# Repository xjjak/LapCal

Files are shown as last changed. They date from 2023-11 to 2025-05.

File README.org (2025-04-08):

[[http://creativecommons.org/licenses/by-nc-sa/4.0/][https://img.shields.io/badge/License-CC%20BY--NC--SA%204.0-lightgrey.svg]]
* LapCal
/by Emil² - Ξ/

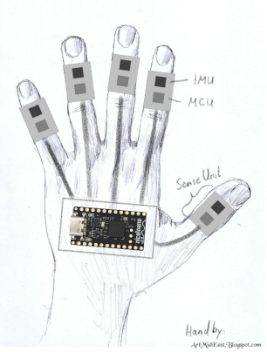
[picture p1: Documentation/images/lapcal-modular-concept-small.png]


We are trying to build data gloves, that enable typing on a 34-key keyboard, without an actual keyboard, based on 6-axis IMU sensors, using machine learning.

** Structure

#+begin_example
LapCal/
├─ Software/
│  ├─ data-collection.org
│  ├─ *machine-learning.org*
├─ Documentation/
├─ Utilities/
│  ├─ keyboard-visualization/
├─ Hardware/
│  ├─ Firmware/
│  ├─ Electronics/
#+end_example

Because we are both Emacs users, we pivoted to writing our READMEs in org-mode, as well as using org-babel for literate programming, to replace jupyter notebooks. More specific documentation can be found in [[/Software/README.org][this README]].

** Approaches
*** Unified Processing
First, we tried to connect all 6 IMUs to the same main-processor, an ESP32. This delivered a mediocre read-out frequency of about 10Hz at best. Collecting data was never done properly using this approach due to trying to use timestamps to sync the sensor and some sort of keyboard state data.

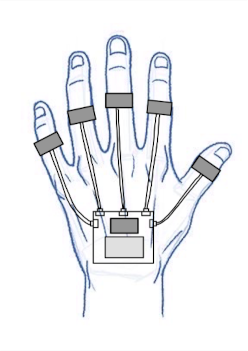
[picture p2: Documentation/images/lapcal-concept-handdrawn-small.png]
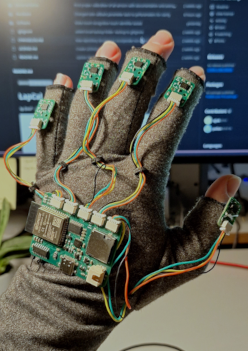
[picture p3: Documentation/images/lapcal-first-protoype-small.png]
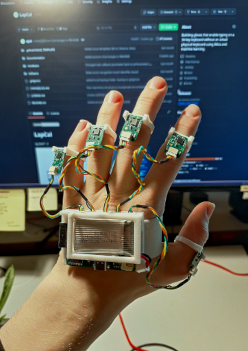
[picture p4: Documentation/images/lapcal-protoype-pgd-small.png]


*** /Now/: Modular
To simplify the problem, and offload computation at the same time, we are now using the constraints of the 34-keyboard, almost forcing each finger to a specific set of keys, and are trying to develop a model that only takes the data of a single finger and maps it to its respective keys. This would then also enable the use of an upgraded version of the SenseUnit (small PCBs with the IMUs on them that are attached to the fingers) with a dedicated processor on them, like an RP2040, perhaps. The mainboard could then be built around a standard keyboard MCU, that is usually used in mechanical keyboards.

** Licensing:

This work is licensed under a
[[http://creativecommons.org/licenses/by-nc-sa/4.0/][Creative Commons Attribution-NonCommercial-ShareAlike 4.0 International License]].

[[http://creativecommons.org/licenses/by-nc-sa/4.0/][https://licensebuttons.net/l/by-nc-sa/4.0/88x31.png]]

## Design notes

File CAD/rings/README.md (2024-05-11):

# Rings for the Partial Glove Design Version

This folder contains the OpenSCAD files for the parametric rings with which the SenseUnits are
attached to the finger.

This implementation utilizes the library [Round-Anything by Irev-Dev](https://github.com/Irev-Dev/Round-Anything).

## Parameters
Available in the code itself or the customizer in OpenSCAD are the following parameters:
- `thumb_dia`: The diameter of the Thumb finger ring
- `index_dia`: The diameter of the Index finger ring
- `middle_dia`: The diameter of the Middle finger ring
- `ring_dia`: The diameter of the Ring finger ring
- `pinky_dia`: The diameter of the Pinky ring
- `thumb hole width`: The angle of the thumb hole
- `thumb hole angle`: The angle which the thumb hole is set off by

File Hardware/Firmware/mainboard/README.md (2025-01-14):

# Mainboard firmware

## Build flags
- `RIGHT_HAND`: Set to `1` to reverse sensor order for right hand, `0` for the left hand. Throws error if not specified
- `MULT_CORE`: Set to `0` to disable parallel buffer resets, `1` to enable. Defaults to `1`.
- `BLE`: Set to `0` to output sensor data to Serial Monitor, `1` enables ble server and data transmission (Requires MULT_CORE=0)

## Setting build flags
### PlatformIO environments
The easiest method (and safest) is using the available pio environments:
- `left` / `right` : Data is printed to serial monitor (MULT_CORE=0)
- `left-ble` / `right-ble` : (BLE=1 MULT_CORE=0)
by using `pio run -e [left/right/left-ble/right-ble]`.
Defaults to `left` when `-e` is omitted.

*(left/right refers to the targeted hand)*

###  Environment variable override
To customize build flags when needed, prepend something like:
`PLATFORMIO_BUILD_FLAGS="-DMULT_CORE=[0/1] -DBLE=[0/1] -DRIGHT_HAND=[0/1]`
to a pio run command.
Any Flag that can stay the same as in the environment can be omitted.
This should override potentially differing flags set in the environment.

## BLE Server 
When BLE is enabled the ESP32 acts as an BLE Server providing
- Service with uuid: `f5aea478-9ec3-4bcf-af20-7f75e7c68c9d`
- Characteristic with uuid: `68bf07fb-d00b-4c80-a796-f8be82b5dea`

The name the device will show up under depends on the hand:
- left: `lapcal left`
- right: `lapcal right`

The data is in a binary format:
- timestamp: `uint64_t`
- Values: `int16_t` for each value of each sensor (36) 
  *caution: signed integer*
  
Use with the ble-receiver script found in the `Software/tools` folder.

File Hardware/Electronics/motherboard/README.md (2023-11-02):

### Libraries 
 - https://www.snapeda.com/parts/TCA9548APWR/Texas%20Instruments/view-part/?welcome=home
 - https://github.com/espressif/arduino-esp32/tree/master/libraries/SD

### Knowledge
 - https://hackaday.com/2017/05/18/kicad-best-practises-library-management/
 - https://esp32.com/viewtopic.php?t=356
 - https://www.esp32.com/viewtopic.php?t=1948
 - https://randomnerdtutorials.com/esp32-pinout-reference-gpios/
 - https://www.reddit.com/r/KiCad/comments/bnsbrr/flat_solder_pad_footprint_not_drilled/ -> These types of pads are called "Test Points"
 - Differential pairs: - https://resources.altium.com/p/what-are-differential-pairs-and-differential-signals
                       - Tips and "examples": https://electronics.stackexchange.com/questions/540263/routing-usb-3-x-type-c-signals
 - How to handle thermal pad on esp32: https://esp32.com/viewtopic.php?t=1864
 - 

### Models
- https://grabcad.com/library/hro-usb-type-c-31-m-14-1

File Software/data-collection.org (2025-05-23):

#+title: Data Collection and Preprocessing

#+property: header-args:jupyter-python :session *jupyter* :eval no-export
#+OPTIONS: ^:nil h:6

This document describes all software related to data collection, when possible in a literate programming style.

Except for the [[*A Brief Description of Our Data][first chapter]] -- a broad descrpition of how our data will look for all datasets -- and the [[*The Data Collection Process][second chapter]] -- a description of the general collection process --, the chapters are organized by dataset type. Each dataset type chapter includes all relevant
- descriptions and design choices,
- software to collect the relevant data, and
- processing capabilities to convert raw data into refined datasets.

Notably, the dataset types mostly vary by how we collect the [[*Labels][labels]].

* Contents                                                         :noexport:
:PROPERTIES:
:TOC:      :include all :ignore (this)
:END:

# TOC automattically generated by [[https://github.com/alphapapa/org-make-toc]]
# NOTE: These links will *only* work on github.
:CONTENTS:
- [[#a-brief-description-of-our-data][A Brief Description of Our Data]]
  - [[#features][Features]]
  - [[#labels][Labels]]
- [[#the-data-collection-process][The Data Collection Process]]
- [[#collecting-data][Collecting Data]]
  - [[#capturing-keypresses-directly-from-the-keyboard][Capturing Keypresses Directly from the Keyboard]]
    - [[#description][Description]]
      - [[#raw-data][Raw Data]]
      - [[#dataset][Dataset]]
    - [[#keypresses-directly-from-the-keyboard][Keypresses Directly from the Keyboard]]
    - [[#rectify-errors][Rectify Errors]]
      - [[#find-errors][Find Errors]]
      - [[#fix-errors][Fix Errors]]
    - [[#a-look-at-the-data][A Look at the Data]]
    - [[#center-the-data][Center the Data]]
      - [[#a-visual-comparison-to-the-uncentered-data][A Visual Comparison to the Uncentered Data]]
      - [[#save-data][Save Data]]
    - [[#aggregate-features-and-labels][Aggregate Features and Labels]]
      - [[#features][Features]]
        - [[#change-based-features][Change-based Features]]
        - [[#history-based-features][History-based Features]]
      - [[#labels][Labels]]
    - [[#write-dataset][Write Dataset]]
:END:

* A Brief Description of Our Data
Before we start describing the software that is used in the data collection process, we first want to give a quick overview of what our data actually consist of and where it comes from.

The data we collect can broadly be divided into two categories, since we use supervised learning:
1. The [[*Features][features]] our model takes as input. These are necessary during training and deployment of the model.
2. The [[*Labels][labels]] our model produces as output. These are only necessary during training. During deployment the model itself will produce predictions for them.

** Features
The features are generated using the hardware developed in [[file:../Hardware][other parts of the project]] in a more or less straightforward. While the specifics might change, in general the data will always come from [[https://en.wikipedia.org/wiki/Inertial_measurement_unit][inertial measurement units]] on the fingers and the back of the hand. The IMUs we currently use (MPU6050) give us information about their current acceleration in all three spatial dimensions as well as their rotation, that is, yaw, pitch, and roll.

In some cases the data will be explicitly limited to a subset of all the available sensors, most prominently to just one sensor.

Further, we need to convert our sequential data into features that encapsulate temporal changes. For example, one option would be to concatenate a set number of successive data points into one feature, like a [[https://www.geeksforgeeks.org/window-sliding-technique/][sliding window]].

# TODO: why here and not in machine-learning.org?
#   avoid high volatility of datasets in machine-learning.org since
#   models can be sensitive to changes in dataset architecture.

** Labels
The labels we assign to our collected features, represent some kind of typing state. A typing state considers every physical key on a [[https://github.com/davidphilipbarr/Sweep][keyboard]] separately. But what a typing state associates to a key can differ depending on the use case:
- in some cases, we just collect whether keys were changed from an unpressed to a pressed state, (states: =UNCHANGED=, =PRESS=, =RElEASE=)
- in other cases, we collect the state of the keys themselves, that is, whether they are pressed or not. (states: =UNPRESSED=, =PRESSED=)

It is important to note that feature labels are /not necessarily unique/ and labelling should be done with caution to avoid issues arising from feature representation like the following: When using a sliding window and not careful when labelling, a single key press can cause a model recognizing press and release events fire twice. An example for a sliding window with size 5 might look like the following for two consecutive model inputs:
  #+begin_example
  [ 5  4  3  2  1 ] => Prediction: PRESS event
       ^            <- key press event
       
  [ 6  5  4  3  2 ] => Prediction: PRESS event
          ^         <- key press event
  #+end_example

Often, we only consider a subset of all possible key on our [[https://github.com/davidphilipbarr/Sweep][keyboard]], like for example only keys reachable by a certain finger or only one half of the keyboard. The reason for doing so is usually the assumption that the labels can be partitioned in such a way that different models can separately predict events independently from one another. Analogously, for some datasets we leave some features out since we assume that they don't affect the subset of labels we look at.

For some experiments, it could also be interesting to further simplify certain models, e.g. no differentiation between different keys pressed by a key, but these are *not accounted* for in this document since they are usually quick modifications that mostly serve experimental purposes.

* TODO The Data Collection Process
/This section is currently empty. In the future some general approaches to data collection might be listed here./

# TODO: python version + package management

* Collecting Data
This is the main part of this document. In this chapter, the [[*The Data Collection Process][general process]] for collecting data is adapted to our specific needs resulting in the actual datasets.

** TODO Capturing Keypresses Directly from the Keyboard
:PROPERTIES:
:header-args:jupyter-python: :async yes :session *jupyter-keyboard-direct*
:END:
*WARNING*: For the moment, this chapter /only describes data pertaining quick taps/, explicitly /excluding the handling of hold events/ and as such press and release events.

#+begin_src jupyter-python :results silent
  import pandas as pd
  import numpy as np
  from pathlib import Path
  data_path = Path("_datasets/2025-01-15_controlled-taps")
  
  import matplotlib.pyplot as plt
  %matplotlib inline
#+end_src

# TODO: raw data or dataset files?
Dataset files:

*** Description
***** Raw Data
  File: [[file:_datasets/2025-01-15_controlled-taps.csv][2025-01-15_controlled-taps.csv]] (4.6Mb, 151471 lines, semicolon separated)
  
  Data was recorded by [[https://github.com/xjjak/][@xjjak]] on <2025-01-15 Wed> over a time of around 10 minutes using sensor #I [fn::#I refers to the physical label of the used sensor.] with the following calibration offsets ={-6018, 1394, 1385, 66, -86, 35}=. The recorded typing motions only contain *short taps* from the middle finger. During the recording, taps were performed in varying frequencies from different starting positions [fn::The position in which the finger rested before performing the tapping motion.] and the order in which the reachable keys were pressed also varies. To ensure consistency, the controller was reset with a brief waiting period beforehand.

  As a result of the recording methodology, there should only be three + one possible key states:
  - lower row, home row, upper row, as well as
  - no key pressed
  The data represents these in a binary format, i.e., the possible states are 0, 1, 2, and 4. Though, other values are technically possible, these are errors and should if possible (it often is) be fixed before proceeding.

  Similarly, only the data collected from one sensor was included. This especially means that there is no data from the sensor on the back of the hand.

  # TODO: format?
  
***** TODO Dataset
      
*** TODO Keypresses Directly from the Keyboard
# TODO: links to relevant code
# TODO: check for correctness (@xjjak)
To collect keypress data directly from the keyboard, we inject some firmware code into the keyboards firmware, that sends key events to an external controller (the project hardware?) via unused pins on the keyboards microcontroller.

*** Rectify Errors
Before we can recitify errors, we first need to be aware of what errors are. In this case, there are two kind of errors to consider -- we will only handle the latter:
1. *Sensor failure*: Sometimes the firmware fails to read data from the sensor or the data it reads doesn't really make any sense. But these kinds of errors are hard to sensibly rectify. Instead, it is often more reasonable to omit data around the errors or to let the machine learning algorithm handle the errors. For now, we will not handle them.
   # TODO: do we check for them? (ig prob should via histogram)
2. *Key event error*: This error is not a technical error per se but a result of typing inprecision. Sometimes multiple pressed keys are recognised, when only one was actually supposed to be pressed. This is the kind of error we can mostly fix because such a multikey press implies that the intended key is one of the recognised presses and the actual press is at the border of both of them.

The next step would be to find those errors in the raw data and handle them -- if appropriate.

**** Find Errors
First, we need to load the data. We do this using [[https://pandas.pydata.org/][pandas]].

#+begin_src jupyter-python :noweb no-export
  # Load the dataset using pandas
  df = pd.read_csv(data_path/'raw.csv', sep=';', dtype=np.float64)
  df.dtypes
#+end_src

#+RESULTS:
: kb_state    float64
: ax          float64
: ay          float64
: az          float64
: gx          float64
: gy          float64
: gz          float64
: dtype: object

Since =kb_state= -- unlike the other columns -- is not a float but an integer value, we reflect this in our data frame.

#+begin_src jupyter-python :noweb no-export
  df = df.astype({'kb_state': np.int64})
  df.dtypes
#+end_src

#+RESULTS:
: kb_state      int64
: ax          float64
: ay          float64
: az          float64
: gx          float64
: gy          float64
: gz          float64
: dtype: object

To avoid some common binary writing/reading problems at the start of the file, we discard the first data row. This is also the first intermediary result we save since that makes it easy to load and work with it using pandas.

#+begin_src jupyter-python :results silent
  df.drop(index=df.index[0], inplace=True)
  df.reset_index(drop=True, inplace=True)
  df.to_csv(data_path/'formatted.csv', index=False)
#+end_src

The raw data consists of a list of readings. These however do not include enough context, to detect all erroneous readings and fix the errors. Instead of the readings themselves, we consider /taps/. As a tap, we understand a maximally long sequence of consecutive readings with nonzero keyboard states.

#+begin_src jupyter-python :results silent
  # Get starting (inclusive) and ending (exclusive) index of reading
  # around given reading.
  def get_tap_around(reading_idx, df):
      # check if inside tap
      assert df.kb_state[reading_idx] != 0
      
      i = reading_idx
      while i > 0 and df.kb_state[i-1] != 0:
          i -= 1
      a = i
      while i < len(df) and df.kb_state[i] != 0:
          i += 1
      b = i
      
      return a, b
#+end_src

To check the taps for errors, we first need to extract all taps from the given data.

#+begin_src jupyter-python :results silent
  idx = 0
  taps = list()
  while idx < len(df):
      if df.kb_state[idx] != 0:
          tap = get_tap_around(idx, df)
          taps.append(tap)
          idx = tap[1]
      else:
          idx += 1
#+end_src

Next, we identify the erroneous ones. As outlined in the [[*A Brief Description of Our Data][data description]], the only valid /keyboard states/ (first column in the raw data file) are 0, 1, 2, and 4 -- i.e., 000, 001, 010, and 100 in binary. Invalid keyboard states would consequently be 3 (011), 5 (101), 6 (110), and 7 (111). Thus, all taps that contain any invalid keyboard states are erroneous. A tap is also faulty when it contains multiple valid keyboard states, since one tap should also only hit one key. We write the following function to validate taps.

#+begin_src jupyter-python :results silent
  valid_keyboard_states = [0, 1, 2, 4]
  def is_tap_valid(tap, df):
      return len(set(map(lambda i: df.kb_state[i], range(*tap)))) == 1 \
          and df.kb_state[tap[0]] in valid_keyboard_states
#+end_src

Using the function we can filter for invalid taps.

#+begin_src jupyter-python :exports both
  taps_err = list(filter(lambda tap: not is_tap_valid(tap, df), taps))
  
  # Print overview of all erroneous taps
  print("Erroneous taps:")
  for tap in sorted(taps_err):
      start, end = tap
      states = set()
      for j in range(start, end):
          states.add(df.kb_state[j])
      print(f"  from {tap[0]:6d} to {tap[1]:6d} with states: {', '.join(map(str, states))}")

#+end_src

#+RESULTS:
: Erroneous taps:
:   from  23626 to  23639 with states: 2, 4, 6
:   from  50181 to  50205 with states: 2, 6
:   from  53461 to  53482 with states: 2, 6
:   from  62912 to  62925 with states: 2, 3
:   from 106847 to 106860 with states: 2, 6
:   from 126433 to 126451 with states: 2, 6
:   from 134939 to 134955 with states: 2, 6

**** Fix Errors
To fix these issues, we have to come up with a strategy for reassigning these multiple, possibly invalid states into one state per tap. The strategy we employ works the following way:
- When there is *at least one valid state*, we assign the first valid state to the tap.
- When there is *only one invalid state*, we assign the state to the tap that corresponds to the non-homerow key that is part of the invalid state.
- /Other situations are not covered for now, since we do not encounter them./

#+begin_src jupyter-python :results silent
  reassignments = dict()

  for tap in taps_err:
      start, end = tap
      contains_valid = False
      for i in range(start, end):
          if df.kb_state[i] in valid_keyboard_states:
              assignment = df.kb_state[i]
              contains_valid = True
              break
      if not contains_valid:
          if df.kb_state[start] & 1:
              assignment = 1
          elif df.kb_state[start] & 4:
              assignment = 4
          else:
              assignment = 2

      reassignments[tap] = assignment
#+end_src

Now we need to apply these reassignments. When a tap is assigned to a certain keyboard state, applying that assignment just means to set the keyboard state of every reading in the tap to the assigned state.

#+begin_src jupyter-python :results silent
  for tap, assignment in reassignments.items():
      start, end = tap
      for i in range(start, end):
          df.loc[0,"kb_state"] = assignment
#+end_src

Lastly, we write the data to an intermediary file.

#+begin_src jupyter-python :results silent
  df.to_csv(data_path/'fixed.csv', index=False)
#+end_src

*** A Look at the Data
# TODO: Sections from here on onwards should not depend on the previous section having run.
This section works with the data generated by the [[*Rectify Errors][previous section]].
#+begin_src jupyter-python
  df = pd.read_csv(data_path/'fixed.csv')
  df.dtypes
#+end_src

#+RESULTS:
: kb_state      int64
: ax          float64
: ay          float64
: az          float64
: gx          float64
: gy          float64
: gz          float64
: dtype: object

Before we continue to aggregate the data into feature vectors, we want to take a quick look at the data using [[https://matplotlib.org/stable/api/_as_gen/matplotlib.pyplot.hist.html][histograms with matplotlib]].

First, we look at the the distribution of keyboard states.

#+header: :file diagrams/2025-01-15_controlled-taps_histogram-keyboard-states.png
#+begin_src jupyter-python :results output :exports both
  unique, counts = np.unique(df.kb_state, return_counts=True)
  plt.bar(unique, counts, label="kb_state")
  plt.legend(prop={'size': 10})
  plt.title('histogram of keyboard states')
#+end_src

#+RESULTS:
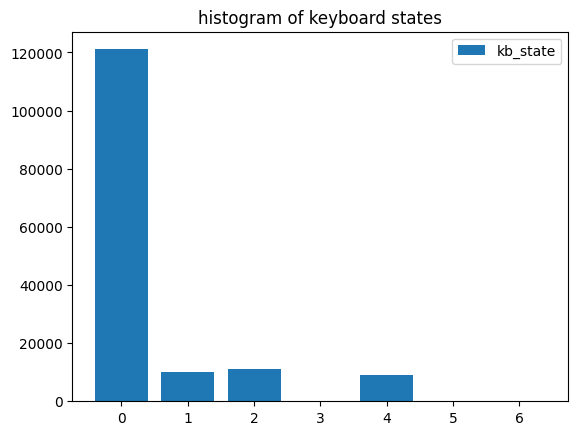
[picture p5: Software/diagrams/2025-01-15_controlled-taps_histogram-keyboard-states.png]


As expected, the majority of states are resting states and fortunately the other states seem equally frequent.

Next, we look at the acceleration data.

#+header: :file diagrams/2025-01-15_controlled-taps_histogram-acceleration.png
#+begin_src jupyter-python :results output :exports both
  labels = ['ax','ay','az']
  plt.hist(df[labels], bins=100, density=True, label=['ax','ay','az'], histtype='stepfilled')
  plt.legend(prop={'size': 10})
  plt.title('histogram of acceleration data')
#+end_src

#+RESULTS:
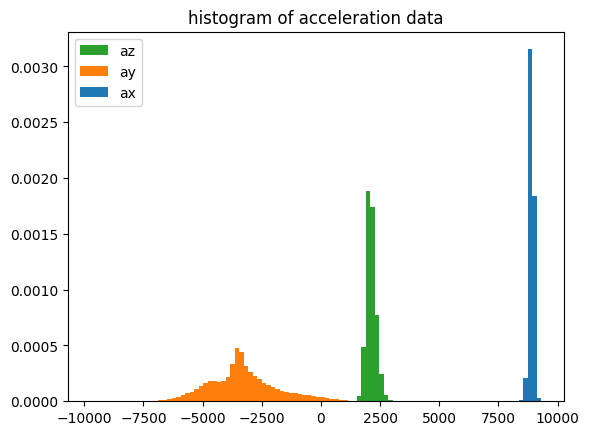
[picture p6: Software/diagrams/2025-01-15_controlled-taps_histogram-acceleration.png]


The first thing we notice is that the calibration does not seem to work that well but this is something we have come to expect since the absolute values seem to drift unpredictably over time. Apart from that, we also notice that =ax= and =az= seem to be distributed normally with little variation, unlike =ay= which is distributed much more broadly and seemingly also not in a normal distribution. This could indicate, that =ay= could play an important role detecting taps. We also, notably, don't see any significant amount noise which is good.

Lastly, we look at the rotation data.

#+header: :file diagrams/2025-01-15_controlled-taps_histogram-rotation.png
#+begin_src jupyter-python :results output :exports both
  labels = ['gx','gy','gz']
  plt.hist(df[labels], bins=100, density=True, label=labels, histtype='stepfilled')
  plt.legend(prop={'size': 10})
  plt.title('histogram of rotation data')
#+end_src

#+RESULTS:
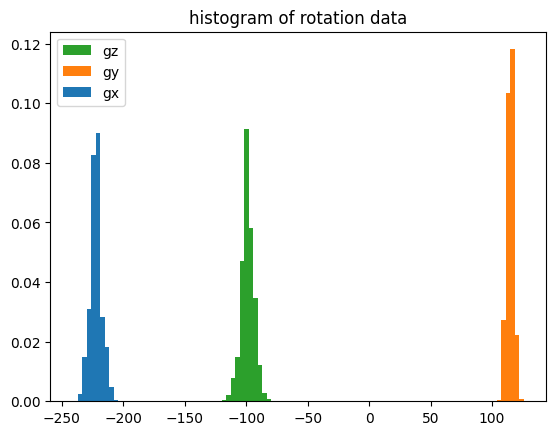
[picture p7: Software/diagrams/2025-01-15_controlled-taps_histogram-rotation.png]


For the rotation data we also fortunately do not observe any significant amount of noise. All rotation axes seem to be normally distributed which we expect since any variation from typing on different keys should be observed equally frequent on both ends. Also, =gx= and =gz= are distributed slightly more broadly than =gy= which might indicate that these are the axes that the finger rotates around while typing.

*** Center the Data
This section also works with the data from the [[*Rectify Errors][first section]].
#+begin_src jupyter-python
  df = pd.read_csv(data_path/'fixed.csv')
  df.dtypes
#+end_src

#+RESULTS:
: kb_state      int64
: ax          float64
: ay          float64
: az          float64
: gx          float64
: gy          float64
: gz          float64
: dtype: object

As we saw in [[*A Look at the Data][A Look at the Data]], the sensor calibration is not reasonable reliable over the long term, drifts accumulate over time and calibrating the sensors every time you want to use the device is infeasible. Instead, we want to try dynamic calibration: The first approach that comes to mind is to keep some sort of average that favors more recent data, like a [[https://en.wikipedia.org/wiki/Moving_average][moving average]]. We want to try to use the [[https://en.wikipedia.org/wiki/Exponential_smoothing][exponantial moving average]].

# TODO: check correctness
#+begin_src jupyter-python :async yes :results silent
  %%time
  def center_moving_average(df, alpha=0.995):
      df = df.copy()
      df.iloc[:,1:] = df.iloc[:,1:] - df.iloc[:,1:].ewm(alpha=1-alpha).mean()
      return df

  df_center = center_moving_average(df, alpha=0.995)
#+end_src

**** A Visual Comparison to the Uncentered Data
We want the exponential moving average to approximate the real average of the data. The closer we get to that, the more similar the distribution should look to the uncentered distribution. Essentially, the moving average should only act as a global shift as much as possible.

#+name: compare_ema
#+begin_src jupyter-python :results output :exports code :var alpha=0.95 column="ay"
  df_tmp = center_moving_average(df, alpha=alpha)
  plt.hist(
      [df_tmp.loc[:,column], (df - df.mean()).loc[:,column]],
      bins=50,
      label=[column + " (EMA)", column + " (centered)"],
      histtype='step',
      linewidth=2
  )
  plt.legend(prop={'size': 10})
  plt.title(f'histogram of acceleration data (alpha={alpha})')
#+end_src

#+RESULTS: compare_ema


# TODO: does not render in github.

Quick comparison of different averaging weights with =column=2=:
- =alpha=0.5=
  #+call: compare_ema[:file diagrams/ema_centering/compare_0-5.png :exports results](alpha=0.5)

  #+RESULTS:
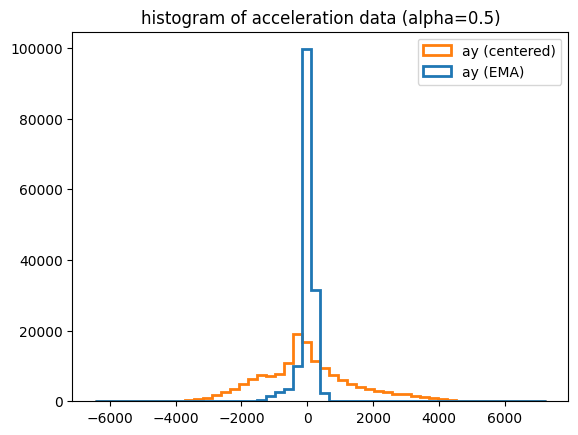
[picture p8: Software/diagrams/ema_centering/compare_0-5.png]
  
  
- =alpha=0.8=
  #+call: compare_ema[:file diagrams/ema_centering/compare_0-8.png :exports results](alpha=0.8)

  #+RESULTS:
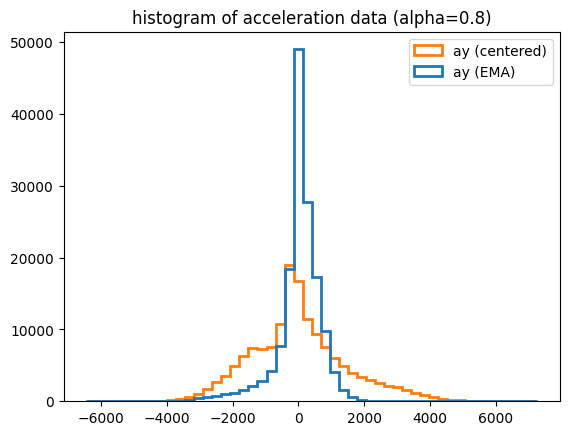
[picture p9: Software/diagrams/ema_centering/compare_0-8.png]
  
  
- =alpha=0.9=
  #+call: compare_ema[:file diagrams/ema_centering/compare_0-9.png :exports results](alpha=0.9)

  #+RESULTS:
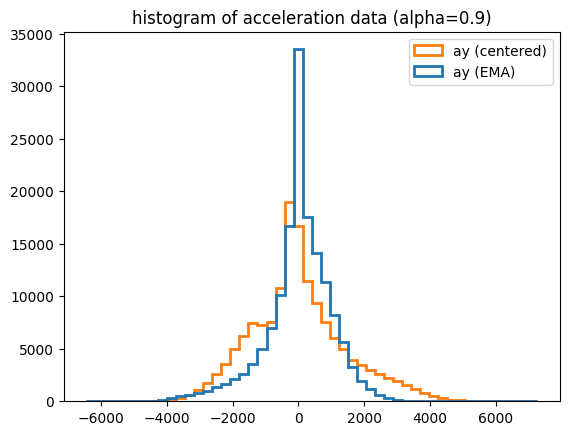
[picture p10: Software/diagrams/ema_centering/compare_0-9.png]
  
  
- =alpha=0.95=
  #+call: compare_ema[:file diagrams/ema_centering/compare_0-95.png :exports results](alpha=0.95)

  #+RESULTS:
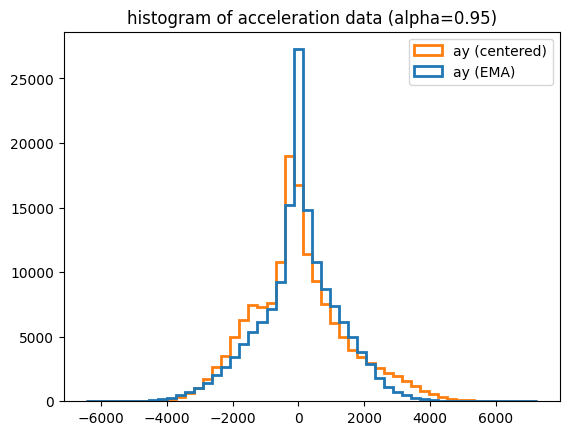
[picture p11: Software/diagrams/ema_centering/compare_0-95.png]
  
  
- =alpha=0.99=
  #+call: compare_ema[:file diagrams/ema_centering/compare_0-99.png :exports results](alpha=0.99)

  #+RESULTS:
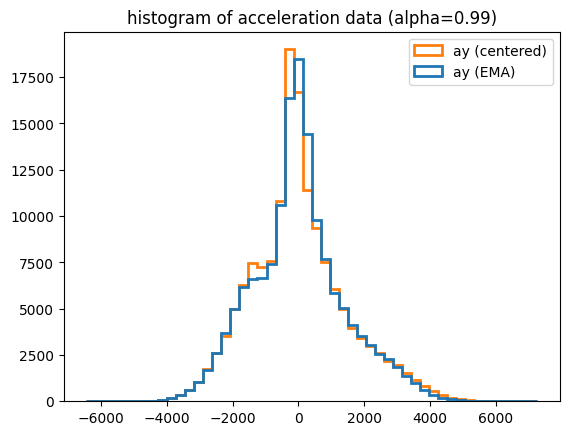
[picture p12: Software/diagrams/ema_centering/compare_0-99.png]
  
  
- =alpha=0.995=
  #+call: compare_ema[:file diagrams/ema_centering/compare_0-995.png :exports results](alpha=0.995)

  #+RESULTS:
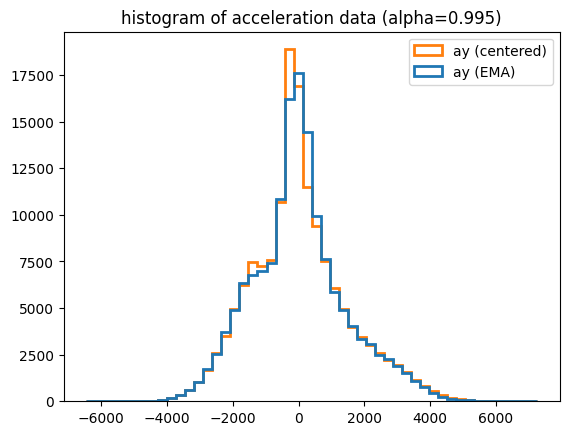
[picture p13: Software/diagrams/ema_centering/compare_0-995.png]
  

Since choosing =alpha=1= would just shift the all the data by the first value -- which is not reliable as a measure to center the data -- =alpha=0.995= gets us most similar fit. This also means that every new reading gets about as much weight as it would if we were to center a second worth of readings, since we read about src_jupyter-python{len(df)//(10*60)} {{{results(=252=)}}} readings per second (assuming a recording time of 10 min).

Taking a closer look at all the sensor readings, we get the following comparison.

#+name: compare-center
#+header: :var alpha=0.995 start=15000 end=17000 column="ay"
#+begin_src jupyter-python :results output :exports code
  df_tmp = center_moving_average(df, alpha=alpha)
  fig, axs = plt.subplots(3, 1, sharex=True, height_ratios=(10,10,3))
  axs[0].plot(np.arange(start, end), df.loc[start:end-1,column], label=column)
  axs[0].plot(np.arange(start, end), (df - df_tmp).loc[start:end-1,column], label=column + " (EMA)")
  axs[0].plot([start, end], [df.mean()[column], df.mean()[column]], label=column+" (mean)")
  axs[1].plot(np.arange(start, end), df_tmp.loc[start:end-1,column], label=column+" (centered)")
  axs[2].step(
      np.arange(start, end),
      np.minimum(df.kb_state[start:end], 3),
      label="taps",
  )
  axs[2].set_ylim([0, 3.5])
  axs[2].set_yticks([0, 1, 2, 3])
  axs[0].legend(prop={'size': 7}, bbox_to_anchor=(1.0, 1.0))
  axs[1].legend(prop={'size': 7}, bbox_to_anchor=(1.0, 1.0))
  axs[2].legend(prop={'size': 7}, bbox_to_anchor=(1.0, 1.0))
#+end_src

#+RESULTS: compare-center


For the following comparison we set =alpha=0.995=, =start=15000=, and =end=17000=
- ~column="ax"~:
  #+call: compare-center[:file diagrams/ema_centering/compare-center_1.png :exports results](column="ax")

  #+RESULTS:
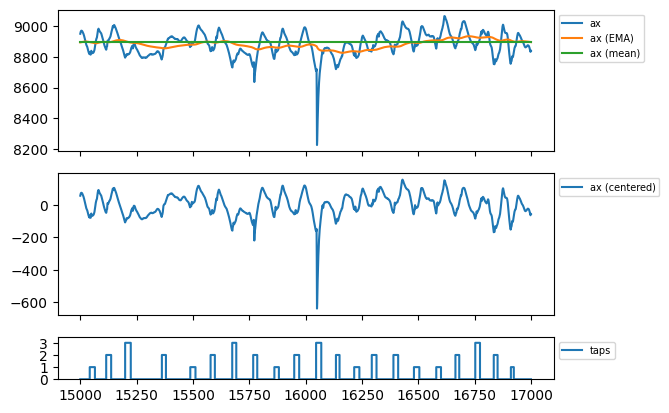
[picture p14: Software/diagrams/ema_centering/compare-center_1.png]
  
  
- ~column="ay"~:
  #+call: compare-center[:file diagrams/ema_centering/compare-center_2.png :exports results](column="ay")

  #+RESULTS:
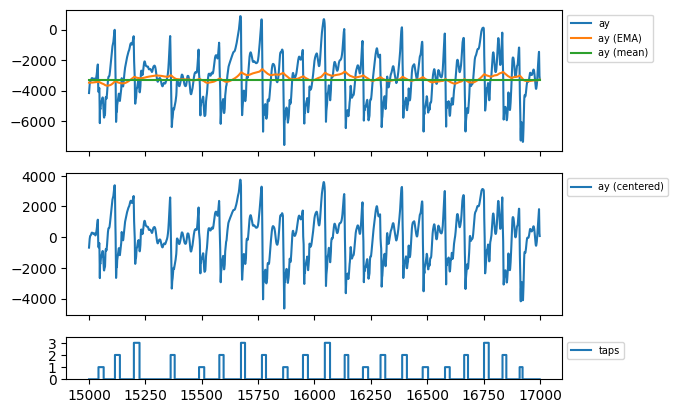
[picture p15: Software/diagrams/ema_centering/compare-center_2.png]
  
   
- ~column="az"~:
  #+call: compare-center[:file diagrams/ema_centering/compare-center_3.png :exports results](column="az")

  #+RESULTS:
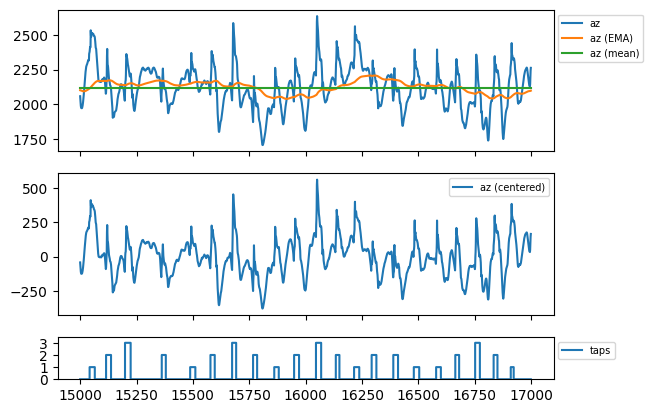
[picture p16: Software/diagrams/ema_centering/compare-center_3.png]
  
   
- ~column="gx"~:
   #+call: compare-center[:file diagrams/ema_centering/compare-center_4.png :exports results](column="gx")

  #+RESULTS:
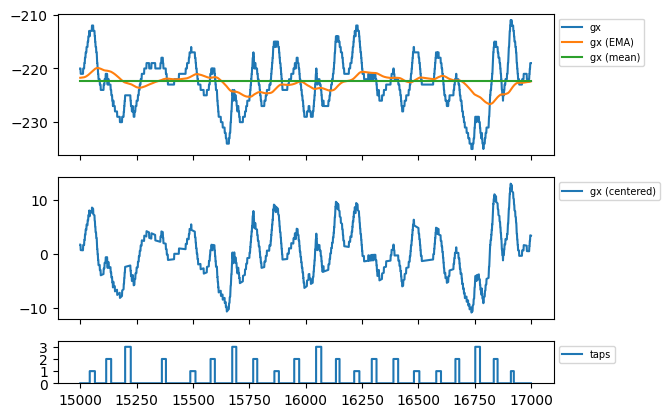
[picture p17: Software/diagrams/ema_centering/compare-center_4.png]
  
   
- ~column="gy"~:
  #+call: compare-center[:file diagrams/ema_centering/compare-center_5.png :exports results](column="gy")

  #+RESULTS:
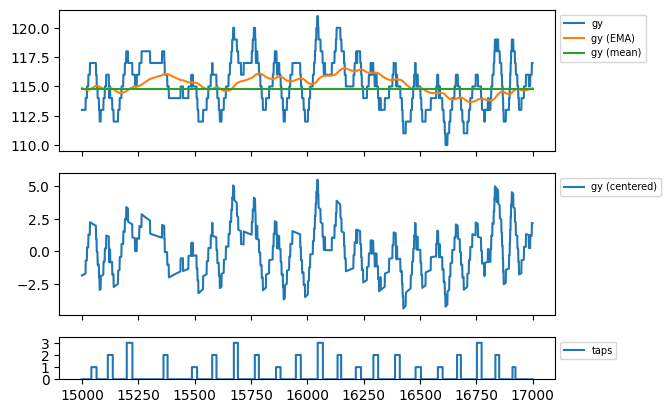
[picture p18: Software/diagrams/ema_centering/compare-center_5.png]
  
   
- ~column="gz"~:
  #+call: compare-center[:file diagrams/ema_centering/compare-center_6.png :exports results](column="gz")

  #+RESULTS:
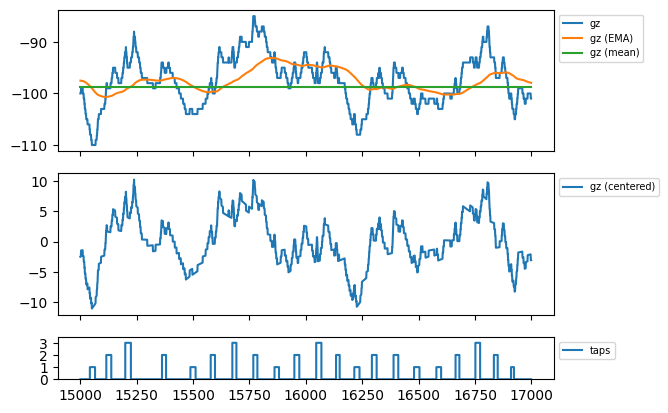
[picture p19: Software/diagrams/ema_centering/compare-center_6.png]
  

We notice that the average is pretty reliable for the acceleration data, but for the rotation data we see more fluctuations in the average and it is not clear how that might affect learning.

# TODO: should we center rotations?

**** Save Data
The centered data is another intermediary step we want to save.

#+begin_src jupyter-python :results silent
  df_center.to_csv(data_path/'centered.csv', index=False)
#+end_src

*** TODO Aggregate Features and Labels
# TODO(!): update to use pandas
**** TODO Features
Every feature needs to encompass information about the state of the sensor as well as its immediate history. This is necessary to enable the model to detect changes in the sensor readings since two resting positions cannot be reliably differentiated even if one is in the air and the other on the table.

To add history information to our features, we consider two kinds of additional features:
- the *change* of every sensor value compared to its predecessor; if more history is necessary one could also add the *change of the change* and so on. (a form of discrete numerical differentiation)
- the *history* itself, i.e., we just add the previous sensor reading to our feature vector. For more history we can just add more readings.
  
Both approaches have their own set of benefits and drawbacks. We list some here:
- Simpler models might work better on change than on history values.
- Normalization techniques might affect the information in change values since they are dependent on other values in the feature vector. This might not necessarily a problem though, since it might be enough to just compare them in relation to other change values.
  
The conclusion here seems to be, that change values are more suitable for simpler models, especially if they work well without normalization, and that history values are the better choice for more complex models, like neural networks, and strongly benefit from normalization and through their complexity can consider change values implicitly on their own. Thus, we will prepare both datasets for further experimentation.

***** Change-based Features
# TODO: degree as org variable?

Before we can create change-based features, we first need to decide the /degree/, i.e., how many levels of change we include.

#+begin_src jupyter-python :results silent
  N_DEGREE = 5
  N_SENSOR_DIMS = 6
#+end_src

Then, we can create our feature vectors. We assume that higher levels of change can be initialized with zeros for the first few features vectors which corresponds to the absence of sensor movement which should be compatible with the data collection methodology.
# Should the first N_DEGREE be included? Assuming no change seems somewhat reasonable

#+begin_src jupyter-python :results silent
  features_ct_change = np.zeros((len(data_ct), N_DEGREE * N_SENSOR_DIMS))
  for d in range(N_DEGREE):
      features_ct_change[d, 0:N_SENSOR_DIMS] = data_ct[d,1:]

  for i in range(len(data_ct)):
      for d in range(min(N_DEGREE, i+1)):
          if d == 0:
              features_ct_change[i, 0:N_SENSOR_DIMS] = data_ct[i,1:]
          else:
              previous = features_ct_change[i-1, (d-1)*N_SENSOR_DIMS:d*N_SENSOR_DIMS]
              current  = features_ct_change[i, (d-1)*N_SENSOR_DIMS:d*N_SENSOR_DIMS]
              features_ct_change[i, d*N_SENSOR_DIMS:(d+1)*N_SENSOR_DIMS] = current - previous
#+end_src

***** History-based Features
# TODO: degree as org variable?

Similarly to the change-based features, the history-based features also need a degree -- in this case the number of previous readings to include.

#+begin_src jupyter-python :results silent
  N_DEGREE = 5
  N_SENSOR_DIMS = 6
#+end_src

With that, we can create the feature vectors. This time we discard the first =N_DEGREE= of potential feature vectors. Alternatively, we could also duplicate the first reading =N_DEGREE= times to achieve a similar effect to what we did for [[*Change-based Features][change-based feature vectors]].

#+begin_src jupyter-python :results silent
  features_ct_history = np.zeros((len(data_ct)-N_DEGREE, N_DEGREE * N_SENSOR_DIMS))
  for d in range(N_DEGREE):
      features_ct_history[0, d*N_SENSOR_DIMS:(d+1)*N_SENSOR_DIMS] = data_ct[N_DEGREE-d-1,1:]

  for i in range(1, len(data_ct)-N_DEGREE):
      for d in range(N_DEGREE):
          if d == 0:
              features_ct_history[i, 0:N_SENSOR_DIMS] = data_ct[N_DEGREE+i,1:]
          else:
              previous = features_ct_history[i-1, (d-1)*N_SENSOR_DIMS:d*N_SENSOR_DIMS]
              features_ct_history[i, d*N_SENSOR_DIMS:(d+1)*N_SENSOR_DIMS] = previous
#+end_src

**** TODO Labels
*** TODO Write Dataset

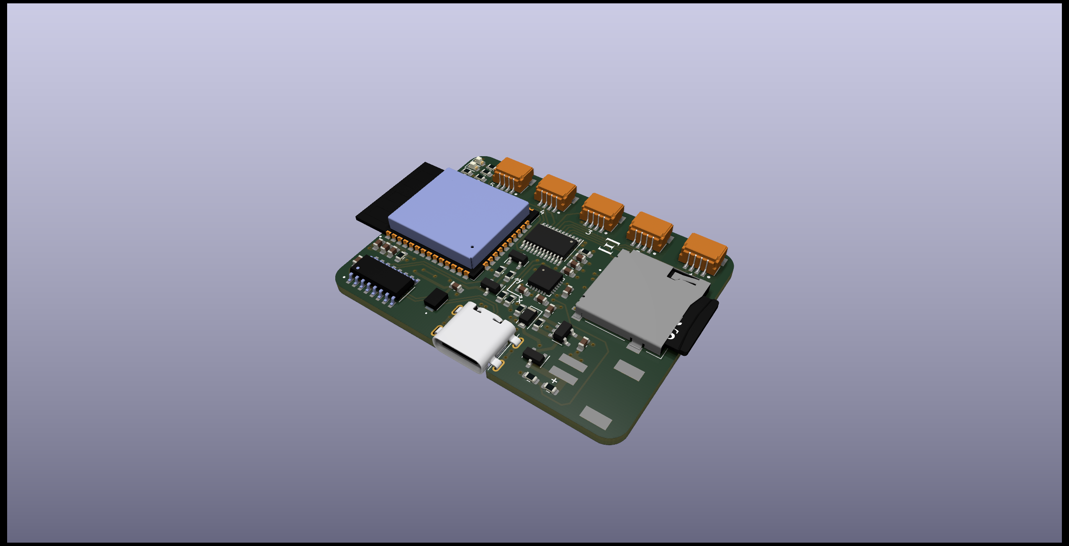
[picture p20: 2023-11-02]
Documentation/images/motherboard_3dangle.png

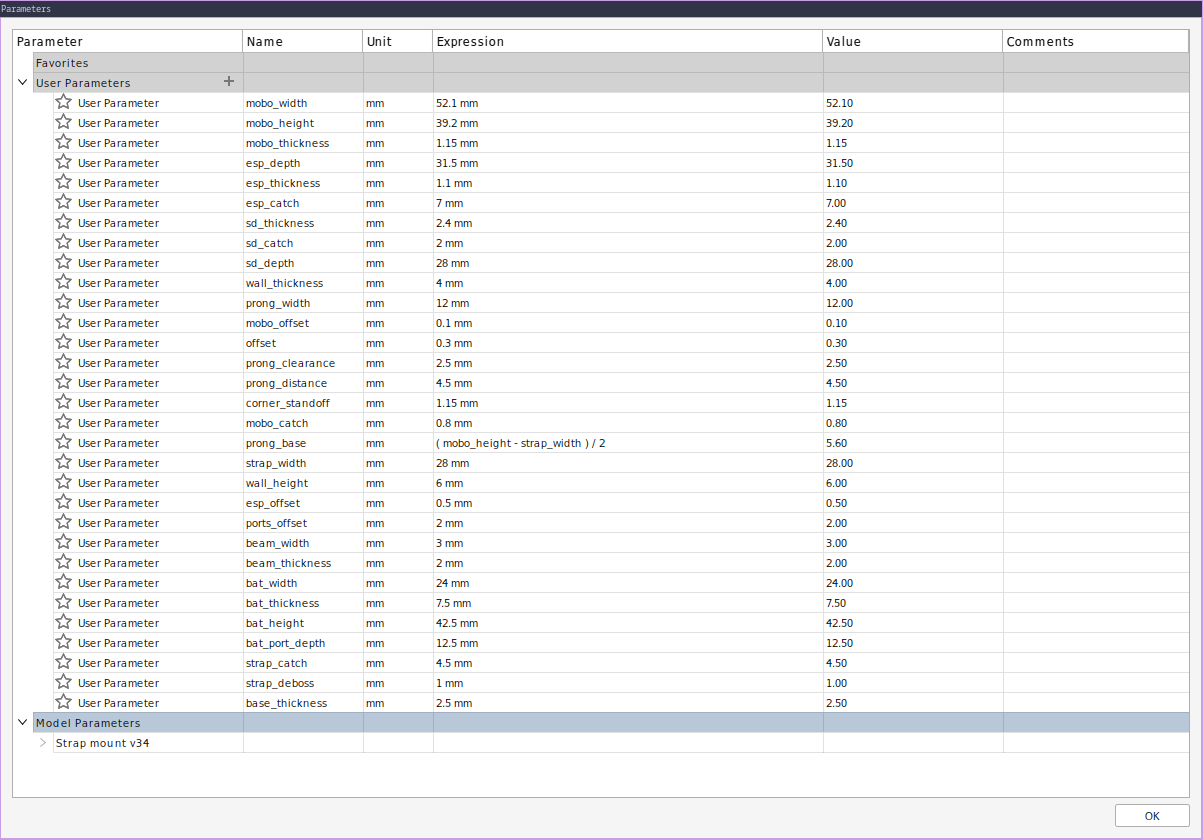
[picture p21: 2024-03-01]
Documentation/images/2023-12-17_mobo-strap-mount-parameters.png

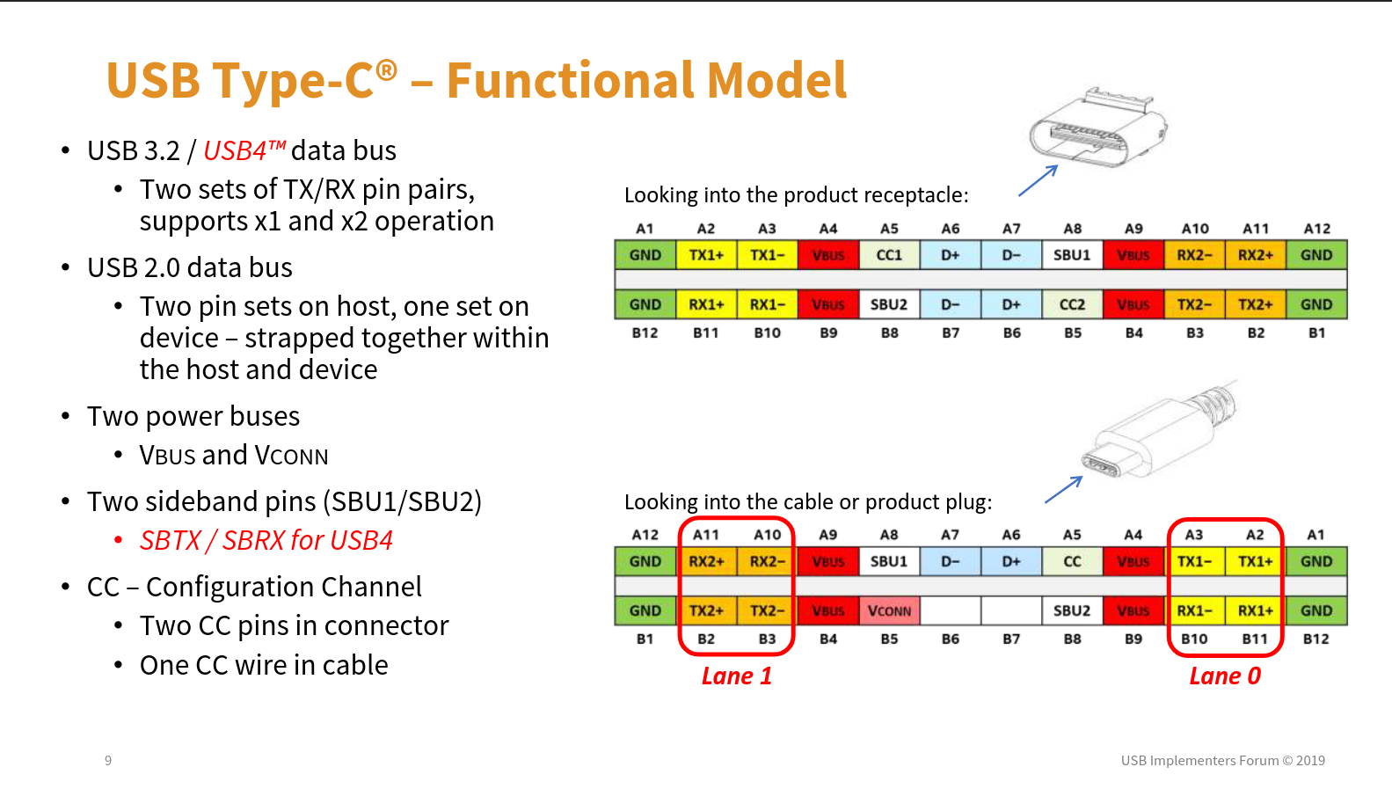
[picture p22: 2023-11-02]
Documentation/images/usbc-plug-receptacle-pins.png

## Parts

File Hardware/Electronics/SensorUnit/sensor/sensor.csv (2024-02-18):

Item | Qty | Reference(s) | Value | LibPart | Footprint | Datasheet | DNP | MANUFACTURER | STANDARD
1 | 2 | C1, C2 | 0.1uF | Device:C_Small | Capacitor_SMD:C_0603_1608Metric | ~
2 | 1 | C3 | 2.2nF | Device:C_Small | Capacitor_SMD:C_0603_1608Metric | ~
3 | 1 | C4 | 10nF | Device:C_Small | Capacitor_SMD:C_0603_1608Metric | ~
4 | 1 | D1 | Blue | Device:LED_Small | LED_SMD:LED_0603_1608Metric | ~
6 | 1 | J1 | SM04B-SRSS-TB(LF)(SN) | SM04B-SRSS-TB_LF__SN_:SM04B-SRSS-TB(LF)(SN) | Connector_JST:JST_SH_SM04B-SRSS-TB_1x04-1MP_P1.00mm_Horizontal |  |  | JST | Manufacturer recommendations
7 | 1 | R1 | 2k | Device:R_Small | Resistor_SMD:R_0603_1608Metric | ~
8 | 2 | R2, R3 | 4k7 | Device:R_Small | Resistor_SMD:R_0603_1608Metric_Pad0.98x0.95mm_HandSolder | ~
9 | 1 | U1 | MPU-6050 | sensor-rescue:MPU-6050-Sensor_Motion | Sensor_Motion:InvenSense_QFN-24_4x4mm_P0.5mm | https://store.invensense.com/datasheets/invensense/MPU-6050_DataSheet_V3%204.pdf

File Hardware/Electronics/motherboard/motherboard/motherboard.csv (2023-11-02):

Source: | /home/e/Documents/Projects/DataGlove/Electronics/motherboard/motherboard/motherboard.kicad_sch
Date: | Wed 26 Apr 2023 11:55:46 AM CEST
Tool: | Eeschema 6.0.10-2.fc37
Generator: | /usr/share/kicad/plugins/bom_csv_grouped_by_value.py
Component Count: | 57
Individual Components:
Item | Qty | Reference(s) | Value | LibPart | Footprint | Datasheet | Datasheet_1 | Description | Footprint_1 | Height | MANUFACTURER | MAXIMUM_PACKAGE_HEIGHT | Manufacturer_Name | Manufacturer_Part_Number | PARTREV | Reference_1 | STANDARD | Value_1
 |  | 111 | TF-01A | TF-01A:TF-01A | lib_fp:TF01A |  | https://datasheet.lcsc.com/szlcsc/1903221101_Korean-Hroparts-Elec-TF-01A_C91145.pdf |  | TF01A | 1.85 |  |  | Korean Hroparts Elec | TF-01A |  | J |  | TF-01A
 |  | C1 | 0.1uF | Device:C_Small | Capacitor_SMD:C_0603_1608Metric | ~
 |  | C2 | 0.1uF | Device:C_Small | Capacitor_SMD:C_0603_1608Metric | ~
 |  | C3 | 1uF | Device:C_Small | Capacitor_SMD:C_0603_1608Metric | ~
 |  | C4 | 1uF | Device:C_Small | Capacitor_SMD:C_0603_1608Metric | ~
 |  | C5 | 0.1uF | Device:C_Small | Capacitor_SMD:C_0603_1608Metric | ~
 |  | C7 | 22uF | Device:C_Small | Capacitor_SMD:C_0603_1608Metric | ~
 |  | C8 | 0.1uF | Device:C_Small | Capacitor_SMD:C_0603_1608Metric | ~
 |  | C9 | 10uF | Device:C_Small | Capacitor_SMD:C_0603_1608Metric | ~
 |  | C10 | 0.1uF | Device:C_Small | Capacitor_SMD:C_0603_1608Metric | ~
 |  | C11 | 0.1uF | Device:C_Small | Capacitor_SMD:C_0603_1608Metric | ~
 |  | C12 | 10nF | Device:C_Small | Capacitor_SMD:C_0603_1608Metric | ~
 |  | C13 | 0.1uF | Device:C_Small | Capacitor_SMD:C_0603_1608Metric | ~
 |  | C14 | 2.2nF | Device:C_Small | Capacitor_SMD:C_0603_1608Metric | ~
 |  | D1 | mbr120 | Device:D_Schottky | Diode_SMD:D_SOD-123F | ~
 |  | D2 | blue | Device:LED_Small | LED_SMD:LED_0603_1608Metric | ~
 |  | D3 | green | Device:LED_Small | LED_SMD:LED_0603_1608Metric | ~
 |  | J1 | USB_C_Receptacle | Connector:USB_C_Receptacle | lib_fp:TYPE-C-31-M-14 | https://www.usb.org/sites/default/files/documents/usb_type-c.zip
 |  | J3 | 1 | SM04B-SRSS-TB_LF__SN_:SM04B-SRSS-TB(LF)(SN) | lib_fp:JST_SM04B-SRSS-TB(LF)(SN) |  |  |  |  |  | JST |  |  |  |  |  | Manufacturer recommendations
 |  | J4 | 2 | SM04B-SRSS-TB_LF__SN_:SM04B-SRSS-TB(LF)(SN) | lib_fp:JST_SM04B-SRSS-TB(LF)(SN) |  |  |  |  |  | JST |  |  |  |  |  | Manufacturer recommendations
 |  | J5 | 3 | SM04B-SRSS-TB_LF__SN_:SM04B-SRSS-TB(LF)(SN) | lib_fp:JST_SM04B-SRSS-TB(LF)(SN) |  |  |  |  |  | JST |  |  |  |  |  | Manufacturer recommendations
 |  | J6 | 4 | SM04B-SRSS-TB_LF__SN_:SM04B-SRSS-TB(LF)(SN) | lib_fp:JST_SM04B-SRSS-TB(LF)(SN) |  |  |  |  |  | JST |  |  |  |  |  | Manufacturer recommendations
 |  | J7 | 5 | SM04B-SRSS-TB_LF__SN_:SM04B-SRSS-TB(LF)(SN) | lib_fp:JST_SM04B-SRSS-TB(LF)(SN) |  |  |  |  |  | JST |  |  |  |  |  | Manufacturer recommendations
 |  | J8 | Conn_01x02_Female | Connector:Conn_01x02_Female | lib_fp:HX25003-2AWB | ~
 |  | Q1 | HXY3401AI | Transistor_FET:AO3401A | Package_TO_SOT_SMD:SOT-23 | http://www.aosmd.com/pdfs/datasheet/AO3401A.pdf
 |  | Q2 | MMBT3904 | Transistor_BJT:MMBT3904 | Package_TO_SOT_SMD:SOT-23 | https://www.onsemi.com/pub/Collateral/2N3903-D.PDF
 |  | Q3 | MMBT3904 | Transistor_BJT:MMBT3904 | Package_TO_SOT_SMD:SOT-23 | https://www.onsemi.com/pub/Collateral/2N3903-D.PDF
 |  | R1 | 10k | Device:R_Small | Resistor_SMD:R_0603_1608Metric | ~
 |  | R2 | 100k | Device:R_Small | Resistor_SMD:R_0603_1608Metric | ~
 |  | R3 | 10k | Device:R_Small | Resistor_SMD:R_0603_1608Metric | ~
 |  | R4 | 10k | Device:R_Small | Resistor_SMD:R_0603_1608Metric | ~
 |  | R5 | 10k | Device:R_Small | Resistor_SMD:R_0603_1608Metric | ~
 |  | R6 | 5k | Device:R_Small | Resistor_SMD:R_0603_1608Metric | ~
 |  | R7 | 7k | Device:R_Small | Resistor_SMD:R_0603_1608Metric | ~
 |  | R8 | 100k | Device:R_Small | Resistor_SMD:R_0603_1608Metric | ~
 |  | R9 | 100k | Device:R_Small | Resistor_SMD:R_0603_1608Metric | ~
 |  | R10 | 5k | Device:R_Small | Resistor_SMD:R_0603_1608Metric | ~
 |  | R11 | 3.7k | Device:R_Small | Resistor_SMD:R_0603_1608Metric | ~
 |  | R12 | 3.7k | Device:R_Small | Resistor_SMD:R_0603_1608Metric | ~
 |  | R13 | 4k7 | Device:R_Small | Resistor_SMD:R_0603_1608Metric | ~
 |  | R14 | 4k7 | Device:R_Small | Resistor_SMD:R_0603_1608Metric | ~
 |  | S1 | TS2306A-240GF-MSM-9_C388290 | TS2306A-240GF-MSM-9_C388290:TS2306A-240GF-MSM-9_C388290 | lib_fp:TS2306A240GFMSM9_C388290 | https://datasheet.lcsc.com/szlcsc/1904241742_SHOU-HAN-TS2306A-240gf-MSM-9_C388290.pdf |  | Tactile Switches SPST 3.00mm x 2.00mm 0.60mm 10mA @ 5VDC SMD RoHS |  | 1 |  |  | Shou Han | TS2306A-240GF-MSM-9_C388290
 |  | TP1 | 3V3 | Connector:TestPoint | TestPoint:TestPoint_Pad_D2.0mm | ~
 |  | TP2 | IO25 | Connector:TestPoint | TestPoint:TestPoint_Pad_D2.0mm | ~
 |  | TP3 | IO26 | Connector:TestPoint | TestPoint:TestPoint_Pad_D2.0mm | ~
 |  | TP4 | IO27 | Connector:TestPoint | TestPoint:TestPoint_Pad_D2.0mm | ~
 |  | TP5 | IO32 | Connector:TestPoint | TestPoint:TestPoint_Pad_D2.0mm | ~
 |  | TP6 | GND | Connector:TestPoint | TestPoint:TestPoint_Pad_D2.0mm | ~
 |  | TP7 | TX | Connector:TestPoint | TestPoint:TestPoint_Pad_D2.0mm | ~
 |  | TP8 | RX | Connector:TestPoint | TestPoint:TestPoint_Pad_D2.0mm | ~
 |  | TP9 | DTR | Connector:TestPoint | TestPoint:TestPoint_Pad_D2.0mm | ~
 |  | TP10 | RTS | Connector:TestPoint | TestPoint:TestPoint_Pad_D2.0mm | ~
 |  | U1 | ESP32-WROOM-32E_(16MB) | ESP32-WROOM-32E__16MB_:ESP32-WROOM-32E_(16MB) | lib_fp:XCVR_ESP32-WROOM-32E_(16MB) |  |  |  |  |  | Espressif Systems | 3.25mm |  |  | 1.4 |  | Manufacturer Recommendations
 |  | U2 | AP2112K-3.3 | Regulator_Linear:AP2112K-3.3 | Package_TO_SOT_SMD:SOT-23-5 | https://www.diodes.com/assets/Datasheets/AP2112.pdf
 |  | U3 | CH340C | CH340C:CH340C | lib_fp:SOIC127P600X180-16N |  |  |  |  |  | WCH | 1.8 mm |  |  | 2G |  | IPC 7351B
 |  | U4 | TCA9548APWR | Interface_Expansion:TCA9548APWR | Package_SO:TSSOP-24_4.4x7.8mm_P0.65mm | http://www.ti.com/lit/ds/symlink/tca9548a.pdf
 |  | U5 | MPU-6050 | sensor-rescue:MPU-6050-Sensor_Motion | Sensor_Motion:InvenSense_QFN-24_4x4mm_P0.5mm | https://store.invensense.com/datasheets/invensense/MPU-6050_DataSheet_V3%204.pdf
Collated Components:
Item | Qty | Reference(s) | Value | LibPart | Footprint | Datasheet | Datasheet_1 | Description | Footprint_1 | Height | MANUFACTURER | MAXIMUM_PACKAGE_HEIGHT | Manufacturer_Name | Manufacturer_Part_Number | PARTREV | Reference_1 | STANDARD | Value_1
1 | 1 | 111 | TF-01A | TF-01A:TF-01A | lib_fp:TF01A |  | https://datasheet.lcsc.com/szlcsc/1903221101_Korean-Hroparts-Elec-TF-01A_C91145.pdf |  | TF01A | 1.85 |  |  | Korean Hroparts Elec | TF-01A |  | J |  | TF-01A
2 | 7 | C1, C2, C5, C8, C10, C11, C13 | 0.1uF | Device:C_Small | Capacitor_SMD:C_0603_1608Metric | ~
3 | 2 | C3, C4 | 1uF | Device:C_Small | Capacitor_SMD:C_0603_1608Metric | ~
4 | 1 | C7 | 22uF | Device:C_Small | Capacitor_SMD:C_0603_1608Metric | ~
5 | 1 | C9 | 10uF | Device:C_Small | Capacitor_SMD:C_0603_1608Metric | ~
6 | 1 | C12 | 10nF | Device:C_Small | Capacitor_SMD:C_0603_1608Metric | ~
7 | 1 | C14 | 2.2nF | Device:C_Small | Capacitor_SMD:C_0603_1608Metric | ~
8 | 1 | D1 | mbr120 | Device:D_Schottky | Diode_SMD:D_SOD-123F | ~
9 | 1 | D2 | blue | Device:LED_Small | LED_SMD:LED_0603_1608Metric | ~
10 | 1 | D3 | green | Device:LED_Small | LED_SMD:LED_0603_1608Metric | ~
11 | 1 | J1 | USB_C_Receptacle | Connector:USB_C_Receptacle | lib_fp:TYPE-C-31-M-14 | https://www.usb.org/sites/default/files/documents/usb_type-c.zip
12 | 1 | J3 | 1 | SM04B-SRSS-TB_LF__SN_:SM04B-SRSS-TB(LF)(SN) | lib_fp:JST_SM04B-SRSS-TB(LF)(SN) |  |  |  |  |  | JST |  |  |  |  |  | Manufacturer recommendations
13 | 1 | J4 | 2 | SM04B-SRSS-TB_LF__SN_:SM04B-SRSS-TB(LF)(SN) | lib_fp:JST_SM04B-SRSS-TB(LF)(SN) |  |  |  |  |  | JST |  |  |  |  |  | Manufacturer recommendations
14 | 1 | J5 | 3 | SM04B-SRSS-TB_LF__SN_:SM04B-SRSS-TB(LF)(SN) | lib_fp:JST_SM04B-SRSS-TB(LF)(SN) |  |  |  |  |  | JST |  |  |  |  |  | Manufacturer recommendations
15 | 1 | J6 | 4 | SM04B-SRSS-TB_LF__SN_:SM04B-SRSS-TB(LF)(SN) | lib_fp:JST_SM04B-SRSS-TB(LF)(SN) |  |  |  |  |  | JST |  |  |  |  |  | Manufacturer recommendations
16 | 1 | J7 | 5 | SM04B-SRSS-TB_LF__SN_:SM04B-SRSS-TB(LF)(SN) | lib_fp:JST_SM04B-SRSS-TB(LF)(SN) |  |  |  |  |  | JST |  |  |  |  |  | Manufacturer recommendations
17 | 1 | J8 | Conn_01x02_Female | Connector:Conn_01x02_Female | lib_fp:HX25003-2AWB | ~
18 | 1 | Q1 | HXY3401AI | Transistor_FET:AO3401A | Package_TO_SOT_SMD:SOT-23 | http://www.aosmd.com/pdfs/datasheet/AO3401A.pdf
19 | 2 | Q2, Q3 | MMBT3904 | Transistor_BJT:MMBT3904 | Package_TO_SOT_SMD:SOT-23 | https://www.onsemi.com/pub/Collateral/2N3903-D.PDF
20 | 4 | R1, R3, R4, R5 | 10k | Device:R_Small | Resistor_SMD:R_0603_1608Metric | ~
21 | 3 | R2, R8, R9 | 100k | Device:R_Small | Resistor_SMD:R_0603_1608Metric | ~
22 | 2 | R6, R10 | 5k | Device:R_Small | Resistor_SMD:R_0603_1608Metric | ~
23 | 1 | R7 | 7k | Device:R_Small | Resistor_SMD:R_0603_1608Metric | ~
24 | 2 | R11, R12 | 3.7k | Device:R_Small | Resistor_SMD:R_0603_1608Metric | ~
25 | 2 | R13, R14 | 4k7 | Device:R_Small | Resistor_SMD:R_0603_1608Metric | ~
26 | 1 | S1 | TS2306A-240GF-MSM-9_C388290 | TS2306A-240GF-MSM-9_C388290:TS2306A-240GF-MSM-9_C388290 | lib_fp:TS2306A240GFMSM9_C388290 | https://datasheet.lcsc.com/szlcsc/1904241742_SHOU-HAN-TS2306A-240gf-MSM-9_C388290.pdf |  | Tactile Switches SPST 3.00mm x 2.00mm 0.60mm 10mA @ 5VDC SMD RoHS |  | 1 |  |  | Shou Han | TS2306A-240GF-MSM-9_C388290
27 | 1 | TP1 | 3V3 | Connector:TestPoint | TestPoint:TestPoint_Pad_D2.0mm | ~
28 | 1 | TP2 | IO25 | Connector:TestPoint | TestPoint:TestPoint_Pad_D2.0mm | ~
29 | 1 | TP3 | IO26 | Connector:TestPoint | TestPoint:TestPoint_Pad_D2.0mm | ~
30 | 1 | TP4 | IO27 | Connector:TestPoint | TestPoint:TestPoint_Pad_D2.0mm | ~
31 | 1 | TP5 | IO32 | Connector:TestPoint | TestPoint:TestPoint_Pad_D2.0mm | ~
32 | 1 | TP6 | GND | Connector:TestPoint | TestPoint:TestPoint_Pad_D2.0mm | ~
33 | 1 | TP7 | TX | Connector:TestPoint | TestPoint:TestPoint_Pad_D2.0mm | ~
34 | 1 | TP8 | RX | Connector:TestPoint | TestPoint:TestPoint_Pad_D2.0mm | ~
35 | 1 | TP9 | DTR | Connector:TestPoint | TestPoint:TestPoint_Pad_D2.0mm | ~
36 | 1 | TP10 | RTS | Connector:TestPoint | TestPoint:TestPoint_Pad_D2.0mm | ~
37 | 1 | U1 | ESP32-WROOM-32E_(16MB) | ESP32-WROOM-32E__16MB_:ESP32-WROOM-32E_(16MB) | lib_fp:XCVR_ESP32-WROOM-32E_(16MB) |  |  |  |  |  | Espressif Systems | 3.25mm |  |  | 1.4 |  | Manufacturer Recommendations
38 | 1 | U2 | AP2112K-3.3 | Regulator_Linear:AP2112K-3.3 | Package_TO_SOT_SMD:SOT-23-5 | https://www.diodes.com/assets/Datasheets/AP2112.pdf
39 | 1 | U3 | CH340C | CH340C:CH340C | lib_fp:SOIC127P600X180-16N |  |  |  |  |  | WCH | 1.8 mm |  |  | 2G |  | IPC 7351B
40 | 1 | U4 | TCA9548APWR | Interface_Expansion:TCA9548APWR | Package_SO:TSSOP-24_4.4x7.8mm_P0.65mm | http://www.ti.com/lit/ds/symlink/tca9548a.pdf
41 | 1 | U5 | MPU-6050 | sensor-rescue:MPU-6050-Sensor_Motion | Sensor_Motion:InvenSense_QFN-24_4x4mm_P0.5mm | https://store.invensense.com/datasheets/invensense/MPU-6050_DataSheet_V3%204.pdf

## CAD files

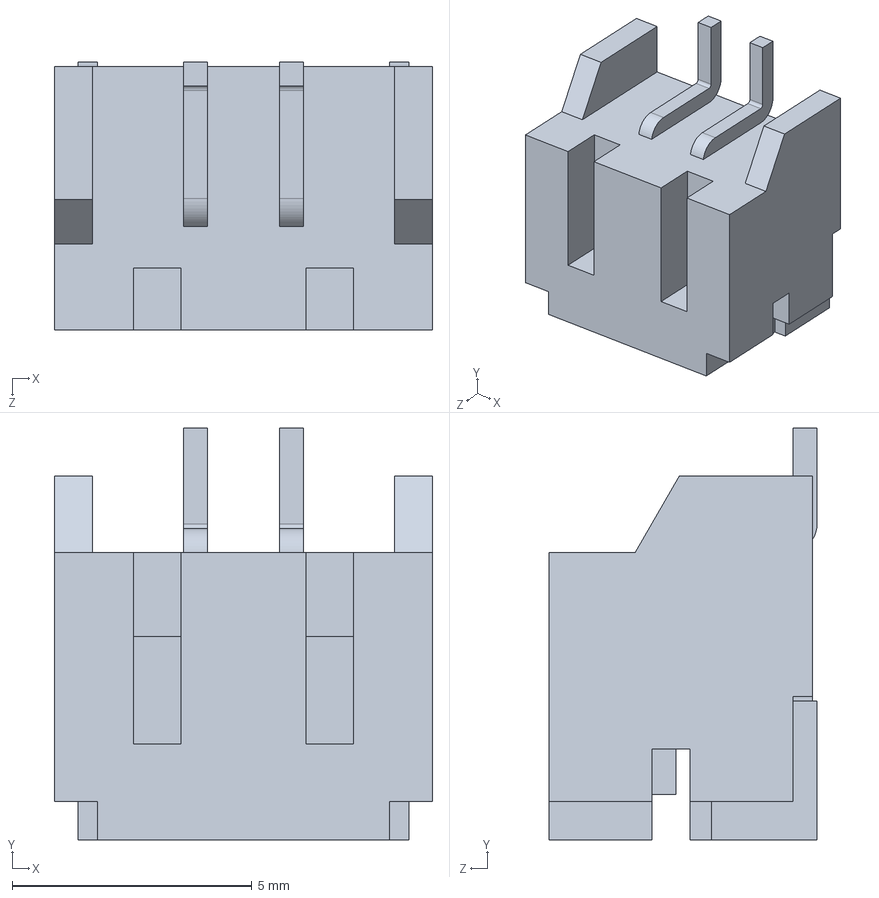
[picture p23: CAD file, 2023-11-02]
Hardware/Electronics/motherboard/motherboard/3d_models/S2B-PH-SM4-TB_LF__SN_.stp
7.90 x 8.60 x 5.60 mm

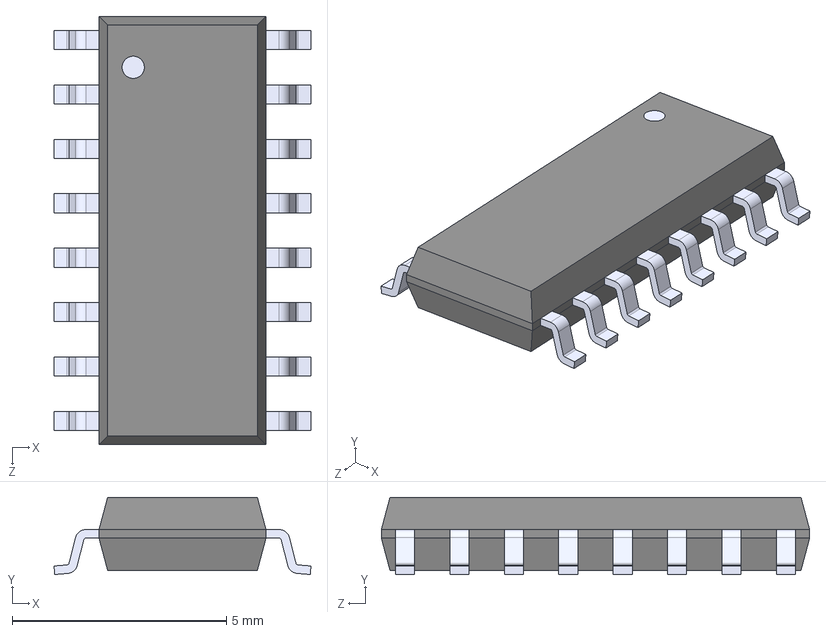
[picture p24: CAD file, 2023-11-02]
Hardware/Electronics/motherboard/motherboard/parts/CH340C/CH340C.step
6.00 x 1.80 x 10.0 mm

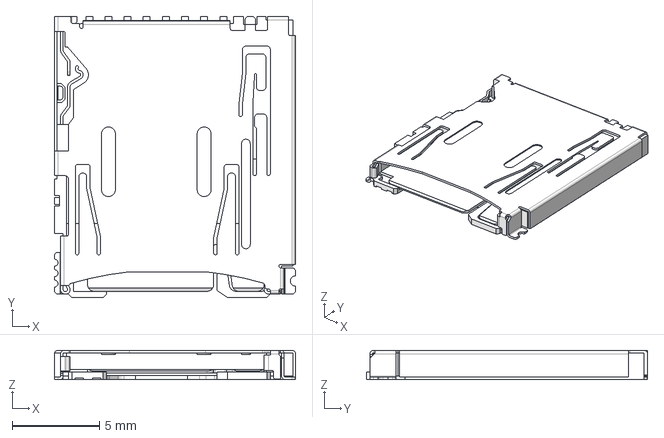
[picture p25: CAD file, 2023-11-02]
Hardware/Electronics/motherboard/motherboard/parts/DM3AT-SF-PEJM5/DM3AT-SF-PEJM5.step
13.8 x 16.2 x 1.68 mm

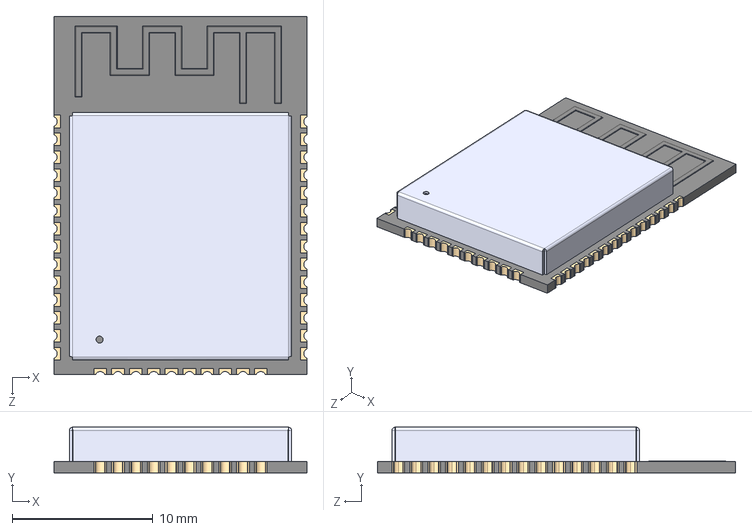
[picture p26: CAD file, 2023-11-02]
Hardware/Electronics/motherboard/motherboard/parts/ESP32-WROOM-32E__16MB/ESP32-WROOM-32E__16MB_.step
18.0 x 3.25 x 25.5 mm

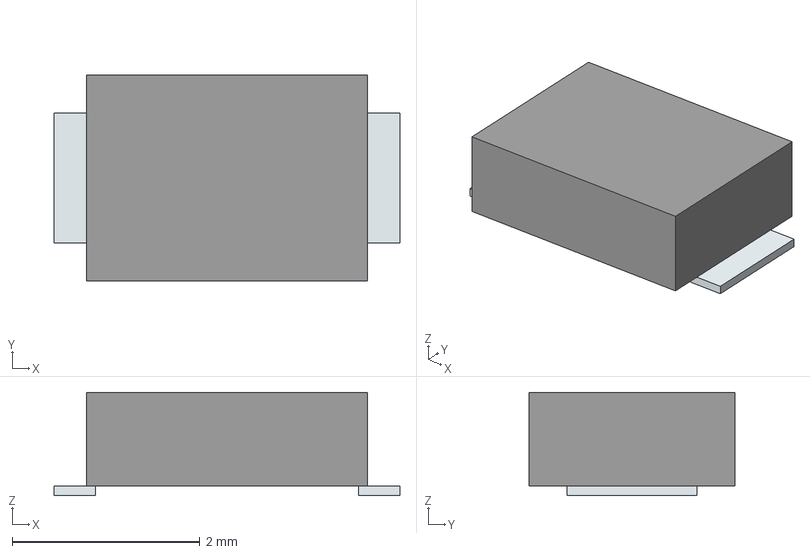
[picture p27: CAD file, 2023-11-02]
Hardware/Electronics/motherboard/motherboard/parts/LIB_TS2306A-240GF-MSM-9_C388290/TS2306A-240GF-MSM-9_C388290/3D/TS2306A-240GF-MSM-9_C388290.stp
3.69 x 2.20 x 1.10 mm
Pins

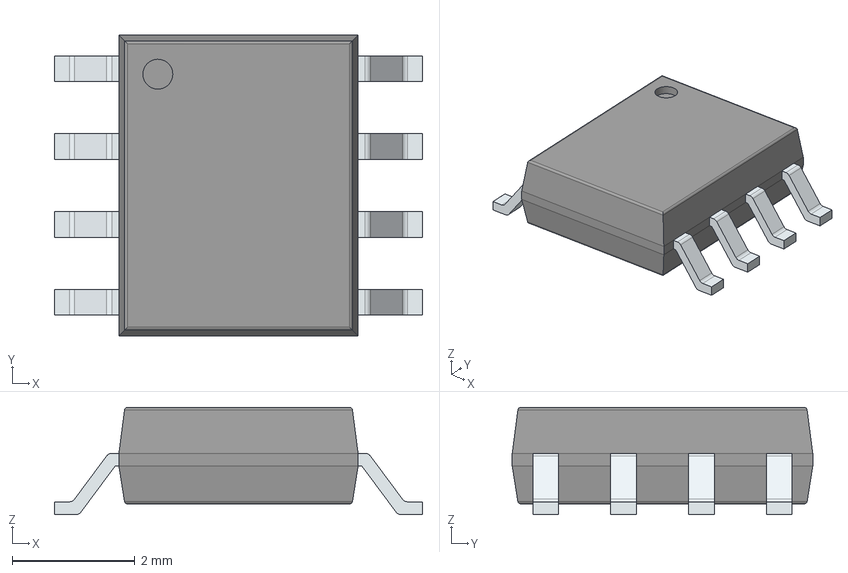
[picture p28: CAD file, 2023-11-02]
Hardware/Electronics/motherboard/motherboard/parts/MAX1627ESA+T/MAX1627ESA+T.stp
6.00 x 4.90 x 1.75 mm
PinsArrayLR

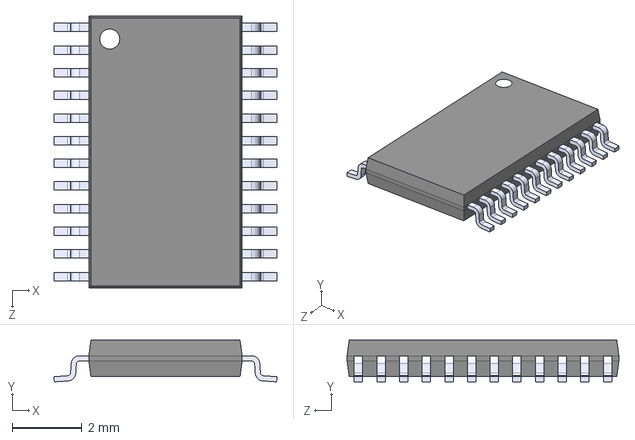
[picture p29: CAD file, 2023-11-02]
Hardware/Electronics/motherboard/motherboard/parts/TCA9548APWR/TCA9548APWR.step
6.40 x 1.20 x 7.80 mm

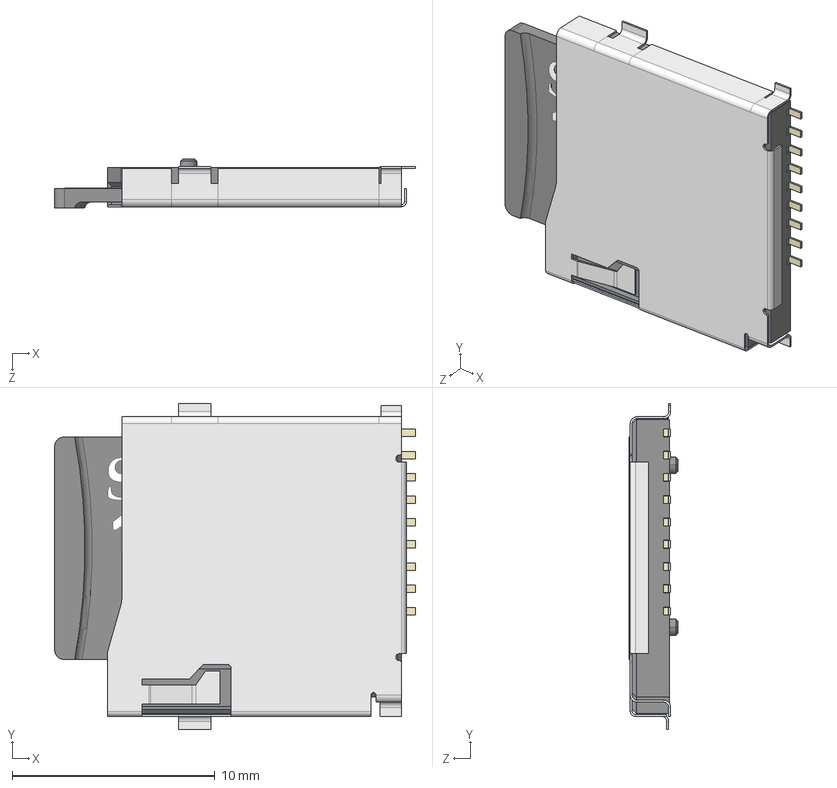
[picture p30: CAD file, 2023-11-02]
Hardware/Electronics/motherboard/motherboard/parts/TF-01A/TF-01A/3D/TF-01A.stp
17.8 x 16.1 x 2.40 mm

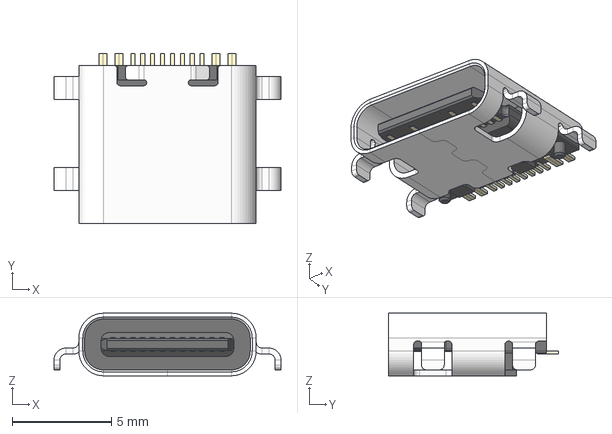
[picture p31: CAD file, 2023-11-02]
Hardware/Electronics/motherboard/motherboard/parts/TYPE-C-31-M-14_C223907/hro-usb-type-c-31-m-14-1/HRO TYPE-C-31-M-14.step
11.5 x 8.56 x 3.16 mm
Shroud
Plastic Body & Connector

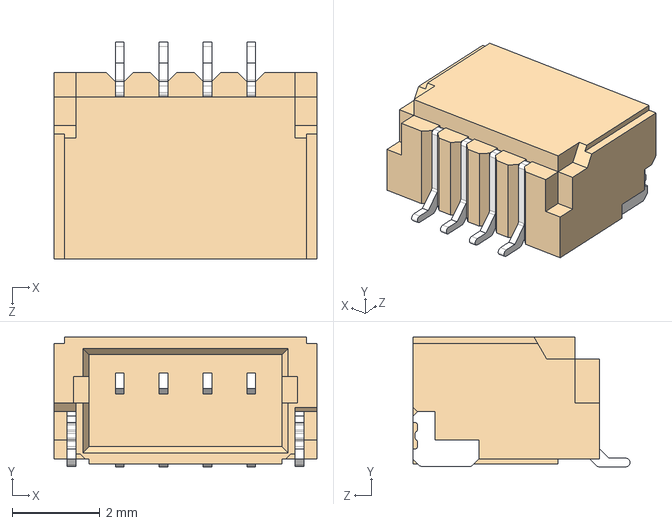
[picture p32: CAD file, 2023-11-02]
Hardware/Electronics/motherboard/motherboard/3d_models/SM04B-SRSS-TB_LF__SN_.stp
6.00 x 2.96 x 4.95 mm

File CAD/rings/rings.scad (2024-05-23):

use <Round-Anything/polyround.scad>


overlap = 0.001;
thumb_dia = 16.0;
index_dia = 14.5;
middle_dia = 15.5;
ring_dia = 14.0;
pinky_dia = 12.0;
thumb_hole_width = 75;
thumb_hole_angle = -30;


$fa = 1;
$fs = 0.4;

module ring(inner_diameter, tolerance=1.5, hole_width_angle=75, hole_angle=0){
    tol = tolerance;
    strength = 1.5;
    inner_diameter = inner_diameter + tolerance;
    outer_diameter = inner_diameter + strength*2;
    thickness = 2;
    pcb_width = 13;
    pcb_height = 1;
    catch_wall = 1.5;
    catch_width = pcb_width + 2*catch_wall;
    catch_overhang = 0.5;
    prong_height = 2;
    catch_height = pcb_height + prong_height + 0.01;
    corner_rad = 0.5;
    
    difference(){

    union(){
    cylinder(h = thickness, r=outer_diameter/2, center=true); // Outer ring

    // difference(){
        translate([0, outer_diameter/2, -thickness/2])linear_extrude(thickness){
        polygon(polyRound([
            [-catch_width/2, 0, 0],// bottom`left`
            [-outer_diameter/2, -outer_diameter/2, 0],
            [outer_diameter/2, -outer_diameter/2, 0],
            [catch_width/2, 0 , 0],// bottom right
            [catch_width/2, catch_height, corner_rad],
            [catch_width/2-catch_wall-catch_overhang, catch_height, corner_rad],
            [catch_width/2-catch_wall-catch_overhang, catch_height-prong_height, 0.5],
            [catch_width/2-catch_wall, catch_height-prong_height, 0],
            [catch_width/2-catch_wall, catch_height-prong_height-pcb_height, 0],
            [-catch_width/2+catch_wall, catch_height-prong_height-pcb_height, 0],
            [-catch_width/2+catch_wall, catch_height-prong_height, 0],
            [-catch_width/2+catch_wall+catch_overhang, catch_height-prong_height, 0.5],
            [-catch_width/2+catch_wall+catch_overhang, catch_height, corner_rad],
            [-catch_width/2, catch_height, corner_rad]
            ], 30));
        }
    }
    
    
    cylinder(h=thickness, r=inner_diameter/2, center=true); // Ring hole
    
    // hole maker

    #rotate([0,0,hole_angle])translate([0,0,-thickness/2])linear_extrude(height=thickness){
        r = outer_diameter/2;
        hole_x = tan(hole_width_angle/2)*r;
        hole_y = r;
        
        
            
        fillet_rad = strength/2;
        rf = r-fillet_rad;
        fillet_x = rf*sin(hole_width_angle/2);
        fillet_y = -rf*cos(hole_width_angle/2);
        difference(){
        polygon([[0,0],[-hole_x, -hole_y], [hole_x, -hole_y]]);
        translate([fillet_x, fillet_y, 0])circle(fillet_rad);
        translate([-fillet_x, fillet_y, 0])circle(fillet_rad);
        }
    }

    }
}

// Thumb
ring(thumb_dia, hole_width_angle=thumb_hole_width, hole_angle=thumb_hole_angle);

// Index
translate([-index_dia*1.5,0,0])
ring(index_dia);

// Middle
translate([middle_dia*1.5,0,0])
ring(middle_dia);

// Ring
translate([-middle_dia,middle_dia*1.5,0])
ring(ring_dia);

// Pinky
translate([middle_dia,middle_dia*1.5,0])
ring(pinky_dia);

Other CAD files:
Hardware/Electronics/motherboard/motherboard/parts/LIB_S2B-PH-SM4-TB_LF__SN_/S2B-PH-SM4-TB_LF__SN_/Allegro/s2bphsm4tblfsn.psm
Hardware/Electronics/motherboard/motherboard/parts/LIB_S2B-PH-SM4-TB_LF__SN_/S2B-PH-SM4-TB_LF__SN_/DEHDL/s2b_ph_sm4_tb_lf__sn_/chips/chips.prt
Hardware/Electronics/motherboard/motherboard/parts/LIB_TS2306A-240GF-MSM-9_C388290/TS2306A-240GF-MSM-9_C388290/Allegro/ts2306a240gfmsm9_c388290.psm
Hardware/Electronics/motherboard/motherboard/parts/LIB_TS2306A-240GF-MSM-9_C388290/TS2306A-240GF-MSM-9_C388290/DEHDL/ts2306a_240gf_msm_9_c388290/chips/chips.prt
Hardware/Electronics/motherboard/motherboard/parts/TF-01A/TF-01A/Allegro/tf01a.psm
Hardware/Electronics/motherboard/motherboard/parts/TF-01A/TF-01A/DEHDL/tf_01a/chips/chips.prt
Hardware/Electronics/motherboard/motherboard/parts/TYPE-C-31-M-14_C223907/hro-usb-type-c-31-m-14-1/HRO TYPE-C-31-M-14.f3d

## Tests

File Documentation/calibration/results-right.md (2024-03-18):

# Calibration values

## Pinky

### Average

```
[-367.8, -18006.0, 7812.3, 131.8, -140.8, -140.2]
{-368, -18006, 7812, 132, -141, -140}
```

**1. Run**
```
....................    XAccel                  YAccel                              ZAccel             XGyro                    YGyro                   ZGyro
 [-95,-94] --> [-14,3]  [-4913,-4911] --> [-14,3]  [2133,2135] --> [16376,16385]    [30,31] --> [0,5]  [-40,-39] --> [0,4]      [-38,-37] --> [0,4]
.................... [-95,-94] --> [-14,3]      [-4913,-4912] --> [-14,6]   [2133,2134] --> [16376,16393]       [30,31] --> [0,5]       [-40,-39] --> [-1,4][-38,-37] --> [0,4]
.................... [-95,-94] --> [-14,3]      [-4913,-4912] --> [-12,6]   [2133,2134] --> [16378,16393]       [30,31] --> [0,5]       [-40,-39] --> [-1,4][-38,-37] --> [0,4]
```

```
[-95,-94] --> [-14,3]  [-4913,-4911] --> [-14,3]  [2133,2135] --> [16376,16385]    [30,31] --> [0,5]  [-40,-39] --> [0,4]      [-38,-37] --> [0,4]
[-95,-94] --> [-14,3]      [-4913,-4912] --> [-14,6]   [2133,2134] --> [16376,16393]       [30,31] --> [0,5]       [-40,-39] --> [-1,4][-38,-37] --> [0,4]
[-95,-94] --> [-14,3]      [-4913,-4912] --> [-12,6]   [2133,2134] --> [16378,16393]       [30,31] --> [0,5]       [-40,-39] --> [-1,4][-38,-37] --> [0,4]
```

**2. run**
```
....................    XAccel                  YAccel                              ZAccel             XGyro                    YGyro                   ZGyro
 [-103,-102] --> [0,17] [-4911,-4908] --> [-3,28]  [2129,2130] --> [16373,16390]    [38,39] --> [0,3]  [-39,-38] --> [-2,1]     [-39,-38] --> [-2,1]
.................... [-103,-102] --> [-2,17]    [-4911,-4909] --> [-3,10]   [2129,2130] --> [16374,16390]       [38,39] --> [0,3]       [-39,-38] --> [-2,1][-39,-38] --> [-1,1]
.................... [-103,-102] --> [-4,17]    [-4911,-4910] --> [-3,10]   [2129,2130] --> [16375,16390]       [38,39] --> [0,3]       [-39,-38] --> [-3,1][-39,-38] --> [-2,1]
.................... [-103,-102] --> [-5,17]    [-4911,-4910] --> [-8,10]   [2129,2130] --> [16374,16390]       [38,39] --> [0,3]       [-39,-38] --> [-2,1][-39,-38] --> [-2,1]
```

```
[-103,-102] --> [0,17] [-4911,-4908] --> [-3,28]  [2129,2130] --> [16373,16390]    [38,39] --> [0,3]  [-39,-38] --> [-2,1]     [-39,-38] --> [-2,1]
[-103,-102] --> [-2,17]    [-4911,-4909] --> [-3,10]   [2129,2130] --> [16374,16390]       [38,39] --> [0,3]       [-39,-38] --> [-2,1][-39,-38] --> [-1,1]
[-103,-102] --> [-4,17]    [-4911,-4910] --> [-3,10]   [2129,2130] --> [16375,16390]       [38,39] --> [0,3]       [-39,-38] --> [-3,1][-39,-38] --> [-2,1]
[-103,-102] --> [-5,17]    [-4911,-4910] --> [-8,10]   [2129,2130] --> [16374,16390]       [38,39] --> [0,3]       [-39,-38] --> [-2,1][-39,-38] --> [-2,1]
```

**3. run**
```
[-103,-102] --> [-9,10]        [-4911,-4908] --> [-6,31]   [2129,2130] --> [16382,16394]   [37,38] --> [-3,1]  [-38,-37] --> [-1,2]    [-39,-38] --> [-1,1]
[-103,-102] --> [-11,10]   [-4911,-4909] --> [-6,17]   [2129,2130] --> [16379,16394]       [37,38] --> [-2,1]      [-38,-37] --> [-1,2][-39,-38] --> [-2,1]
[-103,-102] --> [-8,10]    [-4911,-4910] --> [-6,12]   [2129,2130] --> [16378,16394]       [37,38] --> [-2,1]      [-38,-37] --> [-1,2][-39,-38] --> [-1,1]
[-103,-102] --> [-10,10]   [-4911,-4910] --> [-2,12]   [2129,2130] --> [16380,16394]       [37,38] --> [-3,1]      [-38,-37] --> [-2,2][-39,-38] --> [-2,1]
```

## Ring

### Average
```
[-15597.5, -3881.7, 5878.3, -54.7, -292.3, 297.3]
{-15598, -3882, 5878, -55, -292, 297}
```

**1. Run**
```
[-4679,-4677] --> [-1,21]      [-1165,-1164] --> [-4,7]    [1763,1764] --> [16371,16396]   [-19,-18] --> [-2,3]        [-90,-89] --> [-3,2]    [88,89] --> [-2,1]
[-4679,-4678] --> [-1,16]  [-1165,-1164] --> [-9,7]    [1763,1764] --> [16378,16396]       [-19,-18] --> [-9,3]    [-90,-89] --> [-4,2][88,89] --> [-2,1]
[-4679,-4678] --> [-3,16]  [-1165,-1164] --> [-8,7]    [1763,1764] --> [16381,16396]       [-19,-18] --> [-10,3]   [-90,-89] --> [-4,2][88,89] --> [-3,1]
```

**2. Run**
```
[-4679,-4677] --> [0,17]       [-1165,-1164] --> [0,14]        [1763,1764] --> [16374,16396]   [-16,-15] --> [-2,3]      [-88,-87] --> [-1,3]    [89,90] --> [-1,3]
[-4679,-4678] --> [0,16]   [-1165,-1164] --> [0,14]        [1763,1764] --> [16375,16396]     [-16,-15] --> [-2,3]    [-88,-87] --> [-1,3]    [89,90] --> [-1,3]
[-4679,-4678] --> [-1,16]  [-1165,-1164] --> [-1,14]       [1763,1764] --> [16376,16396]     [-16,-15] --> [-2,3]    [-88,-87] --> [-2,3]    [89,90] --> [-1,3]
```

**3. Run**
```
[-4682,-4679] --> [-4,11]      [-1165,-1164] --> [-6,17]       [1763,1764] --> [16378,16396]   [-16,-15] --> [-2,1]      [-87,-86] --> [0,3]     [89,90] --> [-3,1]
[-4682,-4680] --> [-4,16]  [-1165,-1164] --> [-1,17]       [1763,1764] --> [16379,16396]     [-16,-15] --> [-3,1]    [-87,-86] --> [-1,3]    [89,90] --> [-3,1]
[-4681,-4680] --> [-3,16]  [-1165,-1164] --> [0,17]        [1763,1764] --> [16377,16396]     [-16,-15] --> [-3,1]    [-87,-86] --> [-1,3]    [89,90] --> [-3,1]
[-4681,-4680] --> [-4,16]  [-1165,-1164] --> [-1,17]       [1763,1764] --> [16379,16396]     [-16,-15] --> [-3,1]    [-87,-86] --> [-1,3]    [89,90] --> [-3,1]
```

## Middle

### Average
```
[-1959.7, -510.5, 2775.3, 53.5, -183.2, 14.8]
{-1960, -510, 2775, 54, -183, 15}
```

**1. Run**
```
[-839,-839] --> [0,1]  [-219,-218] --> [-8,9]  [1189,1190] --> [16375,16390]   [21,22] --> [-1,1]      [-79,-78] --> [-2,1]      [7,8] --> [-2,2]
[-839,-839] --> [0,1]      [-219,-218] --> [-10,9] [1189,1190] --> [16376,16390]   [21,22] --> [0,1] [-79,-78] --> [-2,1]    [7,8] --> [-2,2]
```

**2. Run**
```
[-834,-833] --> [0,2]  [-223,-222] --> [-14,1] [1189,1190] --> [16374,16389]   [20,21] --> [-7,2]      [-79,-78] --> [-2,1]      [6,7] --> [0,1]
[-834,-834] --> [0,1]      [-223,-222] --> [-12,1] [1189,1190] --> [16375,16389]   [20,21] --> [-10,2]       [-79,-78] --> [-1,1]    [6,7] --> [0,1]
```

**3. Run**
```
[-845,-844] --> [-12,4]    [-217,-216] --> [-16,1] [1188,1190] --> [16373,16393]   [25,26] --> [-1,2]        [-79,-78] --> [0,3]     [5,6] --> [0,3]
[-845,-844] --> [-12,4]        [-217,-216] --> [-13,1] [1189,1190] --> [16371,16393]   [25,26] --> [-2,2][-79,-78] --> [0,3]     [5,6] --> [0,3]
[-845,-844] --> [-12,4]    [-217,-216] --> [-17,1] [1189,1190] --> [16372,16393]   [25,26] --> [-2,2]        [-79,-78] --> [0,3]     [5,6] --> [0,3]
```

## Index

### Average
```
[-1260.2, 3655.7, 6252.5, -3359.5, -492.7, 30.7]
{-1260, 3656, 6252, -3360, -493, 31}
```

**1. Run**
```
[-467,-466] --> [0,17] [1346,1347] --> [-1,1]  [2360,2361] --> [16366,16390]   [-1267,-1266] --> [-1,3] [-180,-179] --> [-2,4]   [11,12] --> [-1,2]
[-467,-467] --> [0,2]      [1346,1347] --> [-3,1]  [2360,2360] --> [16366,16410]   [-1267,-1267] --> [-1,1]  [-180,-179] --> [-5,4]  [11,12] --> [-1,2]
```

**2. Run**
```
[-473,-472] --> [-14,2]        [1351,1352] --> [0,14]  [2346,2348] --> [16380,16396]   [-1270,-1269] --> [-4,1]  [-177,-176] --> [-3,1]  [11,12] --> [0,4]
[-473,-472] --> [-12,2]    [1351,1352] --> [-4,14] [2346,2347] --> [16380,16393]   [-1270,-1269] --> [-2,1]  [-177,-176] --> [-3,1]  [11,12] --> [0,4]
[-473,-472] --> [-11,2]    [1351,1352] --> [-13,14]        [2346,2346] --> [16380,16406]     [-1270,-1269] --> [-2,1]        [-177,-176] --> [-4,1]  [11,12] --> [0,4]
```

**3. Run**
```
[-477,-476] --> [0,15] [1406,1407] --> [-3,1]  [2332,2334] --> [16376,16387]   [-1246,-1245] --> [0,2] [-197,-196] --> [0,3]     [11,12] --> [-3,1]
[-477,-476] --> [0,15]     [1406,1407] --> [-7,1]  [2332,2333] --> [16376,16388]   [-1246,-1245] --> [0,2]   [-197,-196] --> [0,3]   [11,12] --> [-3,1]
[-477,-476] --> [0,15]     [1406,1407] --> [-10,1] [2332,2332] --> [16376,16397]   [-1246,-1245] --> [0,2]   [-197,-196] --> [-1,3]  [11,12] --> [-3,1]
```

## Thumb

## Average
```
[-3570.8, -2402.8, 3423.2, 208.5, -89.8, -214.2]
{-3571, -2403, 3423, 208, -90, -214}
```

**1. Run**
```
[-1190,-1188] --> [-6,17]  [-803,-802] --> [-1,16] [1138,1140] --> [16351,16399]   [67,68] --> [-3,2]        [-30,-29] --> [0,3]     [-70,-69] --> [0,1]
[-1190,-1189] --> [-6,5]       [-803,-802] --> [0,16]  [1139,1140] --> [16316,16399]   [67,68] --> [-1,2][-30,-29] --> [0,3]     [-70,-70] --> [0,1]
[-1190,-1190] --> [-6,9]   [-803,-802] --> [-1,16] [1139,1140] --> [16288,16399]   [67,68] --> [-1,2]        [-30,-29] --> [0,3]     [-70,-70] --> [0,3]
```

**2. Run**
```
[-1190,-1188] --> [-6,7]   [-800,-799] --> [-1,1]  [1140,1142] --> [16341,16386]   [70,71] --> [0,5] [-30,-29] --> [0,3]     [-74,-73] --> [0,5]
[-1189,-1188] --> [-17,7]      [-800,-800] --> [-1,5]  [1140,1141] --> [16341,16403]   [70,71] --> [0,5][-30,-30] --> [0,1]      [-74,-73] --> [-1,5]
[-1189,-1188] --> [-24,7]  [-800,-800] --> [-1,14] [1140,1140] --> [16341,16434]   [70,71] --> [0,5] [-30,-30] --> [0,2]     [-74,-73] --> [-2,5]
```

**3. Run**
```
[-1194,-1192] --> [-18,5]  [-801,-800] --> [0,19]  [1142,1144] --> [16363,16397]   [70,71] --> [0,4] [-31,-30] --> [-1,1]    [-71,-70] --> [0,5]
[-1193,-1192] --> [-8,5]       [-801,-800] --> [-1,19] [1143,1144] --> [16337,16397]   [70,71] --> [0,4][-31,-30] --> [-3,1]     [-71,-71] --> [0,3]
[-1193,-1192] --> [-5,5]   [-801,-800] --> [-3,19] [1143,1144] --> [16316,16397]   [70,71] --> [0,4] [-31,-30] --> [-3,1]    [-71,-71] --> [0,4]
```

## Onboard

### Average
```
[-1074.5, 2309.3, 1021.5, 115.5, -25.5, 26.3]
{-1074, 2309, 1022, 116, -26, 26}
```

**Single run**
```
[-1075,-1074] --> [-6,11]      [2308,2310] --> [-12,3] [1021,1022] --> [16373,16393]   [115,116] --> [0,4]       [-26,-25] --> [-2,1]    [26,27] --> [0,5]
[-1075,-1074] --> [-6,11]  [2309,2310] --> [-12,3] [1021,1022] --> [16376,16393]   [115,116] --> [0,4]       [-26,-25] --> [-2,1]    [26,27] --> [0,5]
[-1075,-1074] --> [-7,11]  [2309,2310] --> [-13,3] [1021,1022] --> [16376,16393]   [115,116] --> [0,4]       [-26,-25] --> [-2,1]    [26,26] --> [0,1]
```

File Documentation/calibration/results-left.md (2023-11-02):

# Calibration values

## Thumb

### Average
```
[-265,-264] --> [-7,13]    [-2993,-2992] --> [-9,8]        [1709,1710] --> [16368,16390]   [-174,-173] --> [-1,2]  [214,215] --> [0,1]     [45,46] --> [0,3]
[-259,-258] --> [-1,18]    [-2995,-2994] --> [-3,13]       [1711,1712] --> [16379,16395]   [-174,-173] --> [-1,2]  [214,214] --> [0,1]     [45,46] --> [-1,2]
[-262,-262] --> [0,1]      [-2994,-2994] --> [0,2] [1711,1712] --> [16382,16403]   [-174,-173] --> [-2,1]  [212,213] --> [0,3]     [45,46] --> [-3,1]
---
[-261.7, -2993.7, 1710.8, -173.5, 213.7, 45.5]
{-262, -2994, 1711, -174, 214, 46}
```

**1. Run**
```
at 600 Readings
-266.00000,     -2993.00000,    1710.00000,     -173.00000,     214.00000,      45.00000

>.>.700 Total Readings
-266.00000,     -2993.00000,    1710.00000,     -174.00000,     215.00000,      45.00000

>.>.800 Total Readings
-266.00000,     -2993.00000,    1710.00000,     -174.00000,     214.00000,      44.00000

>.>.900 Total Readings
-266.00000,     -2993.00000,    1710.00000,     -173.00000,     214.00000,      45.00000

>.>.1000 Total Readings
-266.00000,     -2993.00000,    1708.00000,     -173.00000,     214.00000,      45.00000

 Any of the above offsets will work nice

 Lets proof the PID tuning using another method:
averaging 1000 readings each time
expanding:
....    XAccel                  YAccel                          ZAccel                  XGyro                   YGyro                   ZGyro
 [0,0] --> [2421,2426]  [0,0] --> [28803,28803] [0,0] --> [1853,1855]   [0,0] --> [692,692]     [0,0] --> [-854,-855]   [0,0] --> [-179,-179]
.... [-1000,0] --> [-6702,2419] [-1000,0] --> [19177,28810]     [0,1000] --> [1853,10355]       [-1000,0] --> [-3305,691]       [0,1000] --> [-854,3141]        [0,1000] --> [-179,3815]
.... [-1000,0] --> [-6702,2422] [-2000,0] --> [9552,28805]      [0,2000] --> [1857,18855]       [-1000,0] --> [-3305,690]       [0,1000] --> [-853,3140]        [0,1000] --> [-175,3816]
.... [-1000,0] --> [-6704,2422] [-3000,0] --> [-69,28809]       [0,2000] --> [1858,18855]       [-1000,0] --> [-3305,691]       [0,1000] --> [-853,3140]        [0,1000] --> [-176,3815]

closing in:
..      XAccel                  YAccel                          ZAccel                  XGyro                   YGyro                   ZGyro
 [-500,0] --> [-2139,2422]      [-3000,-1500] --> [-69,14371]   [1000,2000] --> [10358,18855]   [-500,0] --> [-1305,691]        [0,500] --> [-853,1145] [0,500] --> [-176,1821]
.. [-500,-250] --> [-2139,139]  [-3000,-2250] --> [-69,7148]    [1500,2000] --> [14602,18855]   [-250,0] --> [-305,691] [0,250] --> [-853,143]  [0,250] --> [-176,820]
.. [-375,-250] --> [-1008,139]  [-3000,-2625] --> [-69,3533]    [1500,1750] --> [14602,16729]   [-250,-125] --> [-305,193]      [125,250] --> [-358,143]        [0,125] --> [-176,319]
.. [-312,-250] --> [-425,139]   [-3000,-2812] --> [-69,1741]    [1625,1750] --> [15654,16729]   [-187,-125] --> [-53,193]       [187,250] --> [-110,143]        [0,62] --> [-176,68]
.. [-281,-250] --> [-151,139]   [-3000,-2906] --> [-69,836]     [1687,1750] --> [16183,16729]   [-187,-156] --> [-53,70]        [187,218] --> [-110,13] [31,62] --> [-56,68]
..      XAccel                  YAccel                          ZAccel                  XGyro                   YGyro                   ZGyro
 [-265,-250] --> [-5,139]       [-3000,-2953] --> [-69,375]     [1687,1718] --> [16183,16455]   [-187,-171] --> [-53,10]        [202,218] --> [-50,13]  [31,46] --> [-56,3]
.. [-265,-257] --> [-5,67]      [-3000,-2976] --> [-69,164]     [1702,1718] --> [16317,16455]   [-179,-171] --> [-20,10]        [210,218] --> [-18,13]  [38,46] --> [-27,3]
.. [-265,-261] --> [-5,33]      [-3000,-2988] --> [-69,44]      [1702,1710] --> [16317,16390]   [-175,-171] --> [-5,10] [214,218] --> [-1,13]   [42,46] --> [-12,3]
.. [-265,-263] --> [-5,11]      [-2994,-2988] --> [-7,44]       [1706,1710] --> [16353,16390]   [-175,-173] --> [-5,2]  [214,216] --> [-1,5]    [44,46] --> [-4,3]
.. [-265,-264] --> [-5,13]      [-2994,-2991] --> [-7,12]       [1708,1710] --> [16368,16390]   [-174,-173] --> [-2,2]  [214,215] --> [-1,1]    [45,46] --> [0,3]
averaging 10000 readings each time
....................    XAccel                  YAccel                          ZAccel                  XGyro                   YGyro                   ZGyro
 [-265,-264] --> [-5,13]        [-2994,-2992] --> [-7,8]        [1709,1710] --> [16369,16390]   [-174,-173] --> [-2,2]  [214,215] --> [-2,1]    [45,46] --> [0,3]
.................... [-265,-264] --> [-5,13]    [-2993,-2992] --> [-9,8]        [1709,1710] --> [16368,16390]   [-174,-173] --> [-1,2]  [214,215] --> [-1,1]    [45,46] --> [0,3]
.................... [-265,-264] --> [-7,13]    [-2993,-2992] --> [-9,8]        [1709,1710] --> [16368,16390]   [-174,-173] --> [-1,2]  [214,215] --> [0,1]     [45,46] --> [0,3]
-------------- done --------------
```

**2. Run**
```
at 600 Readings
-260.00000,     -2997.00000,    1712.00000,     -174.00000,     214.00000,      46.00000

>.>.700 Total Readings
-260.00000,     -2995.00000,    1710.00000,     -174.00000,     213.00000,      46.00000

>.>.800 Total Readings
-260.00000,     -2995.00000,    1710.00000,     -174.00000,     213.00000,      46.00000

>.>.900 Total Readings
-260.00000,     -2993.00000,    1710.00000,     -175.00000,     214.00000,      46.00000

>.>.1000 Total Readings
-260.00000,     -2993.00000,    1710.00000,     -174.00000,     214.00000,      45.00000

 Any of the above offsets will work nice

 Lets proof the PID tuning using another method:
averaging 1000 readings each time
expanding:
....    XAccel                  YAccel                          ZAccel                  XGyro                   YGyro                   ZGyro
 [0,0] --> [2373,2375]  [0,0] --> [28829,28829] [0,0] --> [1836,1843]   [0,0] --> [695,693]     [0,0] --> [-853,-852]   [0,0] --> [-183,-183]
.... [-1000,0] --> [-6747,2377] [-1000,0] --> [19209,28830]     [0,1000] --> [1839,10340]       [-1000,0] --> [-3304,692]       [0,1000] --> [-852,3143]        [0,1000] --> [-182,3813]
.... [-1000,0] --> [-6746,2375] [-2000,0] --> [9584,28834]      [0,2000] --> [1849,18841]       [-1000,0] --> [-3304,692]       [0,1000] --> [-850,3142]        [0,1000] --> [-178,3813]
.... [-1000,0] --> [-6751,2370] [-3000,0] --> [-41,28831]       [0,2000] --> [1839,18842]       [-1000,0] --> [-3302,693]       [0,1000] --> [-851,3142]        [0,1000] --> [-177,3814]

closing in:
..      XAccel                  YAccel                          ZAccel                  XGyro                   YGyro                   ZGyro
 [-500,0] --> [-2187,2370]      [-3000,-1500] --> [-41,14392]   [1000,2000] --> [10342,18842]   [-500,0] --> [-1304,693]        [0,500] --> [-851,1146] [0,500] --> [-177,1820]
.. [-500,-250] --> [-2187,88]   [-3000,-2250] --> [-41,7178]    [1500,2000] --> [14591,18842]   [-250,0] --> [-306,693] [0,250] --> [-851,144]  [0,250] --> [-177,819]
.. [-375,-250] --> [-1060,88]   [-3000,-2625] --> [-41,3554]    [1500,1750] --> [14591,16718]   [-250,-125] --> [-306,194]      [125,250] --> [-355,144]        [0,125] --> [-177,319]
.. [-312,-250] --> [-473,88]    [-3000,-2812] --> [-41,1766]    [1625,1750] --> [15647,16718]   [-187,-125] --> [-53,194]       [187,250] --> [-107,144]        [0,62] --> [-177,66]
.. [-281,-250] --> [-197,88]    [-3000,-2906] --> [-41,861]     [1687,1750] --> [16174,16718]   [-187,-156] --> [-53,70]        [187,218] --> [-107,16] [31,62] --> [-57,66]
..      XAccel                  YAccel                          ZAccel                  XGyro                   YGyro                   ZGyro
 [-265,-250] --> [-55,88]       [-3000,-2953] --> [-41,400]     [1687,1718] --> [16174,16449]   [-187,-171] --> [-53,10]        [202,218] --> [-47,16]  [31,46] --> [-57,2]
.. [-265,-257] --> [-55,15]     [-3000,-2976] --> [-41,185]     [1702,1718] --> [16303,16449]   [-179,-171] --> [-21,10]        [210,218] --> [-15,16]  [38,46] --> [-29,2]
.. [-261,-257] --> [-18,15]     [-3000,-2988] --> [-41,76]      [1710,1718] --> [16377,16449]   [-175,-171] --> [-6,10] [214,218] --> [0,16]    [42,46] --> [-13,2]
.. [-259,-257] --> [0,15]       [-3000,-2994] --> [-41,13]      [1710,1714] --> [16377,16411]   [-175,-173] --> [-6,2]  [214,216] --> [0,8]     [44,46] --> [-5,2]
.. [-259,-258] --> [0,18]       [-2997,-2994] --> [-23,13]      [1710,1712] --> [16377,16395]   [-174,-173] --> [-1,2]  [214,215] --> [0,4]     [45,46] --> [-1,2]
averaging 10000 readings each time
....................    XAccel                  YAccel                          ZAccel                  XGyro                   YGyro                   ZGyro
 [-259,-258] --> [0,18] [-2995,-2994] --> [-3,13]       [1711,1712] --> [16379,16395]   [-174,-173] --> [-1,2]  [214,215] --> [0,4]     [45,46] --> [-1,2]
.................... [-259,-258] --> [-1,18]    [-2995,-2994] --> [-3,13]       [1711,1712] --> [16379,16395]   [-174,-173] --> [-1,2]  [214,214] --> [0,1]     [45,46] --> [-1,2]
-------------- done --------------
```

**3. Run**
```
at 600 Readings
-262.00000,     -2995.00000,    1712.00000,     -173.00000,     213.00000,      46.00000

>.>.700 Total Readings
-262.00000,     -2993.00000,    1710.00000,     -173.00000,     212.00000,      45.00000

>.>.800 Total Readings
-262.00000,     -2993.00000,    1710.00000,     -174.00000,     212.00000,      47.00000

>.>.900 Total Readings
-262.00000,     -2993.00000,    1710.00000,     -173.00000,     212.00000,      46.00000

>.>.1000 Total Readings
-262.00000,     -2993.00000,    1710.00000,     -173.00000,     213.00000,      46.00000

 Any of the above offsets will work nice

 Lets proof the PID tuning using another method:
averaging 1000 readings each time
expanding:
....    XAccel                  YAccel                          ZAccel                  XGyro                   YGyro                   ZGyro
 [0,0] --> [2395,2392]  [0,0] --> [28818,28820] [0,0] --> [1849,1845]   [0,0] --> [691,692]     [0,0] --> [-849,-849]   [0,0] --> [-181,-182]
.... [-1000,0] --> [-6734,2389] [-1000,0] --> [19194,28820]     [0,1000] --> [1850,10353]       [-1000,0] --> [-3305,690]       [0,1000] --> [-850,3146]        [0,1000] --> [-182,3813]
.... [-1000,0] --> [-6731,2393] [-2000,0] --> [9568,28816]      [0,2000] --> [1846,18853]       [-1000,0] --> [-3305,690]       [0,1000] --> [-846,3147]        [0,1000] --> [-178,3813]
.... [-1000,0] --> [-6733,2392] [-3000,0] --> [-56,28818]       [0,2000] --> [1850,18850]       [-1000,0] --> [-3304,690]       [0,1000] --> [-846,3146]        [0,1000] --> [-178,3813]

closing in:
..      XAccel                  YAccel                          ZAccel                  XGyro                   YGyro                   ZGyro
 [-500,0] --> [-2169,2392]      [-3000,-1500] --> [-56,14382]   [1000,2000] --> [10346,18850]   [-500,0] --> [-1306,690]        [0,500] --> [-846,1152] [0,500] --> [-178,1818]
.. [-500,-250] --> [-2169,112]  [-3000,-2250] --> [-56,7164]    [1500,2000] --> [14601,18850]   [-250,0] --> [-307,690] [0,250] --> [-846,151]  [0,250] --> [-178,818]
.. [-375,-250] --> [-1037,112]  [-3000,-2625] --> [-56,3541]    [1500,1750] --> [14601,16722]   [-250,-125] --> [-307,192]      [125,250] --> [-348,151]        [0,125] --> [-178,318]
.. [-312,-250] --> [-456,112]   [-3000,-2812] --> [-56,1755]    [1625,1750] --> [15650,16722]   [-187,-125] --> [-54,192]       [187,250] --> [-101,151]        [0,62] --> [-178,65]
.. [-281,-250] --> [-182,112]   [-3000,-2906] --> [-56,850]     [1687,1750] --> [16180,16722]   [-187,-156] --> [-54,69]        [187,218] --> [-101,23] [31,62] --> [-58,65]
..      XAccel                  YAccel                          ZAccel                  XGyro                   YGyro                   ZGyro
 [-265,-250] --> [-34,112]      [-3000,-2953] --> [-56,384]     [1687,1718] --> [16180,16455]   [-187,-171] --> [-54,9] [202,218] --> [-41,23]  [31,46] --> [-58,1]
.. [-265,-257] --> [-34,37]     [-3000,-2976] --> [-56,173]     [1702,1718] --> [16320,16455]   [-179,-171] --> [-22,9] [210,218] --> [-9,23]   [38,46] --> [-30,1]
.. [-265,-261] --> [-34,2]      [-3000,-2988] --> [-56,58]      [1710,1718] --> [16382,16455]   [-175,-171] --> [-5,9]  [210,214] --> [-9,5]    [42,46] --> [-14,1]
.. [-263,-261] --> [-15,2]      [-2994,-2988] --> [0,58]        [1710,1714] --> [16382,16421]   [-175,-173] --> [-5,1]  [212,214] --> [-1,5]    [44,46] --> [-6,1]
.. [-262,-261] --> [0,2]        [-2994,-2991] --> [0,19]        [1710,1712] --> [16382,16403]   [-174,-173] --> [-2,1]  [212,213] --> [-1,3]    [45,46] --> [-2,1]
averaging 10000 readings each time
....................    XAccel                  YAccel                          ZAccel                  XGyro                   YGyro                   ZGyro
 [-262,-262] --> [0,1]  [-2994,-2992] --> [0,20]        [1711,1712] --> [16384,16403]   [-174,-173] --> [-2,1]  [212,213] --> [-1,3]    [45,46] --> [-2,1]
.................... [-262,-262] --> [0,1]      [-2994,-2993] --> [0,1] [1711,1712] --> [16381,16403]   [-174,-173] --> [-2,1]  [212,213] --> [-1,3]    [45,46] --> [-2,1]
.................... [-262,-262] --> [0,1]      [-2994,-2994] --> [0,2] [1711,1712] --> [16382,16403]   [-174,-173] --> [-2,1]  [212,213] --> [0,3]     [45,46] --> [-3,1]
-------------- done --------------
```

## Pointing finger

### Average
```
[-6017,-6016] --> [-14,4]  [1391,1392] --> [-9,9]  [1383,1384] --> [16374,16389]   [66,67] --> [0,3]       [-86,-85] --> [-1,3]    [35,36] --> [-1,2]
[-6019,-6018] --> [-1,16]  [1391,1392] --> [-12,4] [1385,1386] --> [16379,16397]   [66,67] --> [-2,1]      [-86,-85] --> [0,4]     [35,35] --> [0,1]
[-6019,-6019] --> [0,1]    [1397,1398] --> [-7,10] [1385,1386] --> [16376,16390]   [66,67] --> [-2,1]      [-86,-85] --> [-2,1]    [35,36] --> [0,3]
---
[-6018.0, 1393.5, 1384.8, 66.5, -85.5, 35.3]
{-6018, 1394, 1385, 66, -86, 35}
```

**1. Run**
```
>**......>......
at 600 Readings
-6016.00000,    1392.00000,     1382.00000,     67.00000,       -86.00000,      35.00000

>.>.700 Total Readings
-6016.00000,    1392.00000,     1382.00000,     66.00000,       -86.00000,      36.00000

>.>.800 Total Readings
-6016.00000,    1392.00000,     1382.00000,     66.00000,       -86.00000,      35.00000

>.>.900 Total Readings
-6016.00000,    1390.00000,     1382.00000,     68.00000,       -86.00000,      35.00000

>.>.1000 Total Readings
-6014.00000,    1390.00000,     1382.00000,     66.00000,       -86.00000,      36.00000

 Any of the above offsets will work nice

 Lets proof the PID tuning using another method:
averaging 1000 readings each time
expanding:
....    XAccel                  YAccel                          ZAccel                  XGyro                   YGyro                   ZGyro
 [0,0] --> [32767,32767]        [0,0] --> [-11996,-11993]       [0,0] --> [4985,4982]   [0,0] --> [-265,-266]   [0,0] --> [343,344]     [0,0] --> [-141,-141]
.... [-1000,0] --> [32767,32767]        [0,1000] --> [-11998,-3375]     [0,1000] --> [4982,13232]       [0,1000] --> [-265,3732]        [-1000,0] --> [-3652,342]       [0,1000] --> [-141,3855]
.... [-2000,0] --> [32767,32767]        [0,2000] --> [-11998,5253]      [0,2000] --> [4982,21482]       [0,1000] --> [-263,3733]        [-1000,0] --> [-3654,340]       [0,1000] --> [-137,3855]
.... [-3000,0] --> [29406,32767]        [0,2000] --> [-11999,5255]      [0,2000] --> [4980,21473]       [0,1000] --> [-262,3732]        [-1000,0] --> [-3652,340]       [0,1000] --> [-137,3854]
.... [-4000,0] --> [19655,32767]        [0,2000] --> [-11996,5252]      [0,2000] --> [4979,21478]       [0,1000] --> [-263,3732]        [-1000,0] --> [-3653,340]       [0,1000] --> [-137,3854]
....    XAccel                  YAccel                          ZAccel                  XGyro                   YGyro                   ZGyro
 [-5000,0] --> [9907,32767]     [0,2000] --> [-11998,5253]      [0,2000] --> [4977,21477]       [0,1000] --> [-262,3732]        [-1000,0] --> [-3652,340]       [0,1000] --> [-137,3855]
.... [-6000,0] --> [160,32767]  [0,2000] --> [-11994,5254]      [0,2000] --> [4975,21476]       [0,1000] --> [-263,3733]        [-1000,0] --> [-3652,340]       [0,1000] --> [-137,3855]
.... [-7000,0] --> [-9591,32767]        [0,2000] --> [-11999,5249]      [0,2000] --> [4980,21478]       [0,1000] --> [-263,3733]        [-1000,0] --> [-3653,341]       [0,1000] --> [-137,3854]

closing in:
..      XAccel                  YAccel                          ZAccel                  XGyro                   YGyro                   ZGyro
 [-7000,-3500] --> [-9591,24533]        [1000,2000] --> [-3373,5249]    [1000,2000] --> [13226,21478]   [0,500] --> [-263,1735] [-500,0] --> [-1655,341]        [0,500] --> [-137,1860]
.. [-7000,-5250] --> [-9591,7471]       [1000,1500] --> [-3373,936]     [1000,1500] --> [13226,17348]   [0,250] --> [-263,735]  [-250,0] --> [-657,341] [0,250] --> [-137,859]
.. [-6125,-5250] --> [-1069,7471]       [1250,1500] --> [-1218,936]     [1250,1500] --> [15282,17348]   [0,125] --> [-263,235]  [-125,0] --> [-157,341] [0,125] --> [-137,359]
.. [-6125,-5687] --> [-1069,3203]       [1375,1500] --> [-146,936]      [1375,1500] --> [16308,17348]   [62,125] --> [-16,235]  [-125,-62] --> [-157,94]        [0,62] --> [-137,107]
.. [-6125,-5906] --> [-1069,1077]       [1375,1437] --> [-146,385]      [1375,1437] --> [16308,16821]   [62,93] --> [-16,107]   [-93,-62] --> [-27,94]  [31,62] --> [-17,107]
..      XAccel                  YAccel                          ZAccel                  XGyro                   YGyro                   ZGyro
 [-6125,-6015] --> [-1069,4]    [1375,1406] --> [-146,127]      [1375,1406] --> [16308,16576]   [62,77] --> [-16,42]    [-93,-77] --> [-27,34]  [31,46] --> [-17,42]
.. [-6070,-6015] --> [-519,4]   [1390,1406] --> [-8,127]        [1375,1390] --> [16308,16439]   [62,69] --> [-16,11]    [-93,-85] --> [-27,3]   [31,38] --> [-17,9]
.. [-6042,-6015] --> [-249,4]   [1390,1398] --> [-8,59] [1382,1390] --> [16375,16439]   [65,69] --> [-4,11]     [-89,-85] --> [-13,3]   [34,38] --> [-5,9]
.. [-6028,-6015] --> [-115,4]   [1390,1394] --> [-8,25] [1382,1386] --> [16375,16410]   [65,67] --> [-4,3]      [-87,-85] --> [-4,3]    [34,36] --> [-5,2]
.. [-6021,-6015] --> [-55,4]    [1390,1392] --> [-8,9]  [1382,1384] --> [16375,16389]   [66,67] --> [0,3]       [-86,-85] --> [-1,3]    [35,36] --> [-1,2]
..      XAccel                  YAccel                          ZAccel                  XGyro                   YGyro                   ZGyro
 [-6018,-6015] --> [-14,4]      [1391,1392] --> [-8,9]  [1383,1384] --> [16381,16389]   [66,67] --> [0,3]       [-86,-85] --> [-1,3]    [35,36] --> [-1,2]
averaging 10000 readings each time
.................... [-6018,-6016] --> [-14,4]  [1391,1392] --> [-7,9]  [1383,1384] --> [16374,16389]   [66,67] --> [0,3]       [-86,-85] --> [-1,3]    [35,36] --> [-1,2]
.................... [-6017,-6016] --> [-13,4]  [1391,1392] --> [-9,9]  [1383,1384] --> [16371,16389]   [66,67] --> [0,3]       [-86,-85] --> [-1,3]    [35,36] --> [-1,2]
.................... [-6017,-6016] --> [-14,4]  [1391,1392] --> [-9,9]  [1383,1384] --> [16374,16389]   [66,67] --> [0,3]       [-86,-85] --> [-1,3]    [35,36] --> [-1,2]
-------------- done --------------
```

**2. Run**
```
at 600 Readings
-6020.00000,    1393.00000,     1382.00000,     67.00000,       -86.00000,      36.00000

>.>.700 Total Readings
-6018.00000,    1393.00000,     1384.00000,     66.00000,       -86.00000,      37.00000

>.>.800 Total Readings
-6020.00000,    1393.00000,     1384.00000,     67.00000,       -85.00000,      36.00000

>.>.900 Total Readings
-6020.00000,    1393.00000,     1382.00000,     67.00000,       -85.00000,      36.00000

>.>.1000 Total Readings
-6020.00000,    1393.00000,     1382.00000,     66.00000,       -84.00000,      35.00000

 Any of the above offsets will work nice

 Lets proof the PID tuning using another method:
averaging 1000 readings each time
expanding:
....    XAccel                  YAccel                          ZAccel                  XGyro                   YGyro                   ZGyro
 [0,0] --> [32767,32767]        [0,0] --> [-12000,-11998]       [0,0] --> [4968,4964]   [0,0] --> [-265,-266]   [0,0] --> [342,343]     [0,0] --> [-140,-140]
.... [-1000,0] --> [32767,32767]        [0,1000] --> [-11999,-3375]     [0,1000] --> [4972,13219]       [0,1000] --> [-265,3732]        [-1000,0] --> [-3654,339]       [0,1000] --> [-140,3855]
.... [-2000,0] --> [32767,32767]        [0,2000] --> [-12002,5250]      [0,2000] --> [4963,21468]       [0,1000] --> [-264,3732]        [-1000,0] --> [-3654,340]       [0,1000] --> [-135,3856]
.... [-3000,0] --> [29440,32767]        [0,2000] --> [-12000,5245]      [0,2000] --> [4974,21472]       [0,1000] --> [-263,3732]        [-1000,0] --> [-3652,341]       [0,1000] --> [-135,3856]
.... [-4000,0] --> [19690,32767]        [0,2000] --> [-11999,5248]      [0,2000] --> [4964,21471]       [0,1000] --> [-264,3732]        [-1000,0] --> [-3653,340]       [0,1000] --> [-135,3856]
....    XAccel                  YAccel                          ZAccel                  XGyro                   YGyro                   ZGyro
 [-5000,0] --> [9940,32767]     [0,2000] --> [-12002,5250]      [0,2000] --> [4967,21464]       [0,1000] --> [-263,3733]        [-1000,0] --> [-3652,341]       [0,1000] --> [-135,3856]
.... [-6000,0] --> [194,32767]  [0,2000] --> [-12001,5248]      [0,2000] --> [4964,21467]       [0,1000] --> [-264,3731]        [-1000,0] --> [-3653,340]       [0,1000] --> [-135,3857]
.... [-7000,0] --> [-9556,32767]        [0,2000] --> [-11998,5250]      [0,2000] --> [4967,21468]       [0,1000] --> [-264,3732]        [-1000,0] --> [-3653,340]       [0,1000] --> [-135,3856]
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

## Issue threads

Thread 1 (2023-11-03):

Analyzing/optimzing timing and speed of data acquisition

xjjak, 2023-11-03:
One full reading of all 6 sensors takes *x* ms. (*How long does it actually take?*) Can this be improved?

**1 Idea**: Resetting all FIFO buffers of the DMPs before starting to read each of them.
- Does the first buffer fill up before it is watched again?
- How many buffers could be cleared ahead of time?

xjjak, 2023-11-14:
The results of the first analysis:
```
Avg. Mux switch (3969): 181
Avg. Buf reset (3968): 425
Avg. Buf wait (3968): 4767
Avg. Buf read (3968): 1288
```
The values are in microseconds and are averaged across the number of readings also given in the parentheses.

The next evaluation includes a larger dataset and an additional measurement of the time taken for the whole reading process:
```
Avg. Mux switch (12956): 175
Avg. Buf reset (12956): 426
Avg. Buf wait (12956): 4673
Avg. Buf read (12956): 1282
Avg. reading of all sensors (2592): 59626
```

After implementing a first optimization, resetting the FIFO buffers of all sensors, before starting to read from the first one, an improvement of `~7ms` for the whole reading process could be noted:
```
Avg. Mux switch (5173): 142
Avg. Buf reset (5174): 0
Avg. Buf wait (5174): 878
Avg. Buf read (5173): 1274
Avg. reading of all sensors (1035): 52549
```
Here, it can also be seen, that this decreased the duration of the avg. waiting period for the buffer to fill up, significantly from `~4700` to `~900`. The overall improvement is much less though, as the sensors' buffers still have to be reset beforehand and be switched to on the multiplexer.

Although it makes little sense, resetting the last sensor and going from "right-to-left", as small improvement of `~200` could be noted.
```
Avg. Mux switch (5525): 111
Avg. Buf reset (5525): 0
Avg. Buf wait (5525): 957
Avg. Buf read (5525): 1278
Avg. reading of all sensors (1105): 52391
```
This must be a statistical error.

This report also includes a measurement of the time taken in the rest of one iteration in the main loop, after reading from the sensors (`After reading`):
```
Avg. Mux switch (4333): 135
Avg. Buf reset (4333): 0
Avg. Buf wait (4333): 208
Avg. Buf read (4333): 1297
Avg. reading of all sensors (867): 65413
Avg. After reading (867): 17068
```

Although the improvement is minor, there was one. Now a next idea for optimization includes utilizing the [second processor](https://randomnerdtutorials.com/esp32-dual-core-arduino-ide/) in the ESP32 to reset all sensors while the readings are getting processed and the rest of the loop is executed.

xjjak, 2023-11-17:
Using `xTaskCreatePinnedToCore`, a task can be implemented in freeRTOS. These should run continually, so the callback `task_fifo_reset` contains an infinite for loop, that waits for the flag `task_reset_fifos_flag` to be set to true.
Setting it back to `false` doesn't work yet though, due to pointer fuckery #12 .

xjjak, 2023-11-17:
As mentioned in the resolved #12 the pointer issues were resolved by using the proper way to handle flags in tasks.

Although parallelization worked in principle, no improvements were noticeable, the measurements rather worsened. After testing with and without parallelization and `reset_all_bufs()` at the start and end of `get_all_readings()`, the readings were making no sense, at around `60ms` for *Avg. reading of all sensors*.

The only thing left to try was to take out most of the smaller "breakpoints".  This was introduced to make en- and disabling them convenient:
```cpp
#define __TIMING(format)   if (TIMING_ENABLED) {Serial.printf(format, micros()-prev_micros); prev_micros = micros();}
const int TIMING_ENABLED = 0;
```

After disabling all outputs except for *Avg. readings of all sensors* (`All readings`) the results even without parallelization were as surprising as astonishing, achieving `~11ms` per reading cycle. Re-enabling the execution of `reset_all_bufs()` on *Core 0* further brought this down to **~8.5ms per gathering** while the time taken for the rest of the main loop remained at about `11ms`.

In comparison to previous measurements, the recorded time between measurements in total was *~50ms*, now being around *~20ms*, which is an **improvement of ~30ms**.

The only options for further improvement coming to mind at this point in time is improving on the rest of the main loop, moving from string output to binary, both over Serial and to SDcard.

Closed 2023-11-18.

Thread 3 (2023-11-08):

Virtual keyboard tool does not recognize some touch releases properly

palisn, 2023-11-08:
**Problem**

When you press any key on the virtual keyboard, the press is logged as expected. But if this press is released beside the key it was started on or on another key, nothing or the other key will be logged. This has resulted in more inconsistencies in the data than expected. To make the collected data reliable this should be fixed.

**Possible Solution**

One possible solution might be, to keep track of all current presses and consider the press closest to the release location as released. Another similar approach, that is a bit more sophisticated, is to not only keep track of the press start and end location but also update the press locations on drag events. While this is more sophisticated it is probably unnecessarily complex.

Closed 2023-11-17.

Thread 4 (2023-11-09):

[FEATURE] Stream Serial Data over Bluetooth

xjjak, 2023-11-09:
Enable pairing of a glove to a computer and stream the Serial output over Bluetooth instead of having to connect a cable or just recording the data on the sd-card.

Use the [BluetoothSerial](https://github.com/espressif/arduino-esp32/tree/master/libraries/BluetoothSerial) library and test if connecting to a PC works. Then potentially replace [BLESerial](https://github.com/avinabmalla/ESP32_BleSerial) to save power.

xjjak, 2023-12-17:
The ESP32 we use does have `16MB` flash. To be able to use this, these lines had to be added to the `platformio.ini`:
```
board_upload.flash_size = 16MB
board_upload.maximum_size = 16777216
board_build.partitions = default_16MB.csv
```
This came up because when the BLESerial lib was added, the program size was larger than what PIO allowed.

xjjak, 2023-12-17:
The simple example of calling `ble.begin("BLESerialTest");` and `ble.println("Hello World!");` worked flawlessly. Both with an Android App and [this library](https://github.com/Jakeler/ble-serial) creating a virtual port the standard serial monitor can connect to.
Looking at the `micros()` timestamps without any sensors connected, the time difference between readings, after enabling them again, was about `1000` though.

A bigger problem now is, that when actually connecting sensors, `Wire.h` reports the follow error repeatedly:
```
[  9524][E][Wire.cpp:392] requestFrom(): i2cRead returned Error 263
```
Followed by the parallelized task on the other core timing out waiting for events.
The sensors can't be read, the BLE library is somehow blocking the I2C communication, if I remember correctly.

xjjak, 2023-12-18:
Well, my assumption was correct and the [BLE library](https://github.com/espressif/arduino-esp32/tree/master/libraries/BLE) uses parallelization as well and is probably interfering. I have to dig deeper here and would need to find out exactly what is done where and when.

xjjak, 2024-02-03:
We have now decided to disable parallelization temporarily and implement BLE first, but with minimal data output, not using strings as discussed in #14.

So this issue will be superseded by #32.

Closed 2024-02-03.

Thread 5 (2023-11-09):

[PLAN] Neural network compression for embedded hardware

xjjak, 2023-11-09:
Get the SVN and later the neural network to run on the ESP32 and test performance.

Requires developing a process to compress the results of machine learning and integrating it into the firmware.

Result will be alternate Firmware option: *Detection* instead of *Collection*

xjjak, 2024-03-16:
Reading list:
- https://dev.to/tkeyo/tinyml-machine-learning-on-esp32-with-micropython-38a6
- https://luvsheth.com/p/running-a-pytorch-machine-learning
- https://www.hackster.io/news/porting-deep-learning-models-to-embedded-systems-a-solved-challenge-2cb96ce27fbc

xjjak, 2025-01-14:
In case, we use the RP2040/RP2350: [pico-tflmicro](https://github.com/raspberrypi/pico-tflmicro)

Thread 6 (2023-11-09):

[IDEA] Simulating sensor data

xjjak, 2023-11-09:
**Describe the vision. What is to be achieved? What does the end-result look like? Is it a specific feature?**

Develop a simulation to simulate data gathered by the IMUs on all fingers for strings (?) that infer a specific keyboard input sequence.
1. Set the position of the sensor on a finger and get the expected values for the sensor's output according to the laws of physics (Single finger with 3, or 6 for index fingers, positions).
2. Then there could also be a mode which purposefully introduces errors and can generate realistic datasets for training purposes (all fingers).
3. Graphical representation, in Unity for example??

**Share possible solutions or ideas and approaches.**

Just a few thoughts so far:
- configuration of the finger: length between joints
- 3 different simulations for the finger types
    - thumb (2 positions, lateral motion)
    - index finger (6 positions, lateral and frontal)
    - all others (3 positions, frontal motion)
- use inverse kinematics to determine the expected angle
- record typing to determine velocity/acceleration

**Why?**
...

**Additional context**
Add any other context or screenshots about the feature request here.

CTropp, 2024-01-24:
Ich kann hier gerne etwas schreiben, ich weiß aber nicht wozu

CTropp, 2024-01-24:
I'd suggest to generate the data for the machine learning as accurate as possible. Using a simulation to get a huge amount of data might sound promising, but I have doubts in training an AI on simulated data and then try to apply these on the real machine.

Closed 2025-01-13.

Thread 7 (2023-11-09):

[FEATURE] General state detection

palisn, 2023-11-09:
Add a new model that predicts the current state of the imaginary keyboard. Optimally, this may introduce combined press and release detection and additional row detection in one go.

This depends on the data collection including multiple fingers and rows to work somewhat reliably. Thus, it depends on the issue #3.

palisn, 2023-11-18:
Issue #3 has now been resolved. After some data is collected, this can be actively worked on.

palisn, 2024-01-10:
Following sub-issues that are relevant to this issue were recently introduced:
- #28
- #29

palisn, 2024-02-04:
For testing purposes, we established a moderately large neural network consisting of four hidden layers, each 5000 neurons with the ReLU activation function, and a 17-neurons large output layer with sigmoid activation function. Additionally, each layer has L2 regularization.
```python
model = keras.Sequential(
    [
        layers.Input(shape=(179,)),
        layers.Dense(5000, activation = "relu",
                     kernel_regularizer=regularizers.l2(0.001)),
        layers.Dense(5000, activation = "relu",
                     kernel_regularizer=regularizers.l2(0.001)),
        layers.Dense(5000, activation = "relu",
                     kernel_regularizer=regularizers.l2(0.001)),
        layers.Dense(5000, activation = "relu",
                     kernel_regularizer=regularizers.l2(0.001)),
        layers.Dense(17, activation = "sigmoid")
    ]
)
```
We compiled the model with a `BinaryCrossentropy` loss – which is typically used for multi-label problems – and the `RMSProp` optimizer. Afterward, we trained the model with a batch size of 32 for 100 epochs (excluding early stopping).

The results show that the model does converge but yields terrible results for our positive class; thus, it does not perform well regarding our metric.

| Learning Rate | Loss | Metric | Convergence |
|--------|--------|--------|--------|
| `1-e3` | `0.03` | `0.29` | 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 |
| `5-e4` | `0.03` | `0.29` | 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 |
| `1-e4` | `0.03` | `0.43` | 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 |
| `5-e5` | `0.025` | `0.44` | 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 |

*(Warning: The x axes do not necessarily start at 0 to increase readability.)*

This emphasizes the issue that the dataset is unbalanced.  For better results, we should probably change the model architecture or introduce some counter-measure against the issue.
#29

palisn, 2024-02-04:
To address the largely different domains of the features, we introduced `Normalization` (also known as [Standardization](https://en.wikipedia.org/wiki/Standard_score)) into the model:
```python
inputs = layers.Input(shape=(179,))
normalizer = layers.Normalization()
normalizer.adapt(x_train)
x = normalizer(inputs)
for _ in range(4):
    x = layers.Dense(5000, activation = "relu", kernel_regularizer=regularizers.l2(0.001))(x)
outputs = layers.Dense(17, activation = "sigmoid")(x)
model = keras.Model(inputs, outputs)
```
This change caused visible improvement.  With a learning rate of `1-e4` and 100 epochs of training (the same setup as in the last message) we were able to achieve:
- a lower loss: `0.025`
- a better metric score: `0.55`
- better results for the positive class; $f_2$-score: `0.3` (as opposed to `0.2` before)
- still a bit more potential for further improvement with further training

palisn, 2024-02-04:
> still a bit more potential for further improvement with further training

After 315 epochs there is no more improvement and the result is:
- loss: `0.021`
- metric score: `0.69`
- $f_2$-score: `0.5`
Quite the improvement and validation shows that we are not overfitting.  But, it is still not enough to be usable in practice.

palisn, 2024-02-05:
As an alternative to `BinaryCrossentropy` we tried `BinaryFocalCrossentropy` as it is designed to help learn unbalanced datasets.  We were able to achieve a loss slightly below `0.01`. Surprisingly, this did not reflect on our metric or on results for positive class in general.

Closed 2025-03-24.

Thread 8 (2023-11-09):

[IDEA] Gimbal for IMU calibration

xjjak, 2023-11-09:
**Describe the vision. What is to be achieved? What does the end-result look like? Is it a specific feature?**
Build a small gimbal like piece, that enables accurate control of the three axis which has a slot for an IMU so it can be put into a specific position or even accelerated at a known rate to properly calibrate it.

**Share possible solutions or ideas and approaches.**
Connect three stepper motors in "series" and write controller software.

How can the SenseUnit be fixated in the rig so the relative position to the steppers origin is always the same, also for different SenseUnits?

**Are there alternative "solutions" that achieve the same? Are there drawbacks to this plan? What would not be possible if this path is chosen?**
Comparing the output of the sensors with the proposed simulation's could also be used for a sort of calibration. This could be a bit too much effort for the result, so it needs to be determined first, how accurate the calibration needs to be.

**Additional context**
Add any other context or screenshots about the feature request here.

xjjak, 2023-12-13:
Using 28byj-48 stepper motors, the hardware shouldn't be too complicated.

This could also be used to compare the quality of the different MPU6050 purchases.

Closed 2025-01-13.

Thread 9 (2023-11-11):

[PLAN] Replace glove design with rings for each individual finger

xjjak, 2023-11-11:
**Describe the vision. What is to be achieved? What does the end-result look like? Is it a specific feature?**
Instead of having the SenseUnits attached to a glove, 3D printed rings for each finger and some kind of strap for the motherboard should be the way to wear the glove. This would not only be a sleeker design, but also more lightweight and a more individual fit.

One problem to consider is how the individual rings are held together, since the cables as they are, are not enough. Perhaps a sleeved  cable would be enough, there needs to be a strain relief before the connectors though.

xjjak, 2023-12-05:
After fiddling with old USB cables, I concluded that they were either too brittle, or too stiff or even not even the right size, so I settled for the usual 4 individual wires with some heatshrink before the connectors as strain reliefs, which seem to work surprisingly well. Additionally, the wires get twisted to make them less flimsy.

By now, the ring design has gone through multiple iterations. Mounting the SenseUnits works by just pushing them into slots, which stick out too much, though. Instead of two connected (or even separated) rings is trashed. The thickness definitely has to be minimized, and hasn't yet been pushed to its limit. The right offset is also to be determined.
Putting gaps in the rings where the palm is may improve comfort and ability to wear the glove constantly, but while figuring out the right size and fit, it may be better to remove them.
Only the thumb requires them anyway, since the ring would otherwise hit the typing surface. There it could also be sufficient to put the ring on the first finger segment.

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

xjjak, 2023-12-11:
After adjusting the ring sizes a first iteration of a palm strap mount was designed (one prong snapped with the base being too thin and it was too large):

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

After thickening the base to 2mm and fixing the offset parameter to be in the right direction a first fit was achieved:

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

Slimming down the design by removing the overhangs over the ESP and the SD-card:

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

Followed by adding a cage for the battery:

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

xjjak, 2023-12-12:
While the 3D print design are mostly done, the actual strap is not. It remains to figure out the proper width and right fabric

xjjak, 2023-12-14:
The white strap material provides better stability, although a bit less comfortable. It should be attempted to decrease its width. If a cut made to decrease the strap by 5mm for example does not lead to it unraveling, this material would probably be the better choice when created in the right size.
The last consideration would be a possible overlap, to strap the *MoBo* onto, or if a single layer is sufficient.

xjjak, 2023-12-14:
There are now two straps in different sizes, one for each of us. They are slimmed down to about *25mm* and just sewed together at the ends with an overlap of a bit more than *5mm*.

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

I adjusted the *MoBo*-mount accordingly, but also flipped the prongs to make them counter a pull-on motion, which seems more practical than supporting strap-already-on-hand mounting. Another small addition were small catches opposite of the prongs holding the strap better.
The underside of the design now looks like this:

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

xjjak, 2023-12-15:
The changes work quite well, the only issue is the stand-off caused by the strap underneath the *MoBo*. The thickness parameter could be the solution to lessen the strain on the PCB. One other idea is to "emboss" the strap into the prongs, making only them 1mm thick with the surrounding base remaining at 2mm thickness, to reduce the offset under the *MoBo*.

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

xjjak, 2023-12-17:
Embedding the strap worked very well.

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

I also adjusted a few more parameters, thickening the base, enlarging the strap catch and adjusting the *MoBo* width. These are now the current parameters, which make for a snug fit:
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

**The end result:**

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

Closed 2023-12-17.

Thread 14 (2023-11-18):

[PLAN] Further optimize frequency of measurements with binary output

xjjak, 2023-11-18:
Instead of sending a `char[]` over Serial or writing it as a string to the SD card, establish a binary format to use.

This may also involve finding alternatives to a whole file system on the SD card and lower level write methods. How far to go with this needs to be determined.

xjjak, 2023-12-13:
The goal should be to develop a simple "*protocol*", which only uses bytes, perhaps specifically optimized for streaming over BLE (following in the footsteps of the results of #4), but also applicable to serial data transmission, since a wireless method would not unnecessarily use the SD card also providing more comparable timing of the data during collection as it would be during use.

Something like this is described [here](https://tams.informatik.uni-hamburg.de/paper/2017/BSc-Paul-Bienkowski.pdf). I only discovered this today and their approach may provide some inspiration.

xjjak, 2023-12-18:
Only thought of this now: Before this whole thing is attempted, it could be an easier optimization to skip the buffers and just print to `Serial` or the SD card directly.

xjjak, 2024-10-15:
Along with moving away from ble-serial to "raw" BLE, I created the first verison of a binary protocol, although calling this a protocol would be too much, rather a  format.
The format is similar to the string format used before:
`timestamp:s1.a.x;s1.a.y;s1.g.x;s1.g.y;s1.g.z:s2.a.;...:...:s6.g.z:`
The timestamp is a `uint64_t` and all values are `int16_t`. All of these are just concatenated into a 80 bytes long array.

This is currently only a one-way "protocol", which is why I'd rather call it format as it stands.

Further optimization could only be done by decreasing value accuracy to require less bits.

Closed 2025-01-14.

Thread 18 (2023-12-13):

[IDEA] Dongle for keyboard emulation and interfacing with the target device

xjjak, 2023-12-13:
**Describe the vision. What is to be achieved? What does the end-result look like? Is it a specific feature?**

By creating a dongle with a USB-C connector, there would be a quite universal way to interface with most machines using the gloves.
The gloves would both establish a BLE connection to the dongle, acting as the server unifying the inputs, emulating the keyboard.
Depending on BLE speeds and performance of the motherboard MCU, it may be worth it to choose a more powerful chip like an [STM32F2](https://www.st.com/en/microcontrollers-microprocessors/stm32-32-bit-arm-cortex-mcus.html) to offload the neural network processing on. The ESPs would then only stream new sensor data as fast as possible.

Another consideration to make would be the place where the last readings are buffered. If the ESP32s are powerful enough to do the keystroke processing and only send the press and release events of the 17 keys on each hand, it should be looked into letting multiple data packets be stored in the FIFO buffer and reading and sending them together.

**Share possible solutions or ideas and approaches.**
The design is relatively simple, just requiring a male USB-C plug, a USB driver IC and an MCU. That could be another ESP32 with an custom onboard antenna or like previously mentioned a more powerful processor, like a Cortex-M3, which would require an external IC for wireless communication.
The footprint should not exceed  that of  a small USB-C flash drive.

**Are there alternative "solutions" that achieve the same? Are there drawbacks to this plan? What would not be possible if this path is chosen?**

There would be another part to carry, and a free port in the target device has to be free.
This is negligible to the hassle of possibly installing drivers and reduces complexity trying to use one of the hands as both a server for the other hand and a client connected to the target device.

**Additional context**
Add any other context or screenshots about the feature request here.

Closed 2025-01-13.

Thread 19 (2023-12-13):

[FEATURE] PlatformIO environments for different handed gloves

xjjak, 2023-12-13:
For a second glove, that is supposed to be a right-hand one, there would need to be changes to the implementation of the sensors and calibration configuration.

PlatformIO environments and flash parameters could be utilized to specify the targeted hand so that configurations and the reversing of the order of sensors are changed accordingly.
For the calibration values should be stored in external files and only be inserted during compilation (like the Wi-Fi credentials) using said environments.

palisn, 2023-12-15:
If we want to use the same model, we will probably have to mirror/negate some values, at least the ones that involve lateral movement, as not doing so may imply incorrect predictions at worst and predicting some keys in the wrong order at best. For consistency I would imagine negating all the x- and y-accelerations as well as z- and possibly x-axis rotation might yield the best results.

xjjak, 2024-02-09:
I initially tried flipping the order of the sensors using two different for loops. This is way too unclean, so here is what to do next:
- [ ] Change `bool sensor_presence[]` to store `int`s and store the mux channel ids
- [ ] Iterate over sensor array
- [ ] `-1` -> sensor's missing
- [ ] `setup_sensors()` for use in `main.cpp`

xjjak, 2024-02-09:
@palisn You previously proposed to *negate*:
- *x, y, accel*
- *x rotation*(?)

Is this the first final decision or do you recommend any other changes?
We'll be training a different model per hand anyway though, right? Would this still be necessary then?

palisn, 2024-02-12:
> Is this the first final decision or do you recommend any other changes? We'll be training a different model per hand anyway though, right? Would this still be necessary then?

I can't think of any other necessary changes right now, but even if we train a different model per hand, I would still keep the change, as we might be able to use data from the other hand respectively to improve the training process.

Closed 2024-02-13.

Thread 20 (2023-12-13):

[IDEA] Motherboard V2

xjjak, 2023-12-13:
**A place to collect changes to be made to a possible second version of the motherboard**

One major change I would propose is replacing the SD-card slot with a LiPo-battery charging circuit, as this would be generally more useful, as the slot would be rendered useless if BLE data transmission works as proposed in #14, because the data could then be streamed to another ESP or even a PC directly for collection.

Some minor changes could be the selection of a different reset button with a larger footprint and perhaps adding an general-purpose button, as well as moving the onboard-IMU to a more accessible location easing assembly.

Closed 2025-01-13.

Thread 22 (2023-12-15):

[FEATURE] Virtual keyboard: map inaccurate presses to nearest key

palisn, 2023-12-15:
**Is your feature request related to a problem? Please describe.**
Collecting data with the current version of the virtual keyboard is always a bit of a hassle and quite slow because it takes a conscious effort to really hit the keys and keep the hand in proper position due to the lack of haptic feedback. Further, every press that was intended to hit a key but missed it slightly may significantly reduce the quality of the dataset.

**Describe the solution you'd like**
A simple solution would be to remove the gaps between the keys, if not visually, at least when processing touches. This would enable us to map every position on the canvas to a concrete key, the nearest one. It completely removes the hazard of missing some intentional presses, and should also slightly improve accuracy. But we will most likely have to think of a physical solution to reduce the effort to keep the hand in place.

**Describe alternatives you've considered**
Another solution might be to switch to a more haptical input method for collecting data, but this would be a suboptimal solution as it introduces a bias for the acceleration data.

**Additional context**
A mapping of press location to the nearest key (the center of the key) would look like this:
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
In the picture, each color represents a specific key.

Closed 2023-12-17.

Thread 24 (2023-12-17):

[ERROR] Remaining timing debug output

xjjak, 2023-12-17:
In `sensors.cpp` there are leftover timing output which do not use `__TIMING` and are still enabled:

```cpp
    Serial.printf("after reset: %d \n", micros() - prev_micros);
    prev_micros = micros();

    uxBits = xEventGroupGetBits(FifoResetEventGroup);
    while((uxBits & BIT_0) != 0){
        uxBits = xEventGroupGetBits(FifoResetEventGroup);
    }

    Serial.printf("Before get: %d \n", micros() - prev_micros);
    prev_micros = micros();
```

Closed 2023-12-17.

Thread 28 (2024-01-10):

[FEATURE] State Detection: Define suitable single value metric

palisn, 2024-01-10:
_This is related #7._

A single value metric for more straight-forward model optimization should be introduced. The metric should be a single value composed of multiple weighted desired properties and result in a good estimation of how well the model fits our criteria.

A possible composition might include:
- **(Binary) Accuracy** to encourage a model that predicts most inputs correctly. Though, due to the unbalanced nature of our data, this is likely to push for correct classification of the negative class and not pay much attention to the positive class. Therefore, this should probably not have a high weight if it is included.
- **Precision** to discourage misclassification of negative class samples. It is undesirable to have random key presses when the fingers are resting or moving casually. Thus, it might be reasonable to incorporate it into the metric to some degree, though the same issue as with accuracy applies.
- **Recall** to encourage predicting positive class samples correctly. This can counter the unbalanced nature of the dataset and if along with precision properly weighted determine how more desirable it should be to misclassify positive class samples than negative class samples.
- **AUC** can only be maximized when the decision boundary gets bigger. Hence, incorporating AUC into the metric might force the model to maximize its decision boundary and thus cultivate confidence.

Further considerations concerning the metric include:
- A re-definition of positive and negative classes might be beneficial for a representative metric. Specifically, the positive class currently contains state changes, like pressing or releasing a finger, as well as readings where the finger is pressed down. Because the dataset is unbalanced, the learning algorithm will when properly configured give more weight to the positive class. But, a resting finger, regardless which position it is in, should not have as much weight as a finger that is changing its position or performs a gesture.

palisn, 2024-01-17:
As a replacement for the _AUC,_ one could also consider some kind of distance function that would promote confidence, like a normalized Euclidean distance.

palisn, 2024-01-18:
> As a replacement for the _AUC,_ one could also consider some kind of distance function that would promote confidence, like a normalized Euclidean distance.

For now, we opt for the average [Manhattan distance](https://en.wikipedia.org/wiki/Taxicab_geometry) converted to a suitable metric from 0 to 1 instead of AUC. This is mostly due to complications with the implementation of the metric, where AUC and a normalized Euclidean distance are not reasonably easy to integrate. We decided to finish the metric with our current implementation and allow for future changes because we wanted to choose it quickly.

palisn, 2024-01-18:
The combined metric for now is a weighted average with the following composition
| Weight (%) | Metric |
|--------|--------|
| 60 | [`fbeta`](https://en.wikipedia.org/wiki/F-score) mit $\beta = 2$ |
| 20 | [`binary_accuracy`](https://www.tensorflow.org/api_docs/python/tf/keras/metrics/BinaryAccuracy) |
| 10 | [`precision`](https://en.wikipedia.org/wiki/Precision_and_recall) |
| 10 | `inv_distance` |

where, if $\overline{d}$ is the average difference between the prediction and the actual label, `inv_distance` is defined as
$\texttt{inv\\_distance} = \text{clip}(1 - 2 \cdot \overline{d}, 0, 1)$.

palisn, 2024-01-22:
Commit 42ef6e4db30e485756bef918f6e0615aa341d3b2 resolves this issue.

Closed 2024-01-22.

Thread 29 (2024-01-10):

State Detection: Adjustments for unbalanced dataset

palisn, 2024-01-10:
_This is related to #7._

Because we retrieve data from the IMUs at regular rates and most of the time the fingers are still rather than typing, our datasets are unbalanced where the positive class – state changes (and holding, see #28) – is a lot smaller than the negative class – disengaged fingers.

This issue collects and evaluates measures to prevent bad classification due to the unbalanced nature of the dataset. Some approaches include:
- Adjusted **cost function** and **metric** (#28)
- Resampling:
  - **Undersampling**
  - **Oversampling**
- Weighted samples

palisn, 2024-02-06:
This seems related and might be interesting:
https://www.tensorflow.org/tutorials/structured_data/imbalanced_data

palisn, 2024-02-06:
We determined the samples where an internal state change happens with the following piece of code:
```python
standard_weight = 1
change_weight = 5 # example value

y_before = x_train[:,-17:]
changes = np.any(y_before != y_train, axis=1)

sample_weight = (changes*(change_weight - standard_weight) + standard_weight)
```

For different `change_weight` values, we got the following results after training the model for 100 epochs (excluding early stopping). The model is using the `RMSprop` optimizer and the `BinaryCrossentropy` loss with a learning rate of `1-e4`:

| `change_weight` | Loss | Metric | Convergence |
|--------|--------|--------|---|
| 1 | `0.025` | `0.56` | 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 |
| 2 | `0.03` | `0.55` | 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 |
| 5 | `0.04` | `0.66` | 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[^1] |
| 10 | `0.055` | `0.54` | 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 |

[^1]: We have no idea what caused the validation loss to be so significantly smaller than the training loss.  This should normally never be the case.

palisn, 2024-02-11:
> We have no idea what caused the validation loss to be so significantly smaller than the training loss. This should normally never be the case.

This is really weird. I investigated a bit more, and I currently don't see any reason for this.

My first hypothesis was that the ratios of changes in the train and dev dataset are different in the statically split datasets, but the ratios are nearly identically.

But looking at graphs, I would still guess that the difference in loss is due to changing samples. One can see that the difference gets worse the more weight we put on changing samples.

palisn, 2024-02-12:
The next thing we tried is undersampling. The result is, after training for 228 epochs, we have a loss of `0.05` and a custom metric evaluation of `0.76` that is for the training data.
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
For the test data unfortunately the result look a lot worse: We still have a similar loss but the metric capped at around `0.5`.
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

Hence, we will try oversampling next.

palisn, 2024-02-28:
Before we try oversampling, I forgot to try some different ratios for undersampling:

Including twice as many data samples for the negative class as for the positive one, we get a loss of `0.047` and a metric evaluation of `0.617`.
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

For thrice as much, we get a loss of `0.044` and a metric evaluation of `0.522`.
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

With five times the data from the negative class than the positive class, we get a loss of `0.04` and a metric evaluation of `0.483`.
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

For ten times as much, we get a loss of `0.032` and a metric evaluation of `0.486`.
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

palisn, 2024-02-29:
Oversampling the dataset, such that there are as many positive samples as negative ones, gives us a loss of `0.038` (val: `0.039`) and a metric evaluation of `0.8766` (val: `0.669`) after 145 epochs.

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

Closed 2025-03-24.

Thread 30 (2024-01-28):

[PLAN] Key logger for data collection

xjjak, 2024-01-28:
We need a keylogger for our keyboards.
This would enable easier collection of larger datasets, which would also be less unbalanced and more realistic.

*Possible approaches:*

We tried using the keycodes sent by the keyboard, making it completely device-side. This was not very successful.
It should be attempted to utilize the QMK firmware, possibly with custom code snippets to make collection easier or even on the keyboards themselves. This could be done by sending key numbers through a separate channel, similar to something described in [this article](https://precondition.github.io/qmk-heatmap) under *Firmware*.

xjjak, 2024-02-14:
To add key logging output to my keyboard:
- Follow basic qmk instructions for building and flashing keyboard
- locate the folder with keymap.json/keymap.c
- *If there is only keymap.json*: run `qmk json2c keymap.json > keymap.c`
- Append the following to keymap.c:
  ```c
  bool process_record_user(uint16_t keycode, keyrecord_t *record) {
      #ifdef CONSOLE_ENABLE
          const bool is_combo = IS_COMBOEVENT(record->event); // DIFFERS FROM TUTORIAL
          uprintf("0x%04X,%u,%u,%u,%b,0x%02X,0x%02X,%u\n",
               keycode,
               is_combo ? 254 : record->event.key.row,
               is_combo ? 254 : record->event.key.col,
               get_highest_layer(layer_state),
               record->event.pressed,
               get_mods(),
               get_oneshot_mods(),
               record->tap.count
               );
      #endif
      // switch (keycode) {
      // //...
      // }
      return true;
  }
  ```
  The line `is_combo` check had to be changed as `COMBO_EVENT` wasn't found. There is a wrapper function available called `IS_COMBOEVENT` which returns a bool.
- Now try compilation with `qmk compile` (assuming standard kb and km are set)
I encountered the following error:
  ```
  Compiling: platforms/avr/drivers/i2c_master.c                                                      In function 'i2c_start_impl',
      inlined from 'i2c_start' at platforms/avr/drivers/i2c_master.c:104:18:
  platforms/avr/drivers/i2c_master.c:61:10: error: array subscript 0 is outside array bounds of 'volatile uint8_t[0]' {aka 'volatile unsigned char[]'} [-Werror=array-bounds=]
     61 |     TWCR = 0;
        |          ^
  ```
  [Reddit](https://www.reddit.com/r/olkb/comments/15yh5en/i2c_masterc_problem_at_compiling_qmk/) lead me [here](https://github.com/qmk/qmk_firmware/pull/21798) with a workaround to be found [here](https://github.com/qmk/qmk_firmware/issues/17064)

  The workaround disables this type of error, by appending `-e AVR_CFLAGS="-Wno-array-bounds"` to `qmk compile` or `qmk flash`

xjjak, 2024-02-14:
The plan now is to write a simple script the output of `hid_listen` can be piped into, which prepends the current Unix timestamp. A format changing "filter" can be applied to the whole file afterward if necessary for compatibility with the current training method.

xjjak, 2024-02-15:
For the HID console, the QMK udev rules from `qmk_fimware/utils/udev/50-qmk.rules` must be copied to `lib/udev/rules.d` or that directory in its corresponding location.

xjjak, 2024-03-18:
To mitigate the effect that a press event was only sent after a hold-event was detected when a key was kept pressed, the modified function was changed to `pre_process_user_record()`. Thanks, @palisn, for figuring that out.

Closed 2024-03-23.

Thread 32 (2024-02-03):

[FEATURE] BLE data collection

xjjak, 2024-02-03:
Transfer the data via BLE to a host PC or another ESP. This should incorporate #14 but can't be seen as dependent yet as the BLE data structure is to be determined.

[This](https://randomnerdtutorials.com/esp32-bluetooth-low-energy-ble-arduino-ide/) will serve as initial reference.

Parallelization will need to be disabled at first, as BLE will probably be using utilizing the second core as well. This will have to be harmonized later.

xjjak, 2024-03-15:
For now, BLESerial seems practical enough to keep using it. Is it possible to make some quick improvements by sending binary data over a Serial connection instead of strings, that need to be formatted first?

xjjak, 2024-03-18:
With the BLE_SERIAL flag added, pio envs should be implemented for simpler usage as discussed in #46.

Also:
- [ ] Add documentation in a README describing the build flags and how to set/use them.

xjjak, 2024-10-12:
Actually created binary format transmission.
The ESP32 acts as an BLE Server and transmits the timestamp and values as binary value. The exact types are listed in the README.
I also provided a receiver script, which translates the values into the established format. This can be used as a drop-in replacement for ble-serial as it uses the same flag `-d` for specifying the address.

xjjak, 2024-10-12:
- [ ] Add scan functionality which automatically selects address by name

xjjak, 2024-10-15:
Some information about the BLE approach:

Ble Server
- Ble Service
  - Ble Characteristic (reading and notifications enabled)

The ESP sends a notification as soon as all readings are done and the client then reads the set value. I think so at least.
The bleak python module is very unclear about how the Notification Callback actually works. Normally a notification can carry a maximum payload of `ATT_MTU`, with a standard value of 23 in the Arduino ESP32 BLE library, which is not large enough for all data from a single cycle, but there is no need in the Callback to read the value again, so either the notification "carries" all the data, the ESP32 sends multiple packets right after being instructed to notify or the bleak notfication callback reads (requests a transfer) the value automatically.

Closed 2025-01-14.

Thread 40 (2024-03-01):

[FEATURE] Build Flag for optional parallelization/multicore

xjjak, 2024-03-01:
**Is your feature request related to a problem? Please describe.**
Parallelization seems to have a bug, for which an issue has yet to be created. After some time, the `Something went wrong waiting for events.` error occurs. Increasing the "Ticks to wait" did not help. It's not physical disconnection though, as this would lead to an `I2C_read` error.

**Describe the solution you'd like**
Implement a build flag that enables or disables parallelization. This would just control the call of `xCreateTaskPinnedToCore()`. And `reset_all_bufs()` would need to be called after reading all the sensors, if parallelization is disabled. This would also help with #32 and #33, as BLESerial, and perhaps later BLE with a custom protocol, can just be added on top, perhaps also with a build flag. Both option wouldn't be allowed at the same time.

**Describe alternatives you've considered**
The alternative would be to remove the code segments. This seems unnecessary, though, as the flash memory is big enough and the complexity isn't too much.

Closed 2024-03-01.

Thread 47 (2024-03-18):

Should parallelization of buffer resets be disabled by default?

xjjak, 2024-03-18:
Through the build flag `MULT_CORE` parallelization can be easily enabled or disabled. Currently, in `config.h` it defaults to `1`, so parallelization of DMP buffer resets is enabled.

Should it stay this way?

There is a small timing improvement, but as it stands and in the future it won't easily be possible to use simultaneously with BLE data transmission #32.

xjjak, 2025-01-13:
Yes, it seems broken anyways. Adding into to the #59 pull-request

Closed 2025-01-13.

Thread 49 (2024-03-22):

[IDEA] Restructure software directory

palisn, 2024-03-22:
**Describe the vision. What is to be achieved? What does the end-result look like? Is it a specific feature?**
The current structure is too thrown-together.  You can neither easily navigate it nor extend it properly.  The goal should be a clean structure that is easily extensible and allows for quick testing and development, as well as deployment.

**Share possible solutions or ideas and approaches.**
<s>
The top-level of the `Software` directory should provide four stages of software:
- Everything concerned with _data collection_ that is not hardware/firmware related. (`collection`)
- All _preprocessing_ of the collected data, as well as data format conversions. (`processing`)
- All _models_ (of every kind) and all related _custom modules_ that provide functionality for those models. (`machine-learning`)
- Everything related to _further processing_ of model output or other data, e.g. visualizations. (`analysis`)
Furthermore, we should embrace environment variables for the data storage location.
</s>

Additionally, we should replace the central `requirements.txt` with a more decentralized approach, that requires only exactly as much as needed for a specific tool (my idea is to leave the `requirements.txt` in place, but also provide `shell.nix` files for every tool).  Along with that, every tool and most directories should get their own READMEs that explain their usage and other important information regarding them.

**Additional context**
The current structure strongly differentiates between click and state-detection.  They also both rely on different data collection method, with no clean way to interoperate them.

### Edit

After some consulting and considering that not much happened since the creation of this issue, we decided that we will change this plan in favor of another broader restructuring. The most important underlying change is that software development, especially regarding machine learning, will no longer happen within Jupyter Notebooks, instead we opt for a literate programming approach in [org mode](https://orgmode.org/). Org mode support code cell execution similar to Jupyter Notebooks but can additionally *tangle* them to code files at arbitrary locations.

Using these features, most of the software development from now on will take place within these files and the resulting code will be tangled to files within the `src` folder, unless it is testing code, which will primarily be tangled into the `test` folder. One org file should contain all the development and documentation regarding one semantically coherent part of the workings of the software architecture. Additional context or parts of the project, that relate to but don't fit in the document, should be linked in the right place. Currently, I plan to create three org files namely:
- `data-collection.org` should contain all software components relevant to data collection. This includes stuff like the keylogger, scripts that are used for data collection, and structural preprocessing.
- `machine-learning.org` should contain all machine learning related parts of the project. This includes the model specification as well as documented parameter tests. It also includes framework specific data structures and the like.
- `tooling.org` contains all tools that make use of features provided by the above files. Examples include _live-plotting tool_ (#51), visualization tools, and also the tool that, when finished, would use the models predictions to actually type on the computer.

Further, smaller auxiliary tools might also be developed inside an org file with broader context, if they are independent of other code in `src` they might be tangled into a new root folder `Utilities`, examples could include the _keylogger_ (#37) as well as the _keyboard visualization_ (#39) or even the _live-plotting tool_ (#51).

xjjak, 2024-03-22:
Should a folder dedicated to machine learning *on-the-edge* (`edge-ml`?) be added to the 2nd level or put inside the `machine-learning` folder?

palisn, 2024-03-23:
> Should a folder dedicated to machine learning _on-the-edge_ (`edge-ml`?) be added to the 2nd level or put inside the `machine-learning` folder?

Wouldn't that be firmware?

xjjak, 2025-01-14:
Regarding the proposed migration away from `requirements.txt`: Would [uv](https://github.com/astral-sh/uv) be an alternative/additional option for you, for managing python scripts etc.? @palisn
As far as I understand it is also still compatible with pip, but makes managing `venvs` and dependencies much easier.

Closed 2025-05-23.

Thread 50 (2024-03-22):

[IDEA] Create automatic stability and functionality test

xjjak, 2024-03-22:
Create an automatic test, that checks for sensor functionality, sensor reliance by resetting multiple times, Bluetooth stability by recording disconnects and a checker for battery life and the over-discharge thresholds.

Closed 2025-01-13.

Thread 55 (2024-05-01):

[COLLECTION] Improve data quality

xjjak, 2024-05-01:
Using the live plotting tool, looking at the data, tapping motions are quite distinguishable, though the acceleration values rest at non-zero values.

There are improvements to be made to the "quality" of the data, for example through better calibration or filtering. This issue is where to collect the improvement opportunities or issues stemming from poor quality data as well as their possible fixes.

**Issues:**
- measured acceleration is not zero although at rest

xjjak, 2024-05-11:
Some resources on IMU calibration:
- [A systematic review of user - conducted calibration methods for MEMS-based IMUs](https://www.sciencedirect.com/science/article/abs/pii/S0263224123015658)
- [imucal python library](https://imucal.readthedocs.io/en/latest/README.html)
- [Ferraris Calibration – A Practical Guide | imucal 2.4.0 documentation](https://imucal.readthedocs.io/en/latest/guides/ferraris_guide.html)

xjjak, 2025-03-24:
Hardware is probably the most determining factor, so the manufacturing process (reflow), and of course the chip choice.
Apart from this, [the implementation of a moving average](https://github.com/xjjak/LapCal/blob/restructure-software-directory/Software/data-collection.org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) helped with the wrong offset from 0.

Closed 2025-03-24.

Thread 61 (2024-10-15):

[FEATURE] Integrate ble-receiver into live plotting

xjjak, 2024-10-15:
The new firmware with pure BLE binary data transmission can be used with the ble-receiver script on the other end, which translates the binary values into a string.
While this happens "live", unlike the ble-serial receiver it does not open a separate file/port, but prints directly to stdout. As such, it is not compatible with the current version of the live-plotting software, which is reliant on ble-serial or at least a program opening a port on /tmp/ttyBLE.

*(Side note: I completely forgot about ble-serial opening up a separate port and thought a receiver like this could serve as a sort of drop-in replacement)*

There are two ways to reconcile this:
1. Modify the live-plotting code to be able to plot values coming from the stdout of the process which initiates the connection
2. Modify the ble-receiver program to also open up an "endpoint" which it writes to instead or in addition to stdout. This could also be `/tmp/ttyBLE` maintaining more compatibility with the current version of live-plotting

xjjak, 2024-10-15:
I tried out some glue, by modifying the live-plotting code to start the script to
`python ble-receiver.py -d \"~a\" > /tmp/ttyBLE`.
This works, but the plot is very laggy. The bottleneck may be the pipe though.

Way **2.**is probably easier to do, especially by me, but it's still an open question whether a buffer like `/tmp/ttyBLE` should be used or the data received directly via stdout?

xjjak, 2024-10-16:
I redirected the print in ble-receiver.py to `/tmp/ttyBLE`, which works well, but the plot is still jittery/laggy and shows a "parsing error".
This may have to do with the transferring of the angle values as whole values instead of floats.
Or is the frequency is actually too high?

xjjak, 2024-10-16:
After adding `flush=True` to the print statement of the incoming data as a string, the plot seems to be more stable and the lags are gone. The screen is still flashing a lot, but that is probably just the plot being redrawn.

- [ ] The parsing error remains to be fixed

xjjak, 2024-11-02:
Regarding the parsing error:
I have found the point of "error" to be:
```racket
(define (parse str)
  (cond
    [(eof-object? str)
     #f]
```

The incoming string is an end of file object. I don't know why that happens or why it happens at irregular iintervals.

palisn, 2024-11-02:
> After adding `flush=True` to the print statement of the incoming data as a string, the plot seems to be more stable and the lags are gone. Without it, the prints are most likely buffered before actually being written to the disk until it's "worthwhile" to perform an actual write operation. The screen is still flashing a lot, but that is probably just the plot being redrawn.
>
>     * [ ]  The parsing error remains to be fixed

I don't know how exactly the operating system handles this kind of files, but it would probably be best to try to avoid writing to the disk all the time. I can't imagine that the disk would like that very much.

A further alternative might be to use another intermediary point that we have more control over, or we just implement the binary parsing in racket which should also not be to hard I'd assume but I've not worked with binary data in racket yet.

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

No idea why this would happen. Sound like some improper file handling is happening but I don't know where or why.

palisn, 2024-11-02:
> After adding `flush=True` to the print statement of the incoming data as a string, the plot seems to be more stable and the lags are gone. Without it, the prints are most likely buffered before actually being written to the disk until it's "worthwhile" to perform an actual write operation. The screen is still flashing a lot, but that is probably just the plot being redrawn.
>
>     * [ ]  The parsing error remains to be fixed

I don't know how exactly the operating system handles this kind of files, but it would probably be best to try to avoid writing to the disk all the time. I can't imagine that the disk would like that very much.

A further alternative might be to use another intermediary point that we have more control over, or we just implement the binary parsing in racket which should also not be to hard I'd assume but I've not worked with binary data in racket yet.

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

No idea why this would happen. Sound like some improper file handling is happening but I don't know where or why.

xjjak, 2024-11-02:
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
You're right, this is not optimal. I could also imagine that this is actually what's somehow causing the eof error. I need to see if there is a difference to a file on disk and a "port" that appears as a file, some sort of a "stream" I guess, which then perhaps wouldn't need/contain any end-of-file.

xjjak, 2024-11-02:
> A further alternative might be to use another intermediary point that we have more control over, or we just implement the binary parsing in racket which should also not be to hard I'd assume but I've not worked with binary data in racket yet.

This could be done of course, decreasing the amount of data needed to be transferred between programs, but I think some external program will still be required, as I don't think there is a BLE client yet for racket.

palisn, 2024-11-02:
> This could be done of course, decreasing the amount of data needed to be transferred between programs, but I think some external program will still be required, as I don't think there is a BLE client yet for racket.

I think there is something that could problem work for working with Bluetooth, but I wouldn't want to rely on that either. So we should problem keep the Bluetooth part in Python.

Also, I just thought of a nice way to handle the communication between Racket and Python: We could just start the Python script inside of Racket and let Racket handle the stdout directly. Or is there any technical reason this might not work @xjjak?

palisn, 2024-11-02:
> That should work fine. I just tried to avoid that, so the racket code wouldn't need to be modified as much. Or in ways that I could do... But I guess it's easier to just do that, reduces complexity in both programs. I'm more used to lisp style code now, so I might actually be able to do it myself if you'd like.

It should be rather straight forward to implement. If you want to you try implementing it, but if not I'll try to do it as soon as possible, might even be able to do it today.

> Just wondering if the live-plotting-dev branch is up-to-date currently?

I'm currently not sure of that either :sweat_smile:, I started reorganizing the code a bunch a while ago. But I'd probably just stash that for now and work on the current live-plotting branch. As far as I remember, there shouldn't be any major changes that I didn't push.

xjjak, 2024-11-02:
Well, I looked the code of ble-serial again, and I think you doing it would be much quicker... 😬

palisn, 2024-11-02:
a

> Well, I looked at the code of ble-serial again, and I think you doing it would be much quicker... 😬

Sure, the output of the script is already stdout, right? Also, do we need to pass any command line arguments through the racket program or should there be any GUI forms? There isn't any scanning yet, right?

xjjak, 2024-11-02:
Yeah, stdout is default. Only the MAC device address needs to be passed. It's the same as with ble-serial (`-d`). There is no inbuilt scan functionality yet, yes. Coming soon though...

palisn, 2024-11-02:
If it's the same MAC address, can we just use the scanning functionality from ble-scan for now?

Closed 2025-03-24.

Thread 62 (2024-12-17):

A Roadmap to Proof of Concept

xjjak, 2024-12-17:
*This issue is mostly documentation, but can also serve as a collection of tasks and issues to place them along the roadmap, so feel free to edit*

We never actually formulated a proper goal or requirements, it just emerged, and we are still wondering if it can be achieved and at the same time wondering what we can achieve with what we have. The unfortunate reality is, that we pretty much don't have anything, well except for experience and learnings. I don't think much of the actual "output" so far are actually useful, but I think we have learned enough about principles, that we can still apply. For that, we need a new roadmap. Smaller steps, so we can actually start proving what we still believe should work. So here it is:

# A new approach and a road map to a proof of concept.

**The Goal:** Emulate a 34-key keyboard (and stenography-compatibility)

**Why a 34-key keyboard?**

A 34-key keyboard makes sense, because it still works with a standard layout for most letters, so adapting to it isn't as hard when reducing even more, while still having very little keys per finger (2, 3, 6).
I also recognize the potential for stenography, but is much more complicated to learn, which I haven't done yet, and if a 34-key keyboard works, a stenographic layout implementation would surely also work.

Both require "cording", pressing down multiple keys at once to achieve a different output. For this, timing needs to be quite precise, especially for the 34-key keyboard.
This timing precision is what I'm doubtful our current approach using a single controller can achieve.
Something else that hasn't really been successful is the hardware. No regrets, but it just wasn't a good decision to start by basically recreating a ESP32 dev board and slightly smaller MPU6050 breakout boards with unreliable cable connections.

**To start anew, I think we should therefore:**

-   Solve incremental problems / Get things working to eventually prove the concept
-   Use pre-existing parts, both in hardware and software, where possible

The roadmap I envision, to hopefully prove the "concept" (which is using IMUs for this purpose, I guess) looks like this:
*The stages are explained in more detail below*...

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

## Stages:
### 1. Column

**Scope**: Maps single finger movement to the three keys in a column, detect press & release events
    *we can assume a planted wrist and rest position at start*

**What we need:**

-   Movement Data collection: Single IMU (MPU6050) and microcontroller
-   Data transfer: Two options, both output binary data (?)
    -   Wired
    -   BLE
        This would require a setup to accurately ascribe timestamp or something similar to the data records for proper matching to the reference data
-   Reference data collection:
    A program that gets 3 letters through a configuration and prompts for them, either randomly or in a pattern, collecting the input from a keyboard. This way, a standard keyboard can be used, and any column, with any layout, one would just have to adjust the letter-configuration accordingly.
    -   [ ] Choose data format
-   Merging
-   Training
    -   For this, an additional program, perhaps visual, would be nice, to display the key column and highlight the keys accordingly, as a live-preview. Perhaps this interface could also be used for the aforementioned reference point data collection
-   (On the edge: Transfer model onto a MCU, and for example light up some LEDs as further proof of concept)

### 2. Index cluster: 6 keys

-   Scope: Map a single (index) finger, to it's six-key cluster, so two columns (press & release)
    *again assume planted wrist and resting position at start*
     Upgrade all the previous pieces of software to also provide a variant for a six-key cluster.

-   Training: Create a new model, leaving the old in place, for later use

### 3. "Typing mode detection"

Goal: Verify that typing and non-typing situations can be differentiated.

Add another sensor on the palm of than or wrist, probably to the same MCU. When not in motion (for x seconds), enable typing mode.

-   "Simple" motion detection, probably no training of a model needed. We would need to come up with a reference point collection method if a model is needed.

### 3.5 Single processor evaluation

Add vertical columns and sensors one after another to a single MCU controller, to see if one is enough. Would have to include the onboard models to be conclusive.
*We could probably assume typing mode, to simplify testing*

I'm skeptical if this would even work, even if, I'll make the case against it in the next section. It remains open if this step should even be attempted, as bringing the potential models to a single MCU probably require a lot work, which could be "useless".

### 4. Multiple Processors:

*This is the main change of approach I was referencing in the beginning.*
Instead of using a central controller to read out the IMUs, each one gets its own MCU, for example a RP2040, which will hopefully be able to read out the sensor and running it through the trained model(s) from step 1 & 2, at a high frequency. These individual chip-combos can be tested using off the shelf components, but then perhaps be turned into a custom PCB. (Side note: for this I'd use a different IMU: ISM330DHCX, the successor of the MPU6050 coming in at about 4€ on LCSC). The MCUs would then be connected to the actual central controller. This could again be an off-the-shelf component, even one that is commonly used for wireless (split) keyboards, like a nice!nano for example. Using ZMK firmware, a way to emulate hardware keys with the individual, new generation, SenseUnits (IMU + MCU), could be found. In this way, less (embedded) software has to be developed, the hardware simplified, though more performant.

Advantages:
-   Modular hardware
-   Pre-built components (Central Controller & Keyboard Firmware)
-   Probably powerful enough
-   Fine-tuned models, for each finger, are possible, perhaps even through on-chip learning

Disadvantages:

-   Cost:
    -   SenseUnit: maybe ~10€ (?) (~15€ off the shelf, seeed xiao rp2040 13€, 2€ GY-521 MPU6050)
        -   IMU: 4€
        -   MCU: 1.5€ (RP2040 IC)
        -   Board

Connections will rely on either standard Dupont cable connectors, or something similarly popular and durable, to ensure reliability, in favor of miniscule size improvements.

### 4. Single processor:

If powerful enough, a single central processor serially checks each sensor and feeds either a single model, or the ones resulting from the first two steps.

(As I said, I doubt this even works with a single ESP32 or even a dongle, because of too much latency doing things serially)

### (5. How to make training (the models) easy?)

Ideally, model training...

-   Doesn't require additional hardware
-   Works with versatile keyboard types
-   Data is collected during normal operation, no extra training sessions required

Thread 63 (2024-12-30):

Accurately timestamping data collected by an MCU

xjjak, 2024-12-30:
To merge the training data, consisting of the IMU values and reference keystroke/events data, we need to accurately timestamp the data coming from a microcontroller in relation to a host (PC/laptop) that is collecting the reference data.

**What is *accurate*?**
The bottleneck so far has been the IMU readouts, which therefore dictates frequency. Multiple reference data points/states can be assigned to a single IMU data point. If we collapse multiple reference data points into one timestamp, in the same frequency the IMU data is collected, an offset, most likely meaning latency, so negative offset, of half of the frequency should still be okay to merge the timestamps *accurately*. With the current frequency being ~100Hz, so 10ms per datapoint, a delay of 5ms would be acceptable?
The more accurate the better though...

**Current status**
- [x] Test NTP timestamp accuracy on ESP32 (Compare host timestamp with MCU's over serial transmission)
       The expected output would be the latency introduced by the serial transmission, which this can then be compared to. If this is negligible with `ms` accuracy, this opens up the possibility of timestamping data points when coming in on the host, instead of the MCU itself.
- [ ] Compare above accuracy to that achieved over BLE
       If the latency introduced by BLE is within `2-12ms`, which is in typical range (_confirmation and source needed_), it could further indicate accurate timestamping on the ESP.

xjjak, 2025-01-07:
After customizing the firmware for a wired test setup, while writing the python scripts for data collection, I ran into the problem that my computer's clock wasn't synchronized via NTP. While fixing the problem, I read about the inaccuracy, which is tens of milliseconds, which would not be sufficient for this.
I also looked for specific ways to synchronize microcontrollers and I was further driven to recognize:
1. NTP timestamps won't be accurate enough
2. A wired setup (before merge) is required, because BLE delays are jittery, so not even consistent
3. Because the reference data for training is generated by a microcontroller anyways, it makes more sense to connect the two microcontrollers, one reads the IMU data and the other reads the state of keyboard buttons, and the data is merged on one of them, and then sent to a host (instead of sending the data to the host, on which delays etc. are harder to control in a high level OS and merging it there)

Closed 2025-01-08.

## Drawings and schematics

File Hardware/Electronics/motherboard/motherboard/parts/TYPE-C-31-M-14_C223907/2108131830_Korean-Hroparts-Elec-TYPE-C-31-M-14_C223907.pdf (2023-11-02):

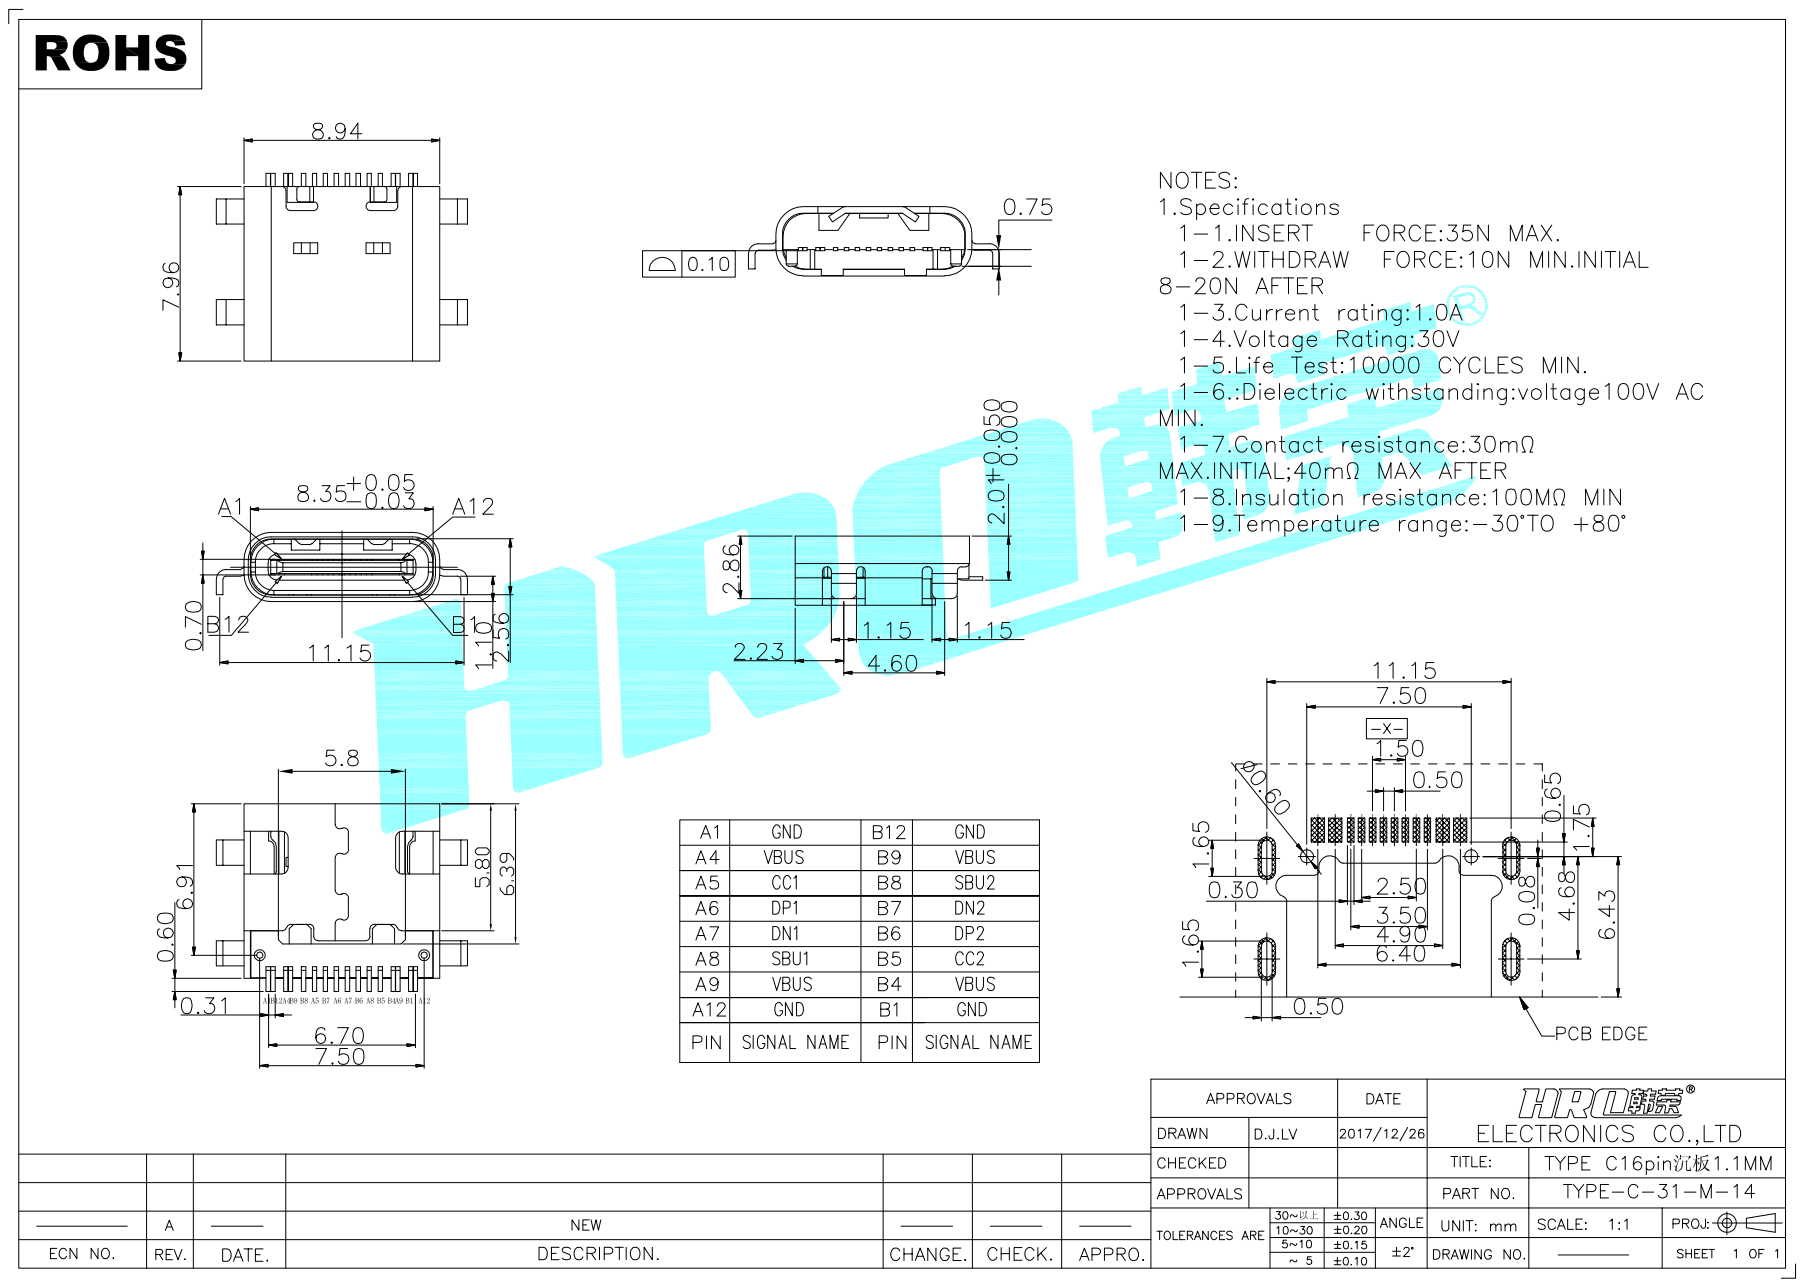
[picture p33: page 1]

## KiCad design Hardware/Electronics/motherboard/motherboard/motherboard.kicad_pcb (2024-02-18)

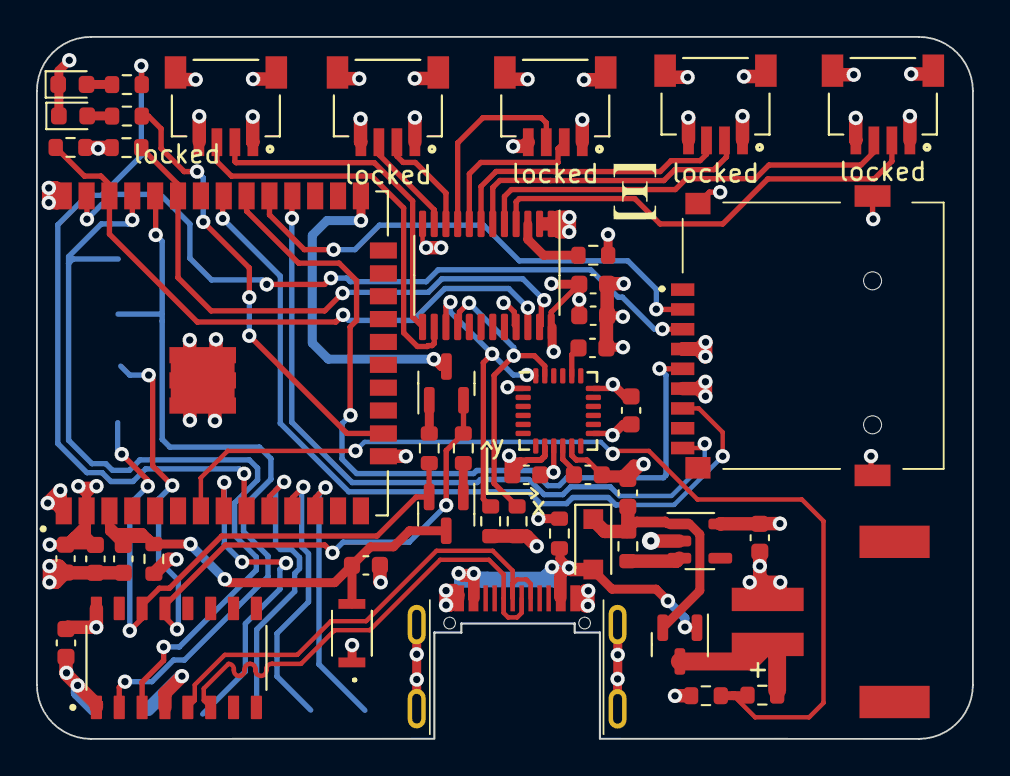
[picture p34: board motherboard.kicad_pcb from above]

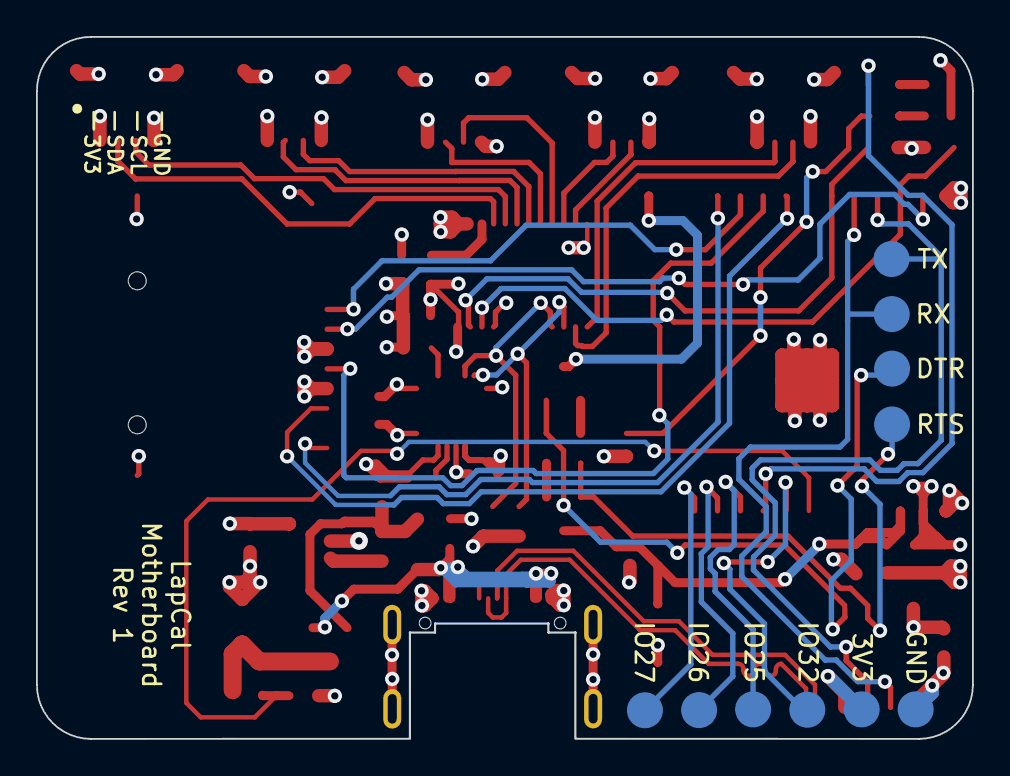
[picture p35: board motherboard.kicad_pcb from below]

Board: 4 copper layers, 52.0 x 39.0 mm, 57 parts (10 on the bottom side), 47 nets.

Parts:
111: TF-01A; TF01A
C1, C2, C5, C8, C10, C11, C13: 0.1uF; C_0603_1608Metric
C3, C4: 1uF; C_0603_1608Metric
C7: 22uF; C_0603_1608Metric
C9: 10uF; C_0603_1608Metric
C12: 10nF; C_0603_1608Metric
C14: 2.2nF; C_0603_1608Metric
D1: mbr120; D_SOD-123F
D2: blue; LED_0603_1608Metric
D3: green; LED_0603_1608Metric
J1: USB_C_Receptacle; TYPE-C-31-M-14
J3, J4, J5, J6, J7: locked; JST_SM04B-SRSS-TB(LF)(SN)
J8: Conn_01x02_Female; HX25003-2AWB
Q1: HXY3401AI; SOT-23
Q2, Q3: MMBT3904; SOT-23
R1, R3, R4, R5: 10k; R_0603_1608Metric
R2, R8, R9: 100k; R_0603_1608Metric
R6, R10: 5k; R_0603_1608Metric
R7: 7k; R_0603_1608Metric
R11, R12: 3.7k; R_0603_1608Metric
R13, R14: 4k7; R_0603_1608Metric
S1: TS2306A-240GF-MSM-9_C388290; TS2306A240GFMSM9_C388290
TP3: IO26; TestPoint_Pad_D2.0mm
TP8: RX; TestPoint_Pad_D2.0mm
TP9: DTR; TestPoint_Pad_D2.0mm
TP10: RTS; TestPoint_Pad_D2.0mm
U1: ESP32-WROOM-32E_(16MB); XCVR_ESP32-WROOM-32E_(16MB)
U2: AP2112K-3.3; SOT-23-5
U3: CH340C; SOIC127P600X180-16N
U4: TCA9548APWR; TSSOP-24_4.4x7.8mm_P0.65mm
U5: MPU-6050; InvenSense_QFN-24_4x4mm_P0.5mm
locked: 3V3; TestPoint_Pad_D2.0mm
locked#2: IO32; TestPoint_Pad_D2.0mm
locked#3: TX; TestPoint_Pad_D2.0mm
locked#4: IO27; TestPoint_Pad_D2.0mm
locked#5: IO25; TestPoint_Pad_D2.0mm
locked#6: GND; TestPoint_Pad_D2.0mm

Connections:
+3V3: 111.4, C4.1, C5.1, C7.1, C8.1, C9.1, C10.1, C11.1, C12.1, J3.1, J4.1, J5.1, J6.1, J7.1, R1.1, R7.1, R11.1, R12.1, R13.1, R14.1, U1.2 (3V3), U2.5 (VOUT), U3.4 (V3), U3.16 (VCC), U4.24 (VCC), U5.8 (VDDIO), U5.13 (VDD), locked.1
+3V8: J8.1, Q1.3 (D), R8.1
CS: 111.2, U1.29 (IO5)
D+: J1.A6 (D+), J1.B6 (D+), U3.5 (UD+)
D-: J1.A7 (D-), J1.B7 (D-), U3.6 (UD-)
DTR: Q2.2 (E), R4.1, TP9.1, U3.13 (~DTR)
EN: C1.2, C2.1, Q3.3 (C), R1.2, S1.2, U1.3 (EN)
GND: 111.6, 111.MP2, 111.MP3, 111.MP4, C1.1, C2.2, C3.2, C4.2, C5.2, C7.2, C8.2, C9.2, C10.2, C11.2, C12.2, C13.2, C14.2, D2.1 (K), D3.1 (K), J1.A1 (GND), J1.A12 (GND), J1.B1 (GND), J1.B12 (GND), J1.S1 (SHIELD), J3.4, J3.S1 (SHIELD), J3.S2 (SHIELD), J4.4, J4.S1 (SHIELD), J4.S2 (SHIELD), J5.4, J5.S1 (SHIELD), J5.S2 (SHIELD), J6.4, J6.S1 (SHIELD), J6.S2 (SHIELD), J7.4, J7.S1 (SHIELD), J7.S2 (SHIELD), J8.2, R2.2, R9.2, S1.1, U1.1 (GND), U1.15 (GND), U1.38 (GND), U1.39_1 (GND), U1.39_2 (GND), U1.39_3 (GND), U1.39_4 (GND), U1.39_5 (GND), U1.39_6 (GND), U1.39_7 (GND), U1.39_8 (GND), U1.39_9 (GND), U2.2 (GND), U3.1 (GND), U4.1 (A0), U4.2 (A1), U4.12 (GND), U4.21 (A2), U5.1 (CLKIN), U5.9 (AD0), U5.11 (FSYNC), U5.18 (GND), locked#6.1
GPIO0: Q2.3 (C), U1.25 (IO0)
I2C1_SCL: R11.2, U1.36 (IO22), U4.22 (SCL)
I2C1_SDA: R12.2, U1.33 (IO21), U4.23 (SDA)
IO13: R6.1, U1.16 (IO13)
IO25: U1.10 (IO25), locked#5.1
IO26: TP3.1, U1.11 (IO26)
IO27: U1.12 (IO27), locked#4.1
IO32: U1.8 (IO32), locked#2.1
IO33: R10.1, U1.9 (IO33)
IO35: R8.2, R9.1, U1.7 (IO35)
MISO: 111.7, U1.31 (IO19)
MOSI: 111.3, U1.37 (IO23)
unnamed: C3.1, D1.1 (K), Q1.2 (S), R5.2, U2.1 (VIN)
unnamed: C13.1, U5.10 (REGOUT)
unnamed: C14.1, U5.20 (CPOUT)
unnamed: D2.2 (A), R6.2
unnamed: D3.2 (A), R10.2
unnamed: Q2.1 (B), R3.2
unnamed: Q3.1 (B), R4.2
unnamed: R5.1, U2.3 (EN)
unnamed: R7.2, U4.3 (~RESET)
Onboard_SCL: R14.2, U4.16 (SC5), U5.23 (SCL)
Onboard_SDA: R13.2, U4.15 (SD5), U5.24 (SDA)
PROG_RX: U1.35 (TXD0), U3.3 (RXD), locked#3.1
PROG_TX: TP8.1, U1.34 (RXD0), U3.2 (TXD)
RTS: Q3.2 (E), R3.1, TP10.1, U3.14 (~RTS)
SCLK: 111.5, U1.30 (IO18)
SD_DETECT: 111.CD1, U1.28 (IO17)
Sense1_SCL: J3.3, U4.5 (SC0)
Sense1_SDA: J3.2, U4.4 (SD0)
Sense2_SCL: J4.3, U4.7 (SC1)
Sense2_SDA: J4.2, U4.6 (SD1)
Sense3_SCL: J5.3, U4.9 (SC2)
Sense3_SDA: J5.2, U4.8 (SD2)
Sense4_SCL: J6.3, U4.11 (SC3)
Sense4_SDA: J6.2, U4.10 (SD3)
Sense5_SCL: J7.3, U4.14 (SC4)
Sense5_SDA: J7.2, U4.13 (SD4)
VBUS: D1.2 (A), J1.A4 (VBUS), J1.A9 (VBUS), J1.B4 (VBUS), J1.B9 (VBUS), Q1.1 (G), R2.1

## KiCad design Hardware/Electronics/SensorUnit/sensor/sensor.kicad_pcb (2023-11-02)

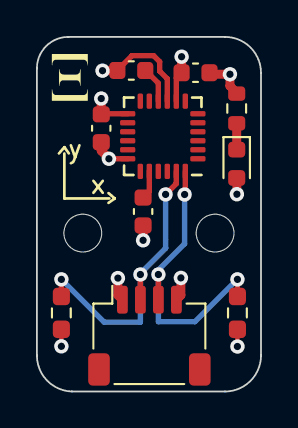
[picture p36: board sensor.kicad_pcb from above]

Board: 4 copper layers, 12.4 x 19.7 mm, 12 parts (0 on the bottom side), 7 nets.

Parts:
C1, C2: 0.1uF; C_0603_1608Metric
C3: 2.2nF; C_0603_1608Metric
C4: 10nF; C_0603_1608Metric
D1: Blue; LED_0603_1608Metric
H1, H2: MountingHole; MountingHole_2.1mm
J1: SM04B-SRSS-TB(LF)(SN); JST_SH_SM04B-SRSS-TB_1x04-1MP_P1.00mm_Horizontal
R1: 2k; R_0603_1608Metric
R2, R3: 4k7; R_0603_1608Metric_Pad0.98x0.95mm_HandSolder
U1: MPU-6050; InvenSense_QFN-24_4x4mm_P0.5mm

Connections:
+3V3: C2.1, C4.1, D1.2 (A), J1.4, R2.1, R3.1, U1.8 (VDDIO), U1.13 (VDD)
GND: C1.2, C2.2, C3.2, C4.2, J1.1, R1.1, U1.9 (AD0), U1.18 (GND)
unnamed: C1.1, U1.10 (REGOUT)
unnamed: C3.1, U1.20 (CPOUT)
unnamed: D1.1 (K), R1.2
SCL: J1.2, R3.2, U1.23 (SCL)
SDA: J1.3, R2.2, U1.24 (SDA)

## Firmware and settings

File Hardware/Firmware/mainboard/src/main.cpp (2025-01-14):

#include <Arduino.h>

#include "config.h"

#include "battery.h"
#include "sdcard.h"
#include "sensors.h"
#include "timestamp.h"
#include "touch.h"

#if BLE
#include "ble-utils.h"

BLECharacteristic *pCharacteristic;
#endif

// ------ TICKERS ------
#include <TickTwo.h>
bool check_bat_flag = false;
void set_bat_flag() { check_bat_flag = true; }

TickTwo timer_battery_check(set_bat_flag, 300000, 0, MILLIS);
// ---------------------

reading all_readings[SENSOR_COUNT];

char all_readings_charbuf[SENSOR_COUNT * 201];

char unix_timestamp[60];
// uint64_t timestamp_num;
uint64_t milli_timestamp;

TaskHandle_t TaskFifoReset;

void print_headerline() {}

void setup() {
  pinMode(LED_BLUE, OUTPUT);
  pinMode(LED_GREEN, OUTPUT);
  pinMode(SD_DETECT, INPUT);

  digitalWrite(LED_BLUE, HIGH);
  Serial.begin(115200);

  // char headerline[500];
  // headerline[0] = (char)0;

  Serial.println("Initialising i2c");
  setup_i2c(SDA, SCL);

  // ------SETUP SENSORS-------
  Serial.println("Setting up Sensors");
  setup_sensors();

  // ------SETUP SD------------
  // gen_timestamp(unix_timestamp, &timestamp_num);
  // Serial.println(unix_timestamp);
  // sprintf(headerline, "%d", unix_timestamp);
  // strcat(headerline, unix_timestamp);
  // setup_sdcard(unix_timestamp);
  // write_values(headerline);

  digitalWrite(LED_BLUE, LOW);
  digitalWrite(LED_GREEN, HIGH);

  // ------GET TIMESTAMP-------
  milli_timestamp = get_milli_timestamp();
  // milli_timestamp = 1010101010;
  Serial.println(milli_timestamp);

  // ------Parallelization setup------
  if (MULT_CORE) {
    xTaskCreatePinnedToCore(task_fifo_reset, "fifo_resets", 10000, NULL, 1,
                            &TaskFifoReset, 0);
    Serial.println("Parallelization enabled.");
  }

#if BLE
  pCharacteristic = setup_ble();
#endif
  timer_battery_check.start();

  // ---- TIME SINGLE CYCLE ----
  //
  // uint32_t prev_millis = millis();
  // get_all_readings(all_readings);
  // format_readings(all_readings, all_readings_charbuf);
  // Serial.print(".");
  // ble_transmit_values(pCharacteristic, all_readings, milli_timestamp);
  // write_values(all_readings_charbuf);
  // Serial.print("Millis taken: "); Serial.println(millis() - prev_millis);
}

void loop() {
#if BLE
  if (is_ble_connected()) {
    get_all_readings(all_readings);
    ble_transmit_values(pCharacteristic, all_readings, milli_timestamp);
  }
#else
  get_all_readings(all_readings);
  format_readings(all_readings, all_readings_charbuf, milli_timestamp);
  Serial.println(all_readings_charbuf);
#endif

  // Serial.println("Checking bat_stat");
  if (check_bat_flag) {
    // Serial.println("Checking bat...");
    check_battery();
    check_bat_flag = false;
  }

  // Serial.println("detecting touch");
  // detect_touch(TOUCH_PIN);

  // Serial.println("Loop done.");
  timer_battery_check.update();
}

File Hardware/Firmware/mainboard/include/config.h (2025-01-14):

// -----DEFINITIONS---
#define SCK 18
#define MISO 19
#define MOSI 23
#define CS 5

#define LED_GREEN 33
#define LED_BLUE 13

#define SDA 21
#define SCL 22

#define SD_DETECT 17

#define TOUCH_PIN 32

#define VBAT_SENSE 35

#define SENSOR_COUNT 6
//---------------------

// THRESHHOLDS
#define THRESH_LOW_BAT 1800
#define THRESH_TOUCH 15
#define THRESH_NO_TOUCH 30

struct reading {
    int16_t ax;
    int16_t ay;
    int16_t az;
    int16_t gx;
    int16_t gy;
    int16_t gz;
};

struct offsets {
    int xa, ya, za, xg, yg, zg;
};

#ifndef RIGHT_HAND
#error Specify hand.
#endif

#ifndef MULT_CORE
#define MULT_CORE 1
#endif 

#ifndef BLE_SERIAL
#define BLE_SERIAL 0
#endif 

#if RIGHT_HAND
    const offsets mpu_offsets[] = {
        {-262, -2994, 1711, -174, 214, 46}, // Thumb
        {-6018, 1394, 1385, 66, -86, 35}, // Index
        {-3296, 434, 1879, 377, -178, -6}, // Middle
        {-889, -4586, 1050, 117, -242, 54}, // Ring 
        {2071, -3990, 1582, -42, 119, 58}, // Pinky
        {-2539, -2304, 372, 90, 3, 18}, // Onboard
    };
#else
    // Remember: this config is also in reverse order if sensors_array is switched
    const offsets mpu_offsets[] = {
        {-3571, -2403, 3423, 208, -90, -214}, // Thumb
        {-1260, 3656, 6252, -3360, -493, 31}, // Index
        {-15598, -3882, 5878, -55, -292, 297}, // Middle
        {-15598, -3882, 5878, -55, -292, 297}, // Ring
        {-368, -18006, 7812, 132, -141, -140}, // Pinky
        {-1074, 2309, 1022, 116, -26, 26}, // Onboard
    };
#endif

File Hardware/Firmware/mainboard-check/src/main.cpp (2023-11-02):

#include <Arduino.h>

#define LED_BUILTIN 33


void setup() {
    Serial.begin(115200);
    pinMode(LED_BUILTIN, OUTPUT);
    digitalWrite(LED_BUILTIN, HIGH);
    // Serial.begin(115200);
}

void loop() {
    Serial.println("Hello World!");
    delay(100);
    // digitalWrite(LED_BUILTIN, LOW);
    delay(100);
}

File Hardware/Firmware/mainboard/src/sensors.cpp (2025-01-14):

#include <Arduino.h>

#include <MPU6050_6Axis_MotionApps20.h>
#include <Wire.h>

#include "config.h"

#define BIT_0 (1 << 0)

unsigned long prev_micros;
unsigned long reading_start_micros;

#define __TIMING(format)                                                       \
  if (TIMING_ENABLED) {                                                        \
    Serial.printf(format, micros() - prev_micros);                             \
    prev_micros = micros();                                                    \
  }
const int TIMING_ENABLED = 0;

MPU6050 Sensors[SENSOR_COUNT];
int sensor_presence[SENSOR_COUNT] = {};

// MPU control/status vars
uint8_t devStatus; // return status after each device operation (0 = success, !0
                   // = error)
uint16_t packetSize;    // expected DMP packet size (default is 42 bytes)
uint16_t fifoCount;     // count of all bytes currently in FIFO
uint8_t fifoBuffer[64]; // FIFO storage buffer

// orientation/motion vars
Quaternion q;   // [w, x, y, z]         quaternion container
VectorInt16 aa; // [x, y, z]            accel sensor measurements
VectorInt16
    aaReal; // [x, y, z]            gravity-free accel sensor measurements
VectorInt16
    aaWorld; // [x, y, z]            world-frame accel sensor measurements
VectorFloat gravity; // [x, y, z]            gravity vector
float euler[3];      // [psi, theta, phi]    Euler angle container
float
    ypr[3]; // [yaw, pitch, roll]   yaw/pitch/roll container and gravity vector

bool task_reset_fifos_flag = true;

EventGroupHandle_t FifoResetEventGroup = xEventGroupCreate();
EventBits_t uxBits = xEventGroupSetBits(FifoResetEventGroup, BIT_0);

// char all_readings_char[SENSOR_COUNT*201];

// reading all_readings[SENSOR_COUNT];

void setup_i2c(int sda, int scl) {
  Wire.begin(sda, scl);
  Wire.setClock(400000);
}

// Select I2C BUS
void tca_select(uint8_t bus) {
  Wire.beginTransmission(0x70); // tca_select address
  Wire.write(1 << bus);         // send byte to select bus
  Wire.endTransmission();
}

void select_sensor(int id) {
  // Serial.println(sensor_presence[id]);
  tca_select(sensor_presence[id]);
}

bool mpu_present() {
  Wire.beginTransmission(0x68);
  byte error;
  error = Wire.endTransmission();
  // Serial.println((int) error);
  return (error == 0);
}

int setup_sensor(int id) {
  Serial.print("Setting up Sensor: ");
  Serial.println(id);

  select_sensor(id);

  if (!mpu_present()) {
    Serial.println("Nothing there.");
    sensor_presence[id] = -1;
    return 1;
  }

  MPU6050 mpu = Sensors[id];
  mpu.initialize();

  Serial.println(F("Testing device connections..."));
  Serial.println(mpu.testConnection() ? F("MPU6050 connection successful")
                                      : F("MPU6050 connection failed"));

  // verify connection

  // load and configure the DMP
  Serial.println(F("Initializing DMP..."));
  devStatus = mpu.dmpInitialize();
  // supply your own gyro offsets here, scaled for min sensitivity
  mpu.setXAccelOffset(
      mpu_offsets[id].xa); // 1688 factory default for my test chip
  mpu.setYAccelOffset(
      mpu_offsets[id].ya); // 1688 factory default for my test chip
  mpu.setZAccelOffset(
      mpu_offsets[id].za); // 1688 factory default for my test chip
  mpu.setXGyroOffset(mpu_offsets[id].xg);
  mpu.setYGyroOffset(mpu_offsets[id].yg);
  mpu.setZGyroOffset(mpu_offsets[id].zg);

  // make sure it worked (returns 0 if so)
  if (devStatus == 0) {
    // turn on the DMP, now that it's ready
    Serial.println(F("Enabling DMP..."));
    mpu.setDMPEnabled(true);

    // get expected DMP packet size for later comparison
    packetSize = mpu.dmpGetFIFOPacketSize();
    // sensor_presence[id] = true;
  } else {
    // ERROR!
    // 1 = initial memory load failed
    // 2 = DMP configuration updates failed
    // (if it's going to break, usually the code will be 1)
    Serial.print(F("DMP Initialization failed (code "));
    Serial.print(devStatus);
    Serial.println(F(")"));
    sensor_presence[id] = -1;
    return 1;
  }

  return 0;
}

void setup_sensors() {
  if (RIGHT_HAND != 1) {
    sensor_presence[0] = 0;
    sensor_presence[1] = 1;
    sensor_presence[2] = 2;
    sensor_presence[3] = 3;
    sensor_presence[4] = 4;
    sensor_presence[5] = 5;
  } else {
    sensor_presence[0] = 4;
    sensor_presence[1] = 3;
    sensor_presence[2] = 2;
    sensor_presence[3] = 1;
    sensor_presence[4] = 0;
    sensor_presence[5] = 5;
  }

  for (int i = 0; i < SENSOR_COUNT; i++) {
    if (setup_sensor(i)) {
      Serial.println("--------WARNING: A SENSOR FAILED-------");
    }
  }
}

void reset_all_bufs() {
  for (int i = 0; i < SENSOR_COUNT; i++) {
    if (sensor_presence[i] != -1) {
      // Serial.print("Resetting sensor: ");
      // Serial.println(i);
      select_sensor(i);
      Sensors[i].resetFIFO();
    }
  }
}

void task_fifo_reset(void *pvParameters) {
  const TickType_t xTicksToWait = 100 / portTICK_PERIOD_MS;
  for (;;) {
    if (xEventGroupWaitBits(FifoResetEventGroup, BIT_0, pdFALSE, pdTRUE,
                            xTicksToWait) == pdPASS) {
      reset_all_bufs();
      xEventGroupClearBits(FifoResetEventGroup, BIT_0);
    } else {
      Serial.println("Something went wrong waiting for events");
    }
  }
}

void readFifoBuffer(MPU6050 mpu) {

  // Serial.println("Reading fifo buffer...");
  // Clear the buffer so as we can get fresh values
  // The sensor is running a lot faster than our sample period

  __TIMING("after reset: %d \n");

  if (MULT_CORE) {
    uxBits = xEventGroupGetBits(FifoResetEventGroup);
    while ((uxBits & BIT_0) != 0) {
      uxBits = xEventGroupGetBits(FifoResetEventGroup);
    }
  }

  __TIMING("Before get: %d \n");

  // get current FIFO count
  fifoCount = mpu.getFIFOCount();

  __TIMING("after get: %d \n");

  // wait for correct available data length, should be a VERY short wait
  while (fifoCount < packetSize)
    fifoCount = mpu.getFIFOCount();

  __TIMING("before bytes: %d \n");

  // read a packet from FIFO
  mpu.getFIFOBytes(fifoBuffer, packetSize);

  __TIMING("after bytes (t) : %d \n");
}
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

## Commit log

2023-11-02 Initial commit. Schematic for sensor unit started
    [sensor.kicad_pcb, sensor.sch]
2023-11-02 Delayed commit. First working version, including firmware logging data
    [CH340C.step, DM3AT-SF-PEJM5.step, EDI2CAP.CFG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]
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2023-11-02 broke out and refactored code
    [battery.cpp, config.h, filename.cpp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]
2023-11-02 New repository structure to incorporate non-embedded software
    [CH340C.step, DM3AT-SF-PEJM5.step, EDI2CAP.CFG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]
2023-11-18 Added collective reset of all FIFO buffers before attempting to read, going from right to left
    [sensors.cpp]
2023-11-18 Reset of all FIFO bufs now ltr again
    [sensors.cpp]
2023-11-18 Added parallelization framework. Crashes because of unfed watchdog
    [main.cpp, sensors.cpp]
2023-11-18 Fixed flag issues with EventGroups
    [main.cpp, sensors.cpp]
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2023-11-19 Added picture of prototype to README
    Made the concept drawing smaller and added a picture of the protoype
    next to it as a sort of side-by-side comparison to show the current
    status better and prettifying the README.
2023-12-17 Abstracted button checks
    This change adds an abstraction `onButtonClick` for the classical
    button clicked, do action combination.
2024-02-03 Changed build partition to min_spiffs.csv
    Adding the BLESerial library made the program to big so pio threw an error. This could be fixed by changing the partition config to min_spiffs.csv, which reduces the size allocated for a file system and therefore increased available program-size, as the ESP32 probably just has 4mb of flash memory.
2024-02-03 Added support for 16MB flash size
    The ESP32-WROOM-32E-N16 does have 16MB of flash and with this change these are actually available without causing the ESP to crash, which was cause to doubt the flash size before.
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2024-02-03 Added optional break if sensor fails
    [main.cpp]
2024-02-09 Adding second offset array to config.h
    As a second glove will have different sensors on it, just switching the order isn't sufficient so a second array, also in the order of Thumb - Pinky with the onboard sensor last is added here.
2024-02-09 Actually switching the order of the sensors
    The Sensors array and everything keeps it's order, but the sensor_presence array now stores the channel on which the sensor is and a -1 if it's missing.
    The function tca_select is further abstracted in this file now, by a new function select_sensor which first gets the channel from the array by id.
    The presence checks were replace by a comparison with -1.
    Another function was added: A setup_senors function which is called in main.cpp which fills the sensor_presence array with the appropriate channel depending on the RIGHT_HAND variable and then sets up the sensors in the standard order.
    [main.cpp, sensors.cpp]
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2024-02-15 Add script for logging micros of mobo and computer time
    Using `pio device monitor | grep -E -o --line-buffered "(^[0-9]+:)" | ../../../Software/tools/keylogging/logging.sh | tee -a comparing-timing.log` in the `Hardware/Firmware/mainboard` directory this 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
2024-02-15 Side by side comparison of timestamps
    Set of value pairs the timestamp on the host computer being collected as each line comes in on the serial monitor.
    There is also a simple evaluation script that prints the mean and then standard deviation of the microseconds, which is less than 1ms.
2024-02-15 Keylogging script added
    Collect the filtered output from the QMK driven keyboard using `./hid_listen | grep -E --line-buffered "(0x[A-F0-9]+,)?[0-9]+,[0-9]+,[0-9]{1,2}"` and adds the timestamp given by `date +s%N`.
    This script required the program hid_listen to be executable in the same folder and then continuously appends to keylog.csv
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2024-02-18 New KicAD version with changed files
    [motherboard.kicad_pcb, motherboard.kicad_sch, sensor.csv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]
2024-03-01 Added conversion script for keylogger output
    The aim is to translate the keylogger's output into the same format of
    the virutal keyboard.
    This is a first framework with the translation and output function
    missing.
2024-03-01 Documentation updates (#35)
    * Moved pictures to new images folder
    * Adding data folder for collected datasets
    * Adding webpages folder with two websites printed to pdf
    * Reverting webpages and data folder addition
    This reverts commit 513af0b638e81bd35da1c43c63645ae0be84f067 and
    e5f14b9c60bcb5304f2e2aae4c3e6bdbffd16a22.
    * Added gitignore for data folder
    * Ignore zip files (get used for images) in Documentation folder
2024-03-13 Provisoric transmission over BLE Serial
    Build flag works, but doesn't exclude the BLESerial library when not
    needed.
    [config.h, main.cpp]
2024-03-18 Build flag BLE_SERIAL fully functional
    Build flag is now functional and if not set, the library is not
    included.
    The library is now also added via platformio.ini instead of locally.
    The `ble.begin()` call includes the options that enable the builtin led
    (pin 13), and name the device "lapcal [left/right]" depending on the
    hand set.
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2024-03-19 Fix keylogger script
    - fixed functions to act on single record instead of a list
    - print timestamp
2024-03-19 Fix type conversion in prepare_dataset
    Python evaluates `bool("0")` und `bool("1")` zu `True`. Gewünscht ist
    jedoch `bool("0") == False`, dies erhalten wir mit `bool(int("0"))`.
2024-03-23 Relocate tools into proposed structure
    As proposed in #49 the currently available tools were relocated to
    their respective new semantic location. Some draft nix files that are
    also included.
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2024-03-25 Timestamp output from mobo now in unix time
    Instead of outputting the microseoconds since boot, the full
    unix_timestamp is now used in inaccurate microseocond resolution since
    only millisconds are read from ntp server.
2024-04-25 First draft of all rings
    Created a ring module that takes the finger diameter and optionally a
    tolerence and an angle at which the center of the hole is shifted to.
    With this five rings for each individual finger were added easily. What
    is missing are the fillets and correct parameters.
    Another thing that could be improved is the way the SenseUnit slot is
    attached to the ring. When the diameter of the outer contour of the ring
    is smaller than the width of SenseUnit and the walls there are edges on
    the ring.
    [rings.scad]
2024-04-27 Finished working prototype version of the live plotting utility
    This commit is way too big, but to outline what it does:
    - interact with the shell to scan bluetooth devices (using ble-scan)
    and activate the ble-serial interface.
    - implemented a basic feedback message box which supports disappearing
    messages
    - implemented a basic parser for the output of the hardware
    - provide selection gui to select which value to plot and use
    threading to plot from the ble-serial port in the background
2024-04-27 Fix parser
    The parser did not check the length of the sensor string. With this
    check in place now, the app should stop crashing on faulty sensors.
2024-05-01 Created CAD folder and add fillets to hole ends
    [rings.scad]
2024-05-01 Add simple configuration mechanism
    This commit does a few things:
    1. Introduce `configuration.rkt` which handles all the logical
    structure concerning configuration management. It provides
    `load-config` and `write-config` to load and write configurations
    to a provided file path. Additionally, is provides
    `generate-default-config` and `get-attribute`; the former is only
    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
2024-05-10 Added thumb hole parameters for customizer
    [rings.scad]
2024-05-10 Removed old version
    [rings.scad]
2024-05-10 Moved CAD folder to top level
    [rings.scad]
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2024-05-12 Relocate READMEs to respective directory
    Module documentation should be local to their respective
    directories. Before it was all collected in the `lib/` directory which
    has sub folders for every framework it provides modules for. The
    framework specific module documentation was moved to these sub folders.
2024-05-12 Link to directory instead of README
    The references to the framework specific modules pointed to the
    READMEs but they should point to the folder the modules are contained in.
2024-05-12 Add first draft of model structure
    This is the current idea on how to structure the models.
    Only problem with current design is the ugly way we load the libraries.
2024-05-12 Add current shell.nix file (possibly not working)
    Current draft for the shell.nix file.
2024-05-19 Tolerance actually affects size now and is roughly adjusted
    [rings.scad]
2024-05-23 Fix buggy pen thickness
    When changing the size of the canvas buffer, sometimes the pen
    thickness would arbitrarily double. It turns out that the `on-paint`
    callback is called when another such callback has yet to finish.
    To fix this we associate a default pen with the component on the first
    `on-paint` callback and continue using that pen instead of retaining
    the current pen in every callback.
2024-09-02 Restructure source code and add command line arguments
    Source code is now separated into two subfolders:
    - `src`, which contains all the regular code until now, and
    - `test`, which is currently empty (and thus not in the git
    repository) which will encapsulates future tests.
    Further, a starting script `run.sh` was added along with support for
    command-line arguments:
    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
2024-10-12 Added BLE build flag and removed BLE-SERIAL
    If BLE build flag is not set, values are printed on serial monitor.
2024-11-03 Fix bugs in `ble-serial.rkt`
    Fixed some minor edge case bugs that disabled ui elements even though
    they should still be available. Also added some more comments.
2024-11-18 ble-receiver: added -n/--name to connect to device by name
    Does a scan to find the device addresss by name and connects to it.
2024-11-18 Firmware: Start advertising on disconnect
    Advertising (showing up and able to be connected to as a BLE device) is
    now started again after a disconnect. Now the device doesn't need to be
    reset after a ble disconnect, but can be immediately be connected to
    again.
    [ble-utils.cpp]
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
